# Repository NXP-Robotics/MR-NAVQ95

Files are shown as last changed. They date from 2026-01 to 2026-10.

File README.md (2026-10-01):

# NXP NavQ95 Vehicle Computer

Welcome to the documentation for the NavQ95, a vehicle computer reference design designed around the NXP i.MX95 developed by NXP Mobile Robotics. Please note that this board is currently a Proof of Concept only and is considered not supported by NXP.

The NavQ95 features a single main board with a small form factor and is designed to merge a Vehicle Management Unit and a Vehicle Companion Computer into one unified, heterogeneous MCU/MPU device.

> [!TIP]
> See [MR-NAVQ95/Mr Solutions MR-MR-NAVQ95-RevB description slides (Public).pdf](<https://github.com/NXP-Robotics/MR-NAVQ95/blob/main/Mr Solutions MR-NavQ95-RevB description slides (Public).pdf>) also for a short overview presentation.

MR-NavQ95 Top view     |  MR-NavQ95 Side View
:-------------------------:|:-------------------------:
  |  

# Core Architecture & AI

The heterogeneous vehicle computer is powered by the [NXP i.MX 95](https://www.nxp.com/products/i.MX95) processor and is divided into specific execution domains:
- **Compute**: 6x Arm Cortex-A55 cores dedicated to executing compute-intense functions.
- **Real-Time Control**: 1x Arm Cortex-M7 core to execute real-time control tasks.
- **System Management**: 1x Arm Cortex-M33 core to execute the NXP System Manager.

## AI Capabilities:

- Equipped with an on-chip NXP Neutron NPU.
- High-bandwidth M.2 PCIe interfaces target up to 2 [NXP Kinara Ara240 NPUs](https://www.nxp.com/products/ARA240).
- Supports cloud-based AI via Wifi6 or 5G connectivity

## Software Stack:

The board is designed to run open-source software, leveraging its multi-core architecture:

- Cortex-A55 Cores: Runs the Ubuntu PoC image 24.04 with ROS2 Jazzy.
> [!NOTE]
> This is an open Proof of Concept (POC) design and is not officially supported by NXP.
> The design is enabled with a Vanilla Ubuntu POC layered on top of existing NXP Yocto build.
> This means ROS2 main installs via `apt install ros2`.
>
> The unsupported software repo can be found here: https://github.com/NXP-Robotics/imx-manifest-navq95
- Cortex-M7 Core: Runs either Zephyr / CogniPilot or NuttX / PX4.
- Communication: High-speed inter-core communication is facilitated using shared memory / OpenAMP RpMsg.

### Cortex-M7 realtime software
A range of software platforms can be deployed on the Cortex-M7 core. The following software platforms have been prepared for use with the MR‑NAVQ95:
- Zephyr
  - https://www.zephyrproject.org/
  - https://github.com/CogniPilot/zephyr_boards/
- CogniPilot Cerebri (Zephyr based)
  - https://CogniPilot.org/
- NuttX
  - https://NuttX.apache.org/
  - https://NuttX.apache.org/docs/latest/platforms/arm/imx9/boards/mr-navq95b/index.html
- PX4 Autopilot (NuttX based)
  - https://px4.io/

## Hardware Specifications

### Power and Memory
* **Input Power:** Supports an operating voltage range of 9V to 52V, with a maximum limit of 60V. This easily accommodates 3S to 12S battery configurations, delivering 60W across the 9-20V (3-7S) range, and stepping up to 125W for the 20-52V (8-12S) range.
* **RAM:** Up to 16 GB of LPDDR5 memory.
* **Storage Options:** 64 GB onboard eMMC, an Octal-SPI Flash module, a Micro SD card reader, and PCIe M.2 support for solid-state drives.

### Connectivity
* **Standard Ethernet:** One Gigabit RJ45 port supporting Precision Time Protocol (PTP).
* **Automotive Ethernet:** Both 100BASE-T1 and 1000BASE-T1 ports, also featuring PTP.
> [!TIP]
> 100(0)BASE-T1 is Ethernet over single unshielded twisted pair
* **Wireless Comms:** Powered by the NXP IW612 chip for Wi-Fi, Bluetooth, and Matter support.
* **Cellular Data:** Includes a SIM slot and an M.2 PCIe interface meant for a cellular modem.

### Onboard Mobile Robotics Sensors
* TDK ICM-45686 Inertial Measurement Unit (IMU)
* Bosch BMM350 Magnetometer
* Bosch BMP581 Barometer

### Physical Interfaces
* USB 2.0 and 3.0 ports.
* Two PCIe M.2 slots (Type M and Type B).
* A 10-pin JTAG SWD debugging header.

## Main Board Schematics

The MR-NAVQ95 Main Board serves as the central processing and power distribution hub for the platform. It handles the core i.MX95 compute, wide-input power delivery, and routing to all board-to-board and high-speed interfaces. 

For detailed component layouts, pin configurations, and electrical routing, refer to the core system schematics:
* [NAVQ95-MAIN](Schematic/SPF-97010_A1-MAIN.pdf)

## Expansion Capabilities

Building upon this core Main Board, the system is highly adaptable thanks to support for modular add-on boards:

**XGMII-based Networking expansion boards:** 
* [NAVQ95-T1SW](Schematic/SPF-97011_A1-T1SW.pdf): T1 Switch utilizing the NXP SJA1110 for six 100BASE-T1 connections and 2x 1000BASE-T1.
* [X-MR-NAVQ95E-T1P](Schematic/Prototypes/Schematic-Rev-A/SPF-96098_A-T1PHY.pdf): T1 Single Phy setup using the NXP TJA1103.

**CSI/DSI Vision / Camera expansion board:** 
* [NAVQ95-CAMRP](Schematic/SPF-97012_A1-CAMRP.pdf): A 22-pin Raspberry Pi-style connector expansion board for CSI/DSI interfaces.

**General purpose I/O expansion board:**
* [NAVQ95-IO](Schematic/SPF-97013_A1-IO.pdf): Drone & Rover IO: Uses standard Dronecode connectors for extensive peripheral support:
    * 3x CAN-FD
    * Bosch BMI088 IMU
    * 8x FlexIO/PWM output
    * Dronecode JST-GH 10-pin GPS connector
    * Dronecode JST-GH 6-pin Telemetry connector
    * Dronecode JST-GH 4-pin I2C connector
    * WM8962B Audio codec with:
        * Audio jack
        * 2x PDM Microphones
        * 2x 1W stereo output
    * 2x UART to USB-C for Serial Console

## MR-NAVQ95 hardware connector reference

Each card shows three things per pin: the **function**, the **net name in the schematic** and the
**i.MX95 pad** the signal ends up on. Parts in between, such as transceivers, level shifters and
I/O expanders, are shown too. Pin 1 is the square pad.

## Board overview

<!-- overview:top -->
<picture>
  <source media="(prefers-color-scheme: dark)" srcset="images/overview-top-dark.svg">
  MR-NAVQ95 top view with connector callouts
</picture>
<!-- /overview -->

<!-- overview-list:top -->
Not visible here: [J13 USB1](#main-other-connectors) (bottom view) · [J12 USB2](#main-other-connectors) (bottom view) · [J16 M.2 KEY B](#main-j16-m2-key-b) (bottom and front view) · [J7 DEBUG](#main-j7-debug) (front view) · [J6 MICROSD](#main-other-connectors) (front view) · [J11 RTC_BAT](#main-j11-rtc_bat) (not visible in the photos) · [SW2 BTMODE](#buttons-and-switches) (top side, under the M.2 Key M module)
<!-- /overview-list -->

> [!NOTE]
> The boot-mode switch (SW2) is explained in the
> [imx-manifest-navq95 README](https://github.com/NXP-Robotics/imx-manifest-navq95#power-up-navq95).

Front view. The JST-GH connectors of the IO board are on top. Below them, on the edge of the
main board, are the debug header, the microSD slot, the SIM holder and the M.2 Key B slot:

<!-- overview:side -->
<picture>
  <source media="(prefers-color-scheme: dark)" srcset="images/overview-side-dark.svg">
  MR-NAVQ95 front view: IO board connectors, debug header, microSD and audio jack
</picture>
<!-- /overview -->

Bottom side. In this photo the T1 Ethernet switch board and two camera boards are fitted. The
left camera board is on the CSI_B2B port, the right one on the DSICSI_B2B port; only the
DSICSI_B2B port can also drive an RPi DSI display. PORT1 to PORT10 are the switch ports:

<!-- overview:bottom -->
<picture>
  <source media="(prefers-color-scheme: dark)" srcset="images/overview-bottom-dark.svg">
  MR-NAVQ95 bottom view with connector callouts
</picture>
<!-- /overview -->

<!-- overview-list:bottom -->

<!-- /overview-list -->

## Connector index

<!-- index -->
| Ref | Function | Connector | Details |
|---|---|---|---|
| [Main J1](#main-j1-m2-key-m) M.2 KEY M | M.2 Key M slot, PCIe x1 (NPU or NVMe SSD) | M.2 Socket 3 Key M, 2242 / 2280 standoffs, 3.3 V up to 3.5 A |  |
| [Main J2](#main-j2-console) CONSOLE | UART1 (Linux console) and UART2 (M7 console) header, DS-009 TELEM layout | JST-GH 1x6 (SM06B-GHS-TB) |  |
| [Main J3](#main-other-connectors) B2B | Board-to-board expansion headers | Board-to-board headers | J3/J4 B2B_IO1/IO2 (2x25) for the IO board, J14/J15 B2B_CSI/DSICSI (2x20) for the camera boards, J17 B2B_ETH (2x25) for the T1 boards. Pin lists are on schematic page 25. |
| [Main J5](#main-j5-sim) SIM | SIM card holder for the Key B modem slot | SIM card holder, 6 contacts + card-detect switch, bottom side |  |
| [Main J6](#main-other-connectors) MICROSD | microSD card slot (USDHC2) | microSD push-push, bottom side | USDHC2. The board can boot from it when the boot-mode switch selects SD. |
| [Main J7](#main-j7-debug) DEBUG | SWD / JTAG debug header (Arm Cortex 10-pin) | 2x5 1.27 mm (Samtec SHF-105-01-L-D-RA) |  |
| [Main J8](#main-other-connectors) ENET1 | Gigabit Ethernet with PTP | RJ45 with magnetics (Abracon ARJM11D7) | RTL8211 PHY on i.MX95 ENET1, supports IEEE 1588 PTP. |
| [Main J9](#main-j9-pwr_in) PWR_IN | Power input 9-52 V (3S-12S battery) | Molex Micro-Fit 3.0 2-pin (0430450222) |  |
| [Main J11](#main-j11-rtc_bat) RTC_BAT | RTC backup battery (rechargeable ML2020, RPi 5 compatible) | JST-SH 1.0 mm 2-pin (SM02B-SRSS-TB), top entry |  |
| [Main J12](#main-other-connectors) USB2 | USB 2.0 Type-C host port | USB Type-C receptacle, bottom side | Host port. 5 V VBUS through an NX20P0477 load switch with over-current protection. |
| [Main J13](#main-other-connectors) USB1 | USB 3.0 Type-C, serial download / device port | USB Type-C receptacle, bottom side | Serial-download port of the i.MX95 boot ROM and the port the NavQ95 flasher uses. USB 3.0 and USB 2.0 are both connected. |
| [Main J16](#main-j16-m2-key-b) M.2 KEY B | M.2 Key B slot, PCIe x1 with SIM (cellular modem) | M.2 Socket 2 Key B / B+M, 2242 / 3042 / 3052 standoffs, bottom side, 3.3 V up to 5 A |  |
| [Main J18](#main-other-connectors) ANT0/ANT1 | Wi-Fi 6 / Bluetooth antennas (IW612), ANT0 = J18, ANT1 = J19 | 2x U.FL | ANT0 = J18, ANT1 = J19. IW612 Wi-Fi 6, Bluetooth and 802.15.4. |
| [IO J1](#io-j1-console) CONSOLE | USB-C console: CP2105 bridge, UART1 = Linux, UART2 = M7 | USB Type-C receptacle (USB 2.0 device) |  |
| [IO J2](#io-j2-spkr) SPKR | Stereo speaker output (WM8962B class-D, 2x 1 W) | JST-PH 2.0 mm 1x4 |  |
| [IO J3](#io-j3-can3) CAN3 | CAN FD 3 (TJA1463) | JST-GH 1x4, side entry |  |
| [IO J4](#io-j4-can2) CAN2 | CAN FD 2 (TJA1463) | JST-GH 1x4, side entry |  |
| [IO J5](#io-j5-can1) CAN1 | CAN FD 1 (TJA1463) | JST-GH 1x4, side entry |  |
| [IO J6](#io-j6-telem) TELEM | Telemetry UART7 with flow control | JST-GH 1x6, top entry |  |
| [IO J7](#io-j7-i2c) I2C | I2C6 peripheral connector | JST-GH 1x4, top entry |  |
| [IO J8](#io-j8-gps) GPS | GPS: UART5, I2C6, safety switch, LED, buzzer | JST-GH 1x10, side entry |  |
| [IO J9](#io-j9-pwm) PWM | 8x PWM / timer outputs (TPM3 to TPM6), also usable as FlexIO1 pins | JST-GH 1x10, side entry |  |
| [IO J12](#io-j12-audio) AUDIO | 3.5 mm headset jack, CTIA wiring (WM8962B headphone out + microphone in) | 3.5 mm 4-pole TRRS jack with insertion switch, board underside |  |
| [CAM J3](#cam-j3-csi) CSI | MIPI CSI-2 camera, 4 data lanes, RPi camera compatible | 22-pin 0.5 mm FPC/FFC, contacts away from the PCB |  |
| [CAM J4](#cam-j4-5v) 5V | 5 V header for a display (not fitted) | 1x3 2.54 mm right-angle header, not fitted |  |
| [T1S J2](#t1s-ports-and-headers) DEBUG | Debug header of the SJA1110 (Arm Cortex-M7 inside the switch) | 2x5 1.27 mm | Not the i.MX95 debug port; that is J7 on the main board. |
| [T1S J3](#t1s-ports-and-headers) PORT2 | 1000BASE-T1 port 2 | Single-pair automotive connector | TJA1120 PHY on SJA1110 SGMII port 2. |
| [T1S J4](#t1s-ports-and-headers) PORT1 | 1000BASE-T1 port 1 | Single-pair automotive connector | TJA1120 PHY on SJA1110 SGMII port 1. |
| [T1S J5](#t1s-ports-and-headers) PORT5 | 100BASE-T1 port 5 | 2-pin single-pair connector | SJA1110 internal 100BASE-T1 PHY, switch port 5. |
| [T1S J6](#t1s-ports-and-headers) PORT6 | 100BASE-T1 port 6 | 2-pin single-pair connector | SJA1110 internal 100BASE-T1 PHY, switch port 6. |
| [T1S J7](#t1s-ports-and-headers) PORT7 | 100BASE-T1 port 7 | 2-pin single-pair connector | SJA1110 internal 100BASE-T1 PHY, switch port 7. |
| [T1S J8](#t1s-ports-and-headers) PORT8 | 100BASE-T1 port 8 | 2-pin single-pair connector | SJA1110 internal 100BASE-T1 PHY, switch port 8. |
| [T1S J9](#t1s-ports-and-headers) PORT9 | 100BASE-T1 port 9 | 2-pin single-pair connector | SJA1110 internal 100BASE-T1 PHY, switch port 9. |
| [T1S J10](#t1s-ports-and-headers) PORT10 | 100BASE-T1 port 10 | 2-pin single-pair connector | SJA1110 internal 100BASE-T1 PHY, switch port 10. |
<!-- /index -->

## Main board

<!-- heading:main/J9 -->
### Main J9 PWR_IN
<!-- /heading -->

<!-- pinout:main/J9 -->
<picture>
  <source media="(prefers-color-scheme: dark)" srcset="images/main-J9-dark.svg">
  Main J9 PWR_IN pinout
</picture>

Pin 1 (BATT +) is the lower pin on the board. Input 9 to 52 V, never more than 60 V. The board can draw 60 W between 9 and 20 V, and 125 W between 20 and 52 V. The input voltage is measured on ADC_IN0 (VIN / 64).
<!-- /pinout -->

<!-- heading:main/J2 -->
### Main J2 CONSOLE
<!-- /heading -->

<!-- pinout:main/J2 -->
<picture>
  <source media="(prefers-color-scheme: dark)" srcset="images/main-J2-dark.svg">
  Main J2 CONSOLE pinout
</picture>

Pins 2 to 5 follow the DS-009 TELEM layout for UART1: 2 = TX, 3 = RX, 4 = CTS, 5 = RTS. By default pin 4 carries UART2 RX and pin 5 UART2 TX (the M7 console). The same pads can be muxed to UART1 CTS and RTS instead, which gives UART1 full DS-009 flow control on this header. UART1 TX and UART2 TX are also the boot-mode straps BT_MODE0 and BT_MODE1. The same two UARTs are also on the USB console port J10 of the IO board, see the figure there.

> [!NOTE]
> UART1 TX and UART2 TX are boot straps. Keep them idle while the board resets, or it may boot from the wrong source.
<!-- /pinout -->

<!-- heading:main/J7 -->
### Main J7 DEBUG
<!-- /heading -->

<!-- pinout:main/J7 -->
<picture>
  <source media="(prefers-color-scheme: dark)" srcset="images/main-J7-dark.svg">
  Main J7 DEBUG pinout
</picture>

Standard Arm Cortex 10-pin layout (0.05 inch). Works with J-Link, PyOCD, CMSIS-DAP and similar probes. nRESET goes through a diode to SYS_RST_B, so the probe can only pull it low.

> [!NOTE]
> VTref is 1.8 V. Use a debug probe that supports 1.8 V targets.
<!-- /pinout -->

<!-- heading:main/J1 -->
### Main J1 M.2 KEY M
<!-- /heading -->

<!-- pinout:main/J1 -->
<picture>
  <source media="(prefers-color-scheme: dark)" srcset="images/main-J1-dark.svg">
  Main J1 M.2 KEY M pinout
</picture>

Only the pins below are connected. All other pins of the 75-pin socket are not used: PCIe lanes 1 to 3 (odd pins 5 to 37), SATA, DEVSLP, SUSCLK (pin 68, link resistor not fitted), MFG1/2 and the even pins 6 to 36. The 3.3 V comes through an NX20P5090 load switch that the I/O expander can switch off: 3.5 A continuous, 7 A peaks of 100 µs.

> [!NOTE]
> PCIe x1 only, no SATA. An NVMe SSD or NPU module works; a SATA M.2 drive does not.
<!-- /pinout -->

<!-- heading:main/J16 -->
### Main J16 M.2 KEY B
<!-- /heading -->

<!-- pinout:main/J16 -->
<picture>
  <source media="(prefers-color-scheme: dark)" srcset="images/main-J16-dark.svg">
  Main J16 M.2 KEY B pinout
</picture>

Made for a PCIe cellular modem. The USB 2.0 pins (7, 9) and the USB 3.0 / lane 1 pins (29 to 37) are not connected. SMBus (40, 42, 44), SUSCLK (68) and the Bluetooth coexistence lines COEX1/2 (64, 62, to the IW612) are routed, but their link resistors are not fitted. ANTCTL0 to 3, COEX3, DPR, DEVSLP, GPIO_3/4/8 and MFG1/2 are not connected. The UIM pins go to the SIM holder J5. The 3.3 V comes through an NX20P5090 load switch that the I/O expander can switch off: 5 A continuous, 6 A peaks of 100 µs.

> [!IMPORTANT]
> Buying a 4G or 5G modem? Get one that runs over PCIe. This slot has no USB pins, so a USB modem stays silent. Many modems exist in a USB and a PCIe version with the same name: check the exact SKU or the manual.
<!-- /pinout -->

<!-- heading:main/J5 -->
### Main J5 SIM
<!-- /heading -->

<!-- pinout:main/J5 -->
<picture>
  <source media="(prefers-color-scheme: dark)" srcset="images/main-J5-dark.svg">
  Main J5 SIM pinout
</picture>

Connected directly to the UIM pins of the Key B slot. The modem supplies the SIM voltage on UIM_PWR. The card-detect switch pulls SIM_DETECT low when a card is inserted. All contacts have ESD protection.
<!-- /pinout -->

<!-- heading:main/J11 -->
### Main J11 RTC_BAT
<!-- /heading -->

<!-- pinout:main/J11 -->
<picture>
  <source media="(prefers-color-scheme: dark)" srcset="images/main-J11-dark.svg">
  Main J11 RTC_BAT pinout
</picture>

Keeps the PCF2131 real-time clock running while the board has no power. The battery is charged slowly from the 3.3 V rail. This suits a rechargeable ML2020 cell such as the [RPi RTC Battery](https://www.raspberrypi.com/products/rtc-battery/).

> [!WARNING]
> Use a rechargeable ML2020 cell only. A CR2032 or other non-rechargeable cell must not be fitted: the board tries to charge it.
<!-- /pinout -->

<!-- others:main -->
### Main other connectors

| Ref | Function | Connector | Notes |
|---|---|---|---|
| J13 USB1 | USB 3.0 Type-C, serial download / device port | USB Type-C receptacle, bottom side | Serial-download port of the i.MX95 boot ROM and the port the NavQ95 flasher uses. USB 3.0 and USB 2.0 are both connected. |
| J12 USB2 | USB 2.0 Type-C host port | USB Type-C receptacle, bottom side | Host port. 5 V VBUS through an NX20P0477 load switch with over-current protection. |
| J8 ENET1 | Gigabit Ethernet with PTP | RJ45 with magnetics (Abracon ARJM11D7) | RTL8211 PHY on i.MX95 ENET1, supports IEEE 1588 PTP. |
| J6 MICROSD | microSD card slot (USDHC2) | microSD push-push, bottom side | USDHC2. The board can boot from it when the boot-mode switch selects SD. |
| J18 ANT0/ANT1 | Wi-Fi 6 / Bluetooth antennas (IW612), ANT0 = J18, ANT1 = J19 | 2x U.FL | ANT0 = J18, ANT1 = J19. IW612 Wi-Fi 6, Bluetooth and 802.15.4. |
| J3 B2B | Board-to-board expansion headers | Board-to-board headers | J3/J4 B2B_IO1/IO2 (2x25) for the IO board, J14/J15 B2B_CSI/DSICSI (2x20) for the camera boards, J17 B2B_ETH (2x25) for the T1 boards. Pin lists are on schematic page 25. |
<!-- /others -->

## IO expansion board

<!-- heading:io/J1 -->
### IO J1 CONSOLE
<!-- /heading -->

<!-- notes:io/J1 -->
A Silicon Labs CP2105 gives two serial ports on one USB-C connection. On a Linux host they appear as ttyUSB0 (UART1, Linux console) and ttyUSB1 (UART2, M7 console). RX and TX LEDs for both UARTs sit next to the connector. The same two UARTs also go to the J2 header on the main board, see the figure below.

> [!NOTE]
> Port 1 (ECI) is the Linux console, port 2 (SCI) is the M7 console. Do not let the host drive the TX lines while the board resets.
<!-- /notes -->

<!-- figure:console-shared -->
<picture>
  <source media="(prefers-color-scheme: dark)" srcset="images/figure-console-shared-dark.svg">
  UART1 and UART2 are shared between the J2 header and the CP2105 USB bridge
</picture>
<!-- /figure -->

<!-- heading:io/J6 -->
### IO J6 TELEM
<!-- /heading -->

<!-- pinout:io/J6 -->
<picture>
  <source media="(prefers-color-scheme: dark)" srcset="images/io-J6-dark.svg">
  IO J6 TELEM pinout
</picture>

The 5 V output is filtered (VDD_CON_UART_5V0) and has ESD protection.
<!-- /pinout -->

<!-- heading:io/J8 -->
### IO J8 GPS
<!-- /heading -->

<!-- pinout:io/J8 -->
<picture>
  <source media="(prefers-color-scheme: dark)" srcset="images/io-J8-dark.svg">
  IO J8 GPS pinout
</picture>

Standard DS-009 GPS and compass connector. The safety switch input (ARM_IO) is also wired to the ARM button SW1 on the board, and the LED output drives the LED in the switch. The buzzer pin is switched by an N-FET (AO3400A) driven from TPM6_CH1. A buzzer on the board is connected in parallel. DIP switch S1 sits between TPM6_CH1 and the FET: with S1 OFF both buzzers are disconnected and TPM6_CH1 is free for PWM8 on the PWM header.
<!-- /pinout -->

<!-- heading:io/J7 -->
### IO J7 I2C
<!-- /heading -->

<!-- pinout:io/J7 -->
<picture>
  <source media="(prefers-color-scheme: dark)" srcset="images/io-J7-dark.svg">
  IO J7 I2C pinout
</picture>

Same I2C6 bus as the GPS connector.
<!-- /pinout -->

<!-- heading:io/J9 -->
### IO J9 PWM
<!-- /heading -->

<!-- pinout:io/J9 -->
<picture>
  <source media="(prefers-color-scheme: dark)" srcset="images/io-J9-dark.svg">
  IO J9 PWM pinout
</picture>

Pin 1 (VDD_CON_PWM) is the servo power rail. It is linked to the board 5 V through R60 (0 Ω, not fitted) and measured on ADC_IN6 (VDD_CON_PWM / 8, up to 12 V). The outputs are 3.3 V logic with ESD protection. PWM8 (pin 9) also drives the buzzer. Every output pad can also be muxed to FlexIO1, for example for DShot or other custom timing protocols. Pins 2 and 5 can also be CAN4 or LPUART6 (TX and RX), pins 8 and 9 CAN5 or LPI2C5 (no pull-ups on the board). CAN4 and CAN5 need an external transceiver.

> [!WARNING]
> Do not put more than 5 V on the servo rail (pin 1) while R60 is fitted.

> [!TIP]
> Need all eight PWM outputs? Switch DIP switch S1 (BUZZER) off. It frees PWM8 from the buzzer.
<!-- /pinout -->

<!-- heading:io/J5 -->
### IO J5 CAN1
<!-- /heading -->

<!-- pinout:io/J5 -->
<picture>
  <source media="(prefers-color-scheme: dark)" srcset="images/io-J5-dark.svg">
  IO J5 CAN1 pinout
</picture>

TJA1463 CAN FD transceiver with 5 V supply. The 120 Ω split termination is on the board, so each CAN port is a bus end. CANH and CANL together form the differential bus. TXD and RXD are the logic pins of the transceiver and go to the FlexCAN pads of the i.MX95. The transceiver enable and standby pins are controlled through the PCAL6524 I/O expander.
<!-- /pinout -->

<!-- heading:io/J4 -->
### IO J4 CAN2
<!-- /heading -->

<!-- pinout:io/J4 -->
<picture>
  <source media="(prefers-color-scheme: dark)" srcset="images/io-J4-dark.svg">
  IO J4 CAN2 pinout
</picture>

Same circuit as CAN1, with the 120 Ω termination.
<!-- /pinout -->

<!-- heading:io/J3 -->
### IO J3 CAN3
<!-- /heading -->

<!-- pinout:io/J3 -->
<picture>
  <source media="(prefers-color-scheme: dark)" srcset="images/io-J3-dark.svg">
  IO J3 CAN3 pinout
</picture>

Same circuit as CAN1, with the 120 Ω termination.
<!-- /pinout -->

<!-- heading:io/J12 -->
### IO J12 AUDIO
<!-- /heading -->

<!-- pinout:io/J12 -->
<picture>
  <source media="(prefers-color-scheme: dark)" srcset="images/io-J12-dark.svg">
  IO J12 AUDIO pinout
</picture>

Plug contacts listed from tip to sleeve. The switch in the jack drives HP_JD: high with a plug inserted, low without. The codec uses it to detect the plug. The headphone ground reference is the HP_FB sense line of the codec.

> [!NOTE]
> CTIA wiring only. OMTP headsets (microphone and ground swapped) do not work.
<!-- /pinout -->

<!-- heading:io/J2 -->
### IO J2 SPKR
<!-- /heading -->

<!-- pinout:io/J2 -->
<picture>
  <source media="(prefers-color-scheme: dark)" srcset="images/io-J2-dark.svg">
  IO J2 SPKR pinout
</picture>

Bridge-tied class-D outputs of the WM8962B codec. The 4-pin JST-PH plug of the [Adafruit 1669 Stereo Enclosed Speaker Set](https://www.adafruit.com/product/1669) (2x 3 W, 4 Ω) fits directly. J25 next to it is the headset jack; the board also has two PDM microphones.

> [!CAUTION]
> No GND on this connector. Each speaker goes between its − and + pin. Never connect a speaker pin to ground.
<!-- /pinout -->

<!-- others:io -->

<!-- /others -->

## Buttons and switches

<!-- switches -->
| Ref | Board | Function | Type | Notes |
|---|---|---|---|---|
| SW1 SYS_RST | Main | System reset button (short press: reset) | Tactile switch, right of the ON/OFF button, hidden under the thermal pad in the photo | Resets the whole board. |
| SW2 BTMODE | Main | Boot mode DIP switch | 4-position DIP switch, top side under the M.2 Key M module | See [Power up NavQ95](https://github.com/NXP-Robotics/imx-manifest-navq95#power-up-navq95). |
| SW3 ONOFF | Main | Power button (short press: on, 5 s press: off) | Tactile switch, left of the reset button | Talks to the PMIC ONOFF input. |
| S1 BUZZER | IO | Buzzer enable DIP switch | 1-position DIP switch (CHS-01TA1), next to the ARM button | ON connects TPM6_CH1 to the buzzer FET. OFF disconnects the buzzer and the GPS buzzer pin, so PWM8 on the PWM header is a free channel. |
| SW1 ARM | IO | Arm / safety switch with LED | Tactile switch | Wired in parallel with the safety-switch and LED pins of the GPS connector. |
| S1 SMI | T1S | SMI routing switch | 1-position DIP switch (CHS-01TA1) | Leave as delivered. Only used when the SJA1110 runs without the host. |
| S2 BOOT_OPT | T1S | SJA1110 boot option switch | 2-position DIP switch | Boot option of the SJA1110; see the SJA1110 documentation before changing it. |
<!-- /switches -->

## Camera expansion board

<!-- heading:cam/J3 -->
### CAM J3 CSI
<!-- /heading -->

<!-- pinout:cam/J3 -->
<picture>
  <source media="(prefers-color-scheme: dark)" srcset="images/cam-J3-dark.svg">
  CAM J3 CSI pinout
</picture>

Pin-compatible with the 22-pin RPi camera connector (22-pin 0.5 mm same-side FFC). Two identical camera boards can be fitted. In the bottom view, the left one sits on CSI_B2B and goes to the i.MX95 MIPI_CSI1 port; the right one sits on DSICSI_B2B and goes to the second port, which is shared between DSI and CSI. The camera I2C is the i.MX95 I3C2 bus, shifted from 1.8 V to 3.3 V by a PCA9306. The two GPIO pins come from the I/O expander on the main board; the exact expander pins and the pad names of the second port were not traced. Whether a camera module works depends on the software image, not on the connector. J4 next to it is a 3-pin 5 V header for a display, not fitted.

> [!TIP]
> RPi camera modules fit directly with a standard 22-pin FFC. For an RPi DSI display use the camera board on the DSICSI_B2B port; the CSI_B2B port cannot drive a display.
<!-- /pinout -->

<!-- heading:cam/J4 -->
### CAM J4 5V
<!-- /heading -->

<!-- pinout:cam/J4 -->
<picture>
  <source media="(prefers-color-scheme: dark)" srcset="images/cam-J4-dark.svg">
  CAM J4 5V pinout
</picture>

Filtered 5 V from the system rail with ESD protection, meant for a DSI display on the DSICSI_B2B camera board. The silkscreen marks pin 1 as 5V.
<!-- /pinout -->

## T1 Ethernet switch board

The MR-NAVQ95E-T1S board is an NXP SJA1110 automotive Ethernet switch. It is connected to the
main board through B2B_ETH on SGMII port 4 of the switch (the host port). Ports 1 and 2 are
1000BASE-T1 through two TJA1120 PHYs on SGMII ports 1 and 2. Ports 5 to 10 are 100BASE-T1 on
the switch's own PHYs. SGMII port 3 is not used. The port numbers on the bottom view are the
switch port numbers, which also match the silkscreen.

<!-- others:t1s -->
### T1S ports and headers

| Ref | Function | Connector | Notes |
|---|---|---|---|
| J4 PORT1 | 1000BASE-T1 port 1 | Single-pair automotive connector | TJA1120 PHY on SJA1110 SGMII port 1. |
| J3 PORT2 | 1000BASE-T1 port 2 | Single-pair automotive connector | TJA1120 PHY on SJA1110 SGMII port 2. |
| J5 PORT5 | 100BASE-T1 port 5 | 2-pin single-pair connector | SJA1110 internal 100BASE-T1 PHY, switch port 5. |
| J6 PORT6 | 100BASE-T1 port 6 | 2-pin single-pair connector | SJA1110 internal 100BASE-T1 PHY, switch port 6. |
| J7 PORT7 | 100BASE-T1 port 7 | 2-pin single-pair connector | SJA1110 internal 100BASE-T1 PHY, switch port 7. |
| J8 PORT8 | 100BASE-T1 port 8 | 2-pin single-pair connector | SJA1110 internal 100BASE-T1 PHY, switch port 8. |
| J9 PORT9 | 100BASE-T1 port 9 | 2-pin single-pair connector | SJA1110 internal 100BASE-T1 PHY, switch port 9. |
| J10 PORT10 | 100BASE-T1 port 10 | 2-pin single-pair connector | SJA1110 internal 100BASE-T1 PHY, switch port 10. |
| J2 DEBUG | Debug header of the SJA1110 (Arm Cortex-M7 inside the switch) | 2x5 1.27 mm | Not the i.MX95 debug port; that is J7 on the main board. |
<!-- /others -->

## Notes

- The connectors marked DS-009 on their card (TELEM, GPS, I2C, CAN and the J2 console header)
  follow the Dronecode
  [DS-009 connector standard](https://github.com/pixhawk/Pixhawk-Standards/blob/master/DS-009%20Pixhawk%20Connector%20Standard.pdf),
  so standard cables fit. The other JST-GH connectors, such as the PWM header, have their own pin order.
- Input 9 to 52 V (never more than 60 V), 3S to 12S batteries. 60 W between 9 and 20 V, 125 W between 20 and 52 V.
- The 5 V pin of every JST-GH connector is a filtered, ESD-protected output of the 5 V system rail
  (`VDD_CON_*_5V0` nets).
- The servo rail of the PWM connector (`VDD_CON_PWM`) is separated from the 5 V rail by R60, a
  0 Ω link that is not fitted. This allows an external servo supply. The rail is measured on ADC_IN6
  and must stay below 12 V.
- VIN, 5 V and 3.3 V are measured on ADC_IN0, ADC_IN1 and ADC_IN2.

> [!WARNING]
> Never feed power into a 5 V pin of a JST-GH connector. They are outputs. Power the board through J9 PWR_IN only.

## Downloads

This reference as an [A4 PDF](MR-NAVQ95-hardware-reference.pdf), and all cards on one
double-sided A4 landscape sheet: [cheat sheet PDF](MR-NAVQ95-cheatsheet.pdf).

Note: NXP and the NXP logo are registered trademarks of NXP B.V.

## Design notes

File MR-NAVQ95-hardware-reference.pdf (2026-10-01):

Connectors and pinouts of the NXP MR-NAVQ95 vehicle computer (main board) and its expansion boards. All data comes from the

public schematics in the MR-NAVQ95 repository, (https://github.com/NXP-Robotics/MR-NAVQ95) production revision A1: main board, (https://github.com/NXP-Robotics/MR-NAVQ95/blob/main/Schematic/SPF-97010_A1-MAIN.pdf) IO board, (https://github.com/NXP-Robotics/MR-NAVQ95/blob/main/Schematic/SPF-97013_A1-IO.pdf) camera board (https://github.com/NXP-Robotics/MR-NAVQ95/blob/main/Schematic/SPF-97012_A1-CAMRP.pdf) and T1 switch board. (https://github.com/NXP-Robotics/MR-NAVQ95/blob/main/Schematic/SPF-97011_A1-T1SW.pdf)

### Note

The boot-mode switch (SW2) is explained in the imx-manifest-navq95 README. (https://github.com/NXP-Robotics/imx-manifest-navq95#power-up-navq95)

Each card shows three things per pin: the function, the net name in the schematic and the i.MX95 pad the signal ends up on. Parts

in between, such as transceivers, level shifters and I/O expanders, are shown too. Pin 1 is the square pad.

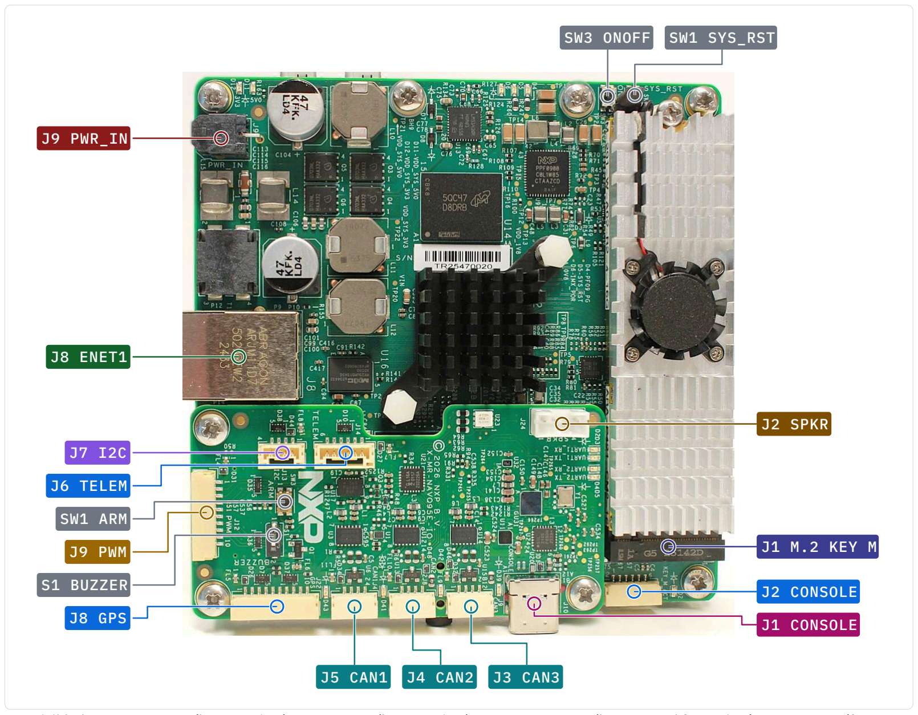
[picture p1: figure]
J9 PWR_IN; J8 ENET1; J6 TELEM; SW1 ARM; J9 PWM; S1 BUZZER; J8 GPS; J2 SPKR; J1 M.2 KEY M; J2 CONSOLE; J1 CONSOLE; SW3 ONOFF SW1 SYS_RST; J5 CAN1 J4 CAN2 J3 CAN3

Not visible here: J13 USB1 (bottom view) · J12 USB2 (bottom view) · J16 M.2 KEY B (bottom and front view) · J7 DEBUG (front

view) · J6 MICROSD (front view) · J11 RTC_BAT (not visible in the photos) · SW2 BTMODE (top side, under the M.2 Key M module)

Front view. The JST-GH connectors of the IO board are on top. Below them, on the edge of the main board, are the debug header, the

microSD slot, the SIM holder and the M.2 Key B slot:

# MR-NAVQ95 hardware reference

# Board overview

## J9 PWR_IN

## J8 ENET1

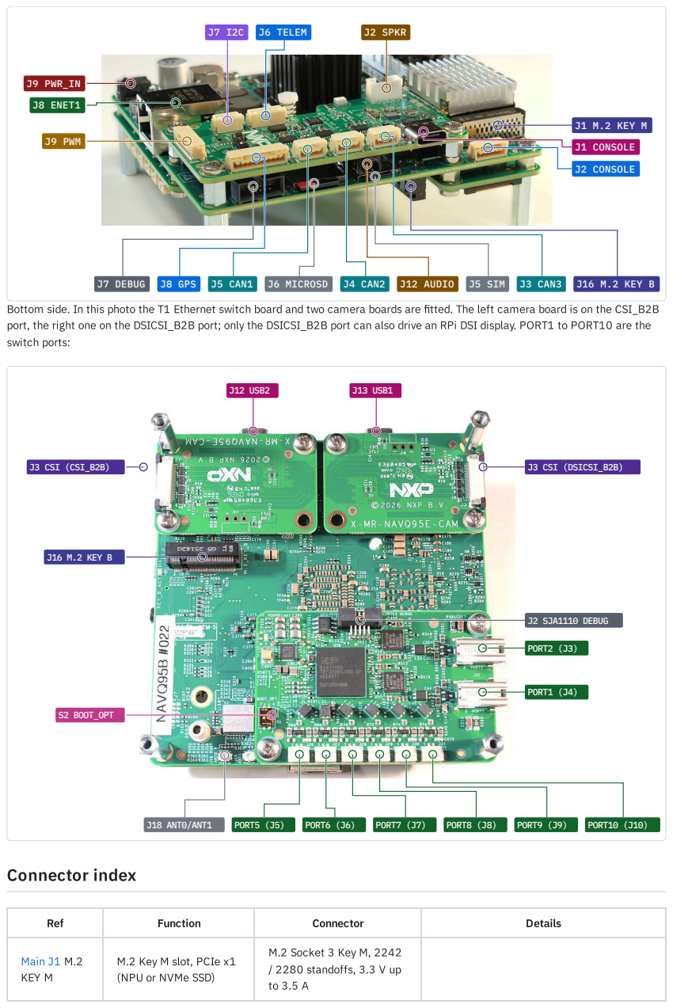
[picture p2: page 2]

Bottom side. In this photo the T1 Ethernet switch board and two camera boards are fitted. The left camera board is on the CSI_B2B
port, the right one on the DSICSI_B2B port; only the DSICSI_B2B port can also drive an RPi DSI display. PORT1 to PORT10 are the

Ref | Function | Connector | Details

Main J1 M.2 KEY M | M.2 Key M slot, PCIe x1 (NPU or NVMe SSD) | M.2 Socket 3 Key M, 2242 / 2280 standoffs, 3.3 V up to 3.5 A

Ref | Function | Connector | Details
Main J2 CONSOLE | UART1 (Linux console) and UART2 (M7 console) header, DS-009 TELEM layout | JST-GH 1x6 (SM06B-GHS-TB)
Main J3 B2B | Board-to-board expansion headers | Board-to-board headers | J3/J4 B2B_IO1/IO2 (2x25) for the IO board, J14/J15 B2B_CSI/DSICSI (2x20) for the camera boards, J17 B2B_ETH (2x25) for the T1 boards. Pin lists are on schematic page 25.
Main J5 SIM | SIM card holder for the Key B modem slot | SIM card holder, 6 contacts + card-detect switch, bottom side
Main J6 MICROSD | microSD card slot (USDHC2) | microSD push-push, bottom side | USDHC2. The board can boot from it when the boot-mode switch selects SD.
Main J7 DEBUG | SWD / JTAG debug header (Arm Cortex 10-pin) | 2x5 1.27 mm (Samtec SHF-105-01-L-D-RA)
Main J8 ENET1 | Gigabit Ethernet with PTP | RJ45 with magnetics (Abracon ARJM11D7) | RTL8211 PHY on i.MX95 ENET1, supports IEEE 1588 PTP.
Main J9 PWR_IN | Power input 9-52 V (3S-12S battery) | Molex Micro-Fit 3.0 2-pin (0430450222)
Main J11 RTC_BAT | RTC backup battery (rechargeable ML2020, RPi 5 compatible) | JST-SH 1.0 mm 2-pin (SM02B-SRSS-TB), top entry
Main J12 USB2 | USB 2.0 Type-C host port | USB Type-C receptacle, bottom side | Host port. 5 V VBUS through an NX20P0477 load switch with over-current protection.
Main J13 USB1 | USB 3.0 Type-C, serial download / device port | USB Type-C receptacle, bottom side | Serial-download port of the i.MX95 boot ROM and the port the NavQ95 flasher uses. USB 3.0 and USB 2.0 are both connected.
Main J16 M.2 KEY B | M.2 Key B slot, PCIe x1 with SIM (cellular modem) | M.2 Socket 2 Key B / B+M, 2242 / 3042 / 3052 standoffs, bottom side, 3.3 V up to 5 A
Main J18 ANT0/ANT1 | Wi-Fi 6 / Bluetooth antennas (IW612), ANT0 = J18, ANT1 = J19 | 2x U.FL | ANT0 = J18, ANT1 = J19. IW612 Wi-Fi 6, Bluetooth and 802.15.4.
IO J1 CONSOLE | USB-C console: CP2105 bridge, UART1 = Linux, UART2 = M7 | USB Type-C receptacle (USB 2.0 device)
IO J2 SPKR | Stereo speaker output (WM8962B class-D, 2x 1 W) | JST-PH 2.0 mm 1x4
IO J3 CAN3 | CAN FD 3 (TJA1463) | JST-GH 1x4, side entry
IO J4 CAN2 | CAN FD 2 (TJA1463) | JST-GH 1x4, side entry

Ref | Function | Connector | Details
IO J5 CAN1 | CAN FD 1 (TJA1463) | JST-GH 1x4, side entry
IO J6 TELEM | Telemetry UART7 with flow control | JST-GH 1x6, top entry
IO J7 I2C | I2C6 peripheral connector | JST-GH 1x4, top entry
IO J8 GPS | GPS: UART5, I2C6, safety switch, LED, buzzer | JST-GH 1x10, side entry
IO J9 PWM | 8x PWM / timer outputs (TPM3 to TPM6), also usable as FlexIO1 pins | JST-GH 1x10, side entry
IO J12 AUDIO | 3.5 mm headset jack, CTIA wiring (WM8962B headphone out + microphone in) | 3.5 mm 4-pole TRRS jack with insertion switch, board underside
CAM J3 CSI | MIPI CSI-2 camera, 4 data lanes, RPi camera compatible | 22-pin 0.5 mm FPC/FFC, contacts away from the PCB
CAM J4 5V | 5 V header for a display (not fitted) | 1x3 2.54 mm right-angle header, not fitted
T1S J2 DEBUG | Debug header of the SJA1110 (Arm Cortex-M7 inside the switch) | 2x5 1.27 mm | Not the i.MX95 debug port; that is J7 on the main board.
T1S J3 PORT2 | 1000BASE-T1 port 2 | Single-pair automotive connector | TJA1120 PHY on SJA1110 SGMII port 2.
T1S J4 PORT1 | 1000BASE-T1 port 1 | Single-pair automotive connector | TJA1120 PHY on SJA1110 SGMII port 1.
T1S J5 PORT5 | 100BASE-T1 port 5 | 2-pin single-pair connector | SJA1110 internal 100BASE-T1 PHY, switch port 5.
T1S J6 PORT6 | 100BASE-T1 port 6 | 2-pin single-pair connector | SJA1110 internal 100BASE-T1 PHY, switch port 6.
T1S J7 PORT7 | 100BASE-T1 port 7 | 2-pin single-pair connector | SJA1110 internal 100BASE-T1 PHY, switch port 7.
T1S J8 PORT8 | 100BASE-T1 port 8 | 2-pin single-pair connector | SJA1110 internal 100BASE-T1 PHY, switch port 8.
T1S J9 PORT9 | 100BASE-T1 port 9 | 2-pin single-pair connector | SJA1110 internal 100BASE-T1 PHY, switch port 9.
T1S J10 PORT10 | 100BASE-T1 port 10 | 2-pin single-pair connector | SJA1110 internal 100BASE-T1 PHY, switch port 10.

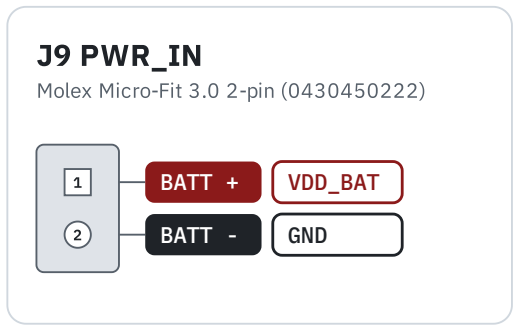
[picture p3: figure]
J9 PWR_IN; Molex Micro-Fit 3.0 2-pin (0430450222); BATT +; VDD_BAT; BATT -; GND

Pin 1 (BATT +) is the lower pin on the board. Input 9 to 52 V, never more than 60 V. The board can draw 60 W between 9 and 20 V,

and 125 W between 20 and 52 V. The input voltage is measured on ADC_IN0 (VIN / 64).

# J2 CONSOLE

JST-GH 1x6 (SM06B-GHS-TB) · DS-009 TELEM · 3.3 V logic

1 | 5V out | VDD_SYS_5V0
2 | UART1 TX | UART1_TXD/BT_MODE0 | | UART1_TXD
3 | UART1 RX | UART1_RXD | | UART1_RXD
4 | UART2 RX | UART2_RXD | LPUART1_CTS_B | UART2_RXD
5 | UART2 TX | UART2_TXD/BT_MODE1 | LPUART1_RTS_B | UART2_TXD
6 | GND

Pin 2: Linux console; boot strap BT_MODE0

Pin 4: M7 console by default; the pad can be muxed to UART1 CTS

Pin 5: M7 console by default; the pad can be muxed to UART1 RTS; boot strap BT_MODE1

Pins 2 to 5 follow the DS-009 TELEM layout for UART1: 2 = TX, 3 = RX, 4 = CTS, 5 = RTS. By default pin 4 carries UART2 RX and pin

5 UART2 TX (the M7 console). The same pads can be muxed to UART1 CTS and RTS instead, which gives UART1 full DS-009 flow

control on this header. UART1 TX and UART2 TX are also the boot-mode straps BT_MODE0 and BT_MODE1. The same two UARTs are

also on the USB console port J10 of the IO board, see the figure there.

### Note

UART1 TX and UART2 TX are boot straps. Keep them idle while the board resets, or it may boot from the wrong source.

# Main board

## Main J9 PWR_IN

## Main J2 CONSOLE

VDD_1V8 | VTref 1.8V | 1
| GND | 3

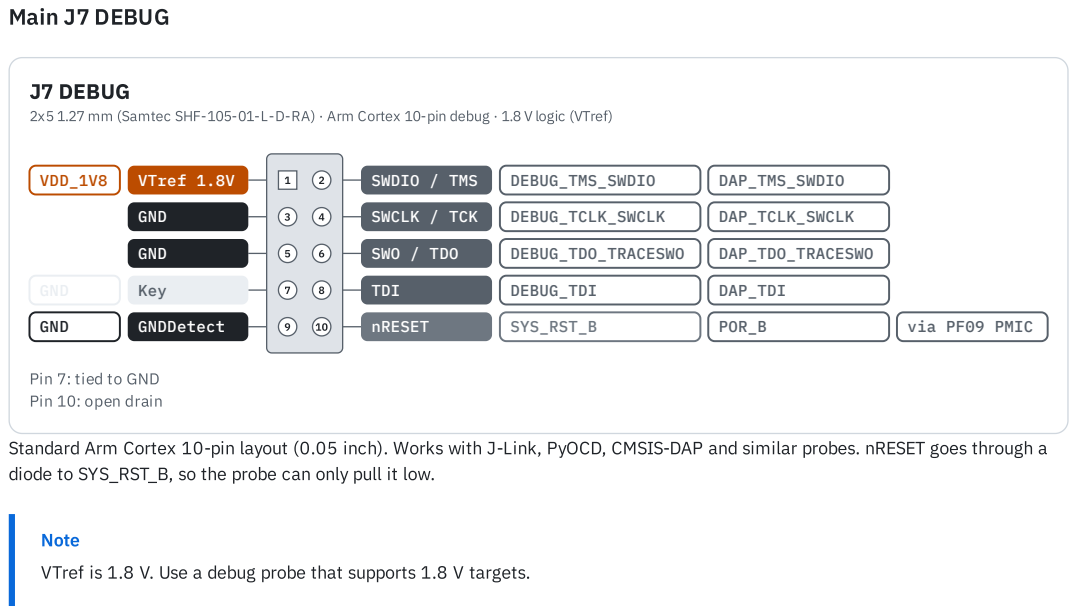
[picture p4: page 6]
J7 DEBUG; GND; Key; GNDDetect; SWDIO / TMS; DEBUG_TMS_SWDIO; DAP_TMS_SWDIO; SWCLK / TCK; DEBUG_TCLK_SWCLK; DAP_TCLK_SWCLK; SWO / TDO; DEBUG_TDO_TRACESWO; DAP_TDO_TRACESWO; TDI; DEBUG_TDI; DAP_TDI; nRESET; SYS_RST_B; POR_B; via PF09 PMIC; Note; Main J7 DEBUG

2x5 1.27 mm (Samtec SHF-105-01-L-D-RA) · Arm Cortex 10-pin debug · 1.8 V logic (VTref)

Pin 7: tied to GND
Pin 10: open drain

Standard Arm Cortex 10-pin layout (0.05 inch). Works with J-Link, PyOCD, CMSIS-DAP and similar probes. nRESET goes through a
diode to SYS_RST_B, so the probe can only pull it low.

VTref is 1.8 V. Use a debug probe that supports 1.8 V targets.

## J1 M.2 KEY M

M.2 Socket 3 Key M, 2242 / 2280 standoffs, 3.3 V up to 3.5 A· SMBus 1.8 V logic

J1

Main board

## PI6C clock buffer

100 MHz REFCLK

## PCAL6524

I/O expander (control pins)

## P3H2840 I3C hub

all marked pins

## i.MX95

SoC

PCIe x1: lane 0 only | No SATA
3V3 | 3.3 V ×9 | VDD_3V3_M2_KEYM
GND | GND ×11 | GND
10 | Activity LED | LED_GRN | drives the KEY_M_ACT LED
40 | SMBus CLK | M2_SMBUS_CLK
41 | PCIe RX0 − | PCIE1_RX0_N | PCIE1_RX0_N
42 | SMBus DATA | M2_SMBUS_DATA
43 | PCIe RX0 + | PCIE1_RX0_P | PCIE1_RX0_P
44 | SMBus ALERT# | M2_SMBUS_ALERT_B
47 | PCIe TX0 − | PCIE1_TX0_N | PCIE1_TX0_N
49 | PCIe TX0 + | PCIE1_TX0_P | PCIE1_TX0_P
50 | PERST# | M2_KEYM_PERST_B
52 | CLKREQ# | M2_KEYM_CLKREQ_B
53 | REFCLK − | M2_KEYM_REFCLK_N | 100 MHz
54 | PEWAKE# | M2_KEYM_PEWAKE_B
55 | REFCLK + | M2_KEYM_REFCLK_P | 100 MHz
69 | PEDET (card detect) | M2_KEYM_PEDET

3V3: pins 2, 4, 12, 14, 16, 18, 70, 72, 74

GND: pins 3, 9, 15, 27, 33, 39, 45, 51, 57, 71, 73

Only the pins below are connected. All other pins of the 75-pin socket are not used: PCIe lanes 1 to 3 (odd pins 5 to 37), SATA,

DEVSLP, SUSCLK (pin 68, link resistor not fitted), MFG1/2 and the even pins 6 to 36. The 3.3 V comes through an NX20P5090 load

switch that the I/O expander can switch off: 3.5 A continuous, 7 A peaks of 100 µs.

### Note

PCIe x1 only, no SATA. An NVMe SSD or NPU module works; a SATA M.2 drive does not.

## Main J1 M.2 KEY M

### J16 M.2 KEY B

M.2 Socket 2 KeyB / B+M, 2242 / 3042 / 3052 standoffs, bottom side, 3.3 V up to 5 A · GPIO, RESET# and SMBus 1.8 V logic

J16

Main board

## PI6C clock buffer

100 MHz REFCLK

## PCAL6524

I/O expander (control pins)

## SIM holder J5

all marked pins

## i.MX95

SoC

PCIe x1: lane 0 only | No USB: modem must be a PCIe model
3V3 | 3.3 V ×5 | VDD_3V3_M2_KEYB
GND | GND ×11 | GND
1 | CONFIG_3 | M2_KEYB_CONFIG3
6 | FCPO# | M2_KEYB_FCPO_B | full card power off
8 | W_DISABLE1# | M2_KEYB_WDISABLE1_B
10 | Activity LED | LED_GRN | drives the KEY_B_ACT LED
20 | GPIO_5 | M2_KEYB_GPIO5
21 | CONFIG_0 | M2_KEYB_CONFIG0
22 | GPIO_6 | M2_KEYB_GPIO6
23 | WAKE# | M2_KEYB_WOWWAN_B | wake on WWAN
24 | GPIO_7 | M2_KEYB_GPIO7
26 | W_DISABLE2# | M2_KEYB_WDISABLE2_B
30 | SIM RST | UIM_RESET
32 | SIM CLK | UIM_CLK
34 | SIM I/O | UIM_DATA
36 | SIM VCC | UIM_PWR | supplied by the module
41 | PCIe RX0 − | PCIE2_RX0_N | PCIE2_RX0_N
43 | PCIe RX0 + | PCIE2_RX0_P | PCIE2_RX0_P
47 | PCIe TX0 − | PCIE2_TX0_N | PCIE2_TX0_N
49 | PCIe TX0 + | PCIE2_TX0_P | PCIE2_TX0_P
50 | PERST# | M2_KEYB_PERST_B
52 | CLKREQ# | M2_KEYB_CLKREQ_B
53 | REFCLK − | M2_KEYB_REFCLK_N | 100 MHz
54 | PEWAKE# | M2_KEYB_PEWAKE_B
55 | REFCLK + | M2_KEYB_REFCLK_P | 100 MHz
66 | SIM_DETECT
67 | RESET# | M2_KEYB_RESET_B
69 | CONFIG_1 | M2_KEYB_CONFIG1
75 | CONFIG_2 | M2_KEYB_CONFIG2

3V3: pins 2, 4, 70, 72, 74

GND: pins 3, 5, 11, 27, 33, 39, 45, 51, 57, 71, 73

Made for a PCIe cellular modem. The USB 2.0 pins (7, 9) and the USB 3.0 / lane 1 pins (29 to 37) are not connected. SMBus (40,

42, 44), SUSCLK (68) and the Bluetooth coexistence lines COEX1/2 (64, 62, to the IW612) are routed, but their link resistors are

not fitted. ANTCTL0 to 3, COEX3, DPR, DEVSLP, GPIO_3/4/8 and MFG1/2 are not connected. The UIM pins go to the SIM holder J5.

The 3.3 V comes through an NX20P5090 load switch that the I/O expander can switch off: 5 A continuous, 6 A peaks of 100 µs.

### Important

## Main J16 M.2 KEY B

Buying a 4G or 5G modem? Get one that runs over PCIe. This slot has no USB pins, so a USB modem stays silent. Many

modems exist in a USB and a PCIe version with the same name: check the exact SKU or the manual.

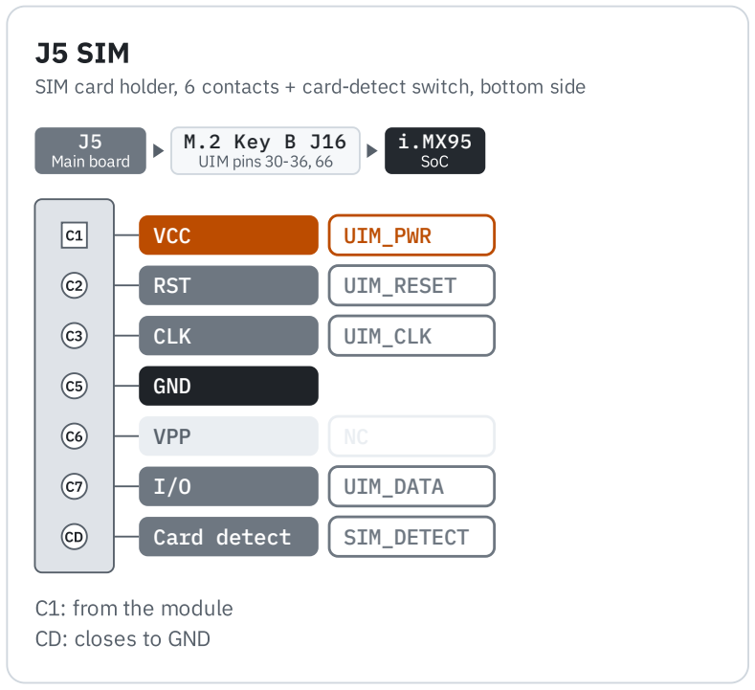
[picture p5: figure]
J5 SIM; Main board; M.2 Key B J16; UIM pins 30-36, 66; SoC; VCC; UIM_PWR; RST; UIM_RESET; CLK; UIM_CLK; GND; VPP; UIM_DATA; Card detect; SIM_DETECT; C1: from the module; CD: closes to GND

SIM card holder, 6 contacts + card-detect switch, bottom side

Connected directly to the UIM pins of the Key B slot. The modem supplies the SIM voltage on UIM_PWR. The card-detect switch

pulls SIM_DETECT low when a card is inserted. All contacts have ESD protection.

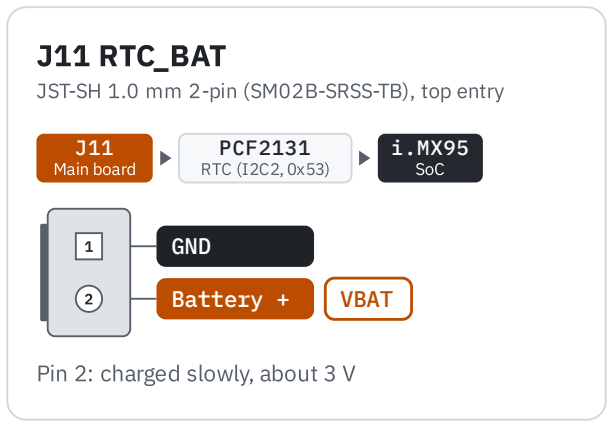
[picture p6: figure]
J11 RTC_BAT; Main board; PCF2131; RTC (I2C2, 0x53); SoC; GND; Battery +; VBAT; Pin 2: charged slowly, about 3 V

JST-SH 1.0 mm 2-pin (SM02B-SRSS-TB), top entry

Keeps the PCF2131 real-time clock running while the board has no power. The battery is charged slowly from the 3.3 V rail. This

suits a rechargeable ML2020 cell such as the RPi RTC Battery. (https://www.raspberrypi.com/products/rtc-battery/)

### Warning

Use a rechargeable ML2020 cell only. A CR2032 or other non-rechargeable cell must not be fitted: the board tries to charge

it.

## Main J5 SIM

## Main J11 RTC_BAT

Ref | Function | Connector | Notes
J13 USB1 | USB 3.0 Type-C, serial download / device port | USB Type-C receptacle, bottom side | Serial-download port of the i.MX95 boot ROM and the port the NavQ95 flasher uses. USB 3.0 and USB 2.0 are both connected.
J12 USB2 | USB 2.0 Type-C host port | USB Type-C receptacle, bottom side | Host port. 5 V VBUS through an NX20P0477 load switch with over-current protection.
J8 ENET1 | Gigabit Ethernet with PTP | RJ45 with magnetics (Abracon ARJM11D7) | RTL8211 PHY on i.MX95 ENET1, supports IEEE 1588 PTP.
J6 MICROSD | microSD card slot (USDHC2) | microSD push-push, bottom side | USDHC2. The board can boot from it when the boot-mode switch selects SD.
J18 ANT0/ANT1 | Wi-Fi 6 / Bluetooth antennas (IW612), ANT0 = J18, ANT1 = J19 | 2x U.FL | ANT0 = J18, ANT1 = J19. IW612 Wi-Fi 6, Bluetooth and 802.15.4.
J3 B2B | Board-to-board expansion headers | Board-to-board headers | J3/J4 B2B_IO1/IO2 (2x25) for the IO board, J14/J15 B2B_CSI/DSICSI (2x20) for the camera boards, J17 B2B_ETH (2x25) for the T1 boards. Pin lists are on schematic page 25.

A Silicon Labs CP2105 gives two serial ports on one USB-C connection. On a Linux host they appear as ttyUSB0 (UART1, Linux

console) and ttyUSB1 (UART2, M7 console). RX and TX LEDs for both UARTs sit next to the connector. The same two UARTs also go

to the J2 header on the main board, see the figure below.

### Note

Port 1 (ECI) is the Linux console, port 2 (SCI) is the M7 console. Do not let the host drive the TX lines while the board resets.

## Main other connectors

# IO expansion board

## IO J1 CONSOLE

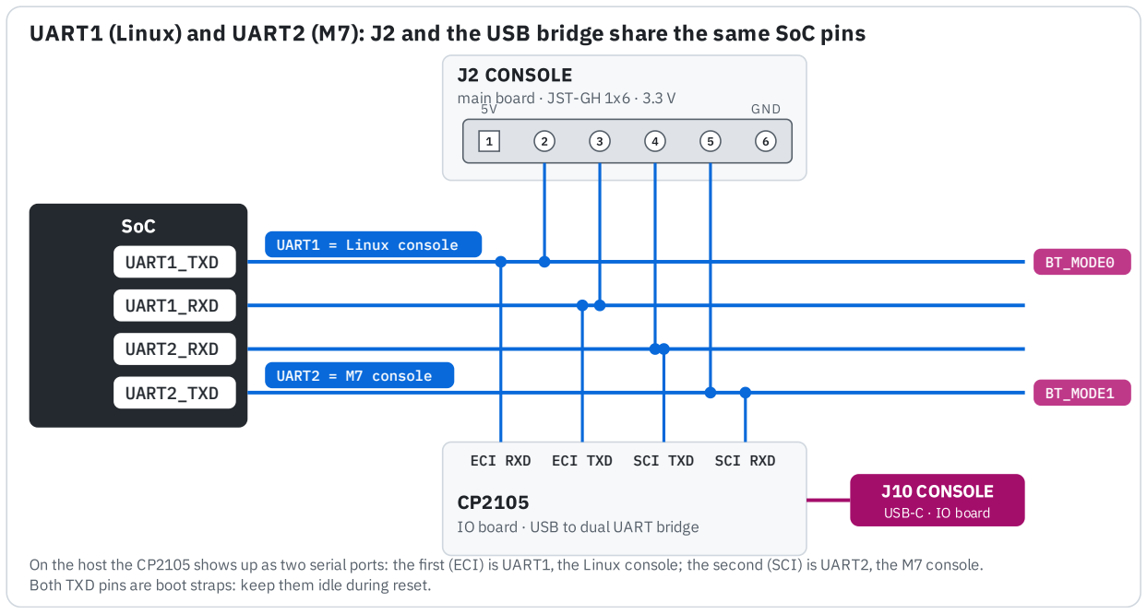
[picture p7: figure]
SoC UART1_TXD; UART1 = Linux console; BT_MODE0; UART1_RXD; UART2_RXD; UART2_TXD; UART2 = M7 console; BT_MODE1; J2 CONSOLE; main board · JST-GH 1x6 · 3.3 V; GND; IO board · USB to dual UART bridge; ECI RXD ECI TXD SCI TXD SCI RXD; J10 CONSOLE; USB-C · IO board

## UART1 (Linux) and UART2 (M7): J2 and the USB bridge share the same SoC pins

On the host the CP2105 shows up as two serial ports: the first (ECI) is UART1, the Linux console; the second (SCI) is UART2, the M7 console.

Both TXD pins are boot straps: keep them idle during reset.

# J6 TELEM

JST-GH 1x6, top entry · DS-009 TELEM · 3.3 V logic

1 | 5V out | VDD_CON_UART_5V0
2 | UART7 TX | UART7_TX | GPIO_IO08
3 | UART7 RX | UART7_RX | GPIO_IO09
4 | UART7 CTS | UART7_CTS_B | GPIO_IO10
5 | UART7 RTS | UART7_RTS_B | GPIO_IO11
6 | GND

The 5 V output is filtered (VDD_CON_UART_5V0) and has ESD protection.

## IO J6 TELEM

## J8 GPS

JST-GH 1x10, sideentry ·DS-009GPS · 3.3 V logic

1 | 5V out | VDD_CON_GPS_5V0
2 | UART5 TX | UART5_TX | GPIO_IO00
3 | UART5 RX | UART5_RX | GPIO_IO01
4 | I2C6 SCL | I2C6_SCL | GPIO_IO03
5 | I2C6 SDA | I2C6_SDA | GPIO_IO02
6 | Safety switch | ARM_IO | GPIO_IO07
7 | Safety LED | SW_LED_OUT | I2C4 (GPIO_IO30/31) | via PCAL6416 expander
8 | 3.3V out | VDD_CON_GPS_3V3
9 | Buzzer | BUZZER | GPIO_IO23 | via FET Q2
10 | GND

Pin 9: enabled by DIP switch S1

Standard DS-009 GPS and compass connector. The safety switch input (ARM_IO) is also wired to the ARM button SW1 on the board,

and the LED output drives the LED in the switch. The buzzer pin is switched by an N-FET (AO3400A) driven from TPM6_CH1. A

buzzer on the board is connected in parallel. DIP switch S1 sits between TPM6_CH1 and the FET: with S1 OFF both buzzers are

disconnected and TPM6_CH1 is free for PWM8 on the PWM header.

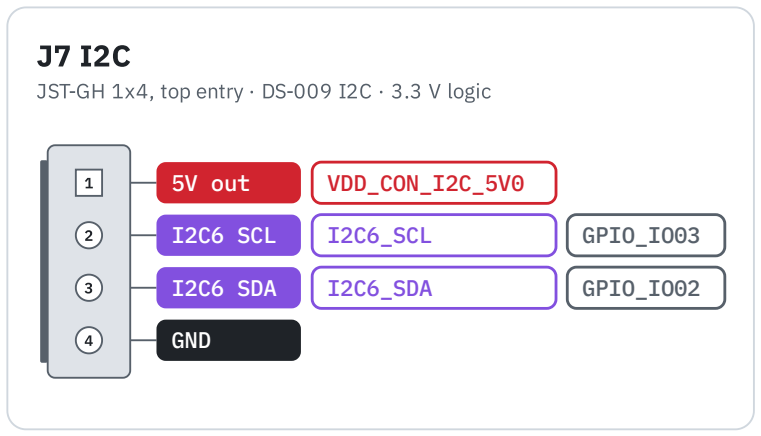
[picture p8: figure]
5V out; VDD_CON_I2C_5V0; I2C6 SCL; I2C6_SCL; GPIO_IO03; I2C6 SDA; I2C6_SDA; GPIO_IO02; GND

JST-GH 1x4, top entry · DS-009 I2C · 3.3 V logic

Same I2C6 bus as the GPS connector.

## IO J8 GPS

## IO J7 I2C

## J9 PWM

JST-GH 1x10, sideentry · 3.3 V logic outputs

1 | Servo rail | VDD_CON_PWM | | | | ADC_IN6
2 | PWM1 | TPM3_CH0 | FLEXIO1_FLEXIO4 | CAN4_TX | LPUART6_TX | GPIO_IO04
3 | PWM2 | TPM3_CH1 | FLEXIO1_FLEXIO20 | | | GPIO_IO20
4 | PWM3 | TPM3_CH3 | FLEXIO1_FLEXIO24 | | | GPIO_IO24
5 | PWM4 | TPM4_CH0 | FLEXIO1_FLEXIO5 | CAN4_RX | LPUART6_RX | GPIO_IO05
6 | PWM5 | TPM4_CH1 | FLEXIO1_FLEXIO21 | | | GPIO_IO21
7 | PWM6 | TPM5_CH0 | FLEXIO1_FLEXIO6 | | | GPIO_IO06
8 | PWM7 | TPM5_CH1 | FLEXIO1_FLEXIO22 | CAN5_TX | LPI2C5_SDA | GPIO_IO22
9 | PWM8 | TPM6_CH1 | FLEXIO1_FLEXIO23 | CAN5_RX | LPI2C5_SCL | GPIO_IO23
10 | GND

Pin 1: measured on ADC_IN6

Pin 9: shared with the buzzer while S1 is ON

Pin 1 (VDD_CON_PWM) is the servo power rail. It is linked to the board 5 V through R60 (0 Ω, not fitted) and measured on ADC_IN6

(VDD_CON_PWM / 8, up to 12 V). The outputs are 3.3 V logic with ESD protection. PWM8 (pin 9) also drives the buzzer. Every output

pad can also be muxed to FlexIO1, for example for DShot or other custom timing protocols. Pins 2 and 5 can also be CAN4 or

LPUART6 (TX and RX), pins 8 and 9 CAN5 or LPI2C5 (no pull-ups on the board). CAN4 and CAN5 need an external transceiver.

### Warning

Do not put more than 5 V on the servo rail (pin 1) while R60 is fitted.

### Tip

Need all eight PWM outputs? Switch DIP switch S1 (BUZZER) off. It frees PWM8 from the buzzer.

## J5 CAN1

JST-GH 1x4, sideentry ·DS-009 CAN

120 Ωtermination: fitted

TJA1463

CAN FDtransceiver

CANH | TXD | CAN1 TX | PDM_CLK
CANL | RXD | CAN1 RX | PDM_BIT_STREAM0
1 | 5V out | CON_CAN1_5V0
2 | CAN1 H | CAN1_H
3 | CAN1 L | CAN1_L
4 | GND

TJA1463 CAN FD transceiver with 5 V supply. The 120 Ω split termination is on the board, so each CAN port is a bus end. CANH and

CANL together form the differential bus. TXD and RXD are the logic pins of the transceiver and go to the FlexCAN pads of the

i.MX95. The transceiver enable and standby pins are controlled through the PCAL6524 I/O expander.

## IO J9 PWM

## IO J5 CAN1

# J4 CAN2

JST-GH 1x4, side entry · DS-009 CAN

120 Ω termination: fitted

TJA1463
CAN FD transceiver
CANH | TXD | CAN2 TX | GPIO_IO25
CANL | RXD | CAN2 RX | GPIO_IO27
1 | 5V out | CON_CAN2_5V0
2 | CAN2 H | CAN2_H
3 | CAN2 L | CAN2_L
4 | GND

Same circuit as CAN1, with the 120 Ω termination.

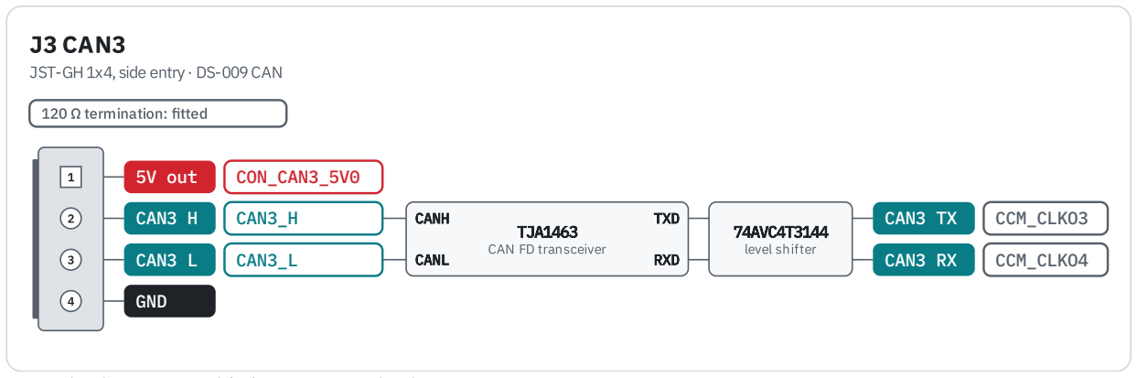
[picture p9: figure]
J3 CAN3; JST-GH1x4, side entry · DS-009CAN; 120 Ω termination: fitted; TJA1463; CAN FD transceiver; 74AVC4T3144; level shifter; CANH; TXD; CAN3 TX; CCM_CLKO3; CANL; RXD; CAN3 RX; CCM_CLKO4; 5V out; CON_CAN3_5V0; CAN3 H; CAN3_H; CAN3 L; CAN3_L; GND

Same circuit as CAN1, with the 120 Ω termination.

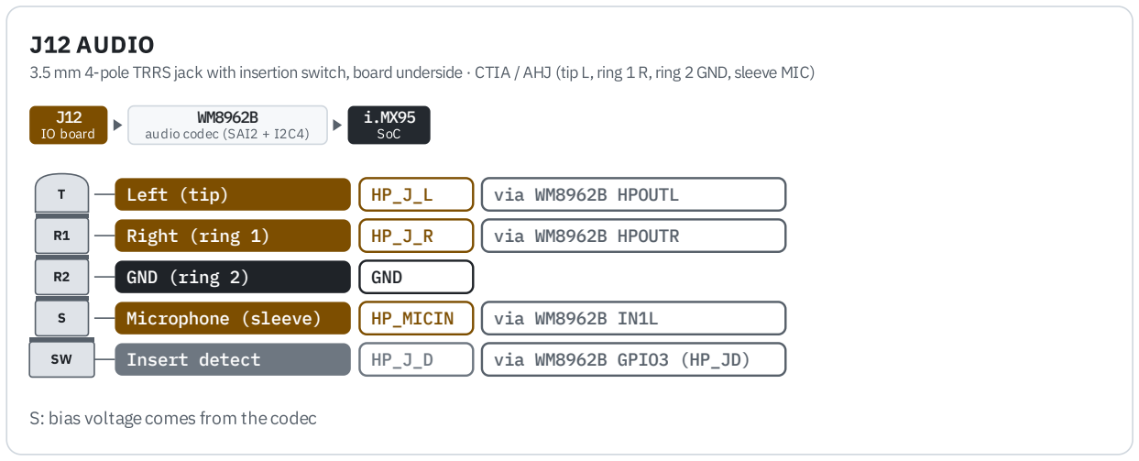
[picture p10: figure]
J12 AUDIO; IO board; audio codec (SAI2 + I2C4); SoC; Left (tip); via WM8962B HPOUTL; GND (ring 2); GND; S: bias voltagecomes from thecodec

3.5mm 4-pole TRRS jack with insertion switch, board underside · CTIA /AHJ (tip L,ring 1R,ring 2GND, sleeve MIC)

R1 | Right (ring 1) | HP_J_R | via WM8962B HPOUTR
S | Microphone (sleeve) | HP_MICIN | via WM8962B IN1L
SW | Insert detect | HP_J_D | via WM8962B GPIO3 (HP_JD)

Plug contacts listed from tip to sleeve. The switch in the jack drives HP_JD: high with a plug inserted, low without. The codec uses it

to detect the plug. The headphone ground reference is the HP_FB sense line of the codec.

### Note

CTIA wiring only. OMTP headsets (microphone and ground swapped) do not work.

## IO J4 CAN2

## IO J3 CAN3

## IO J12 AUDIO

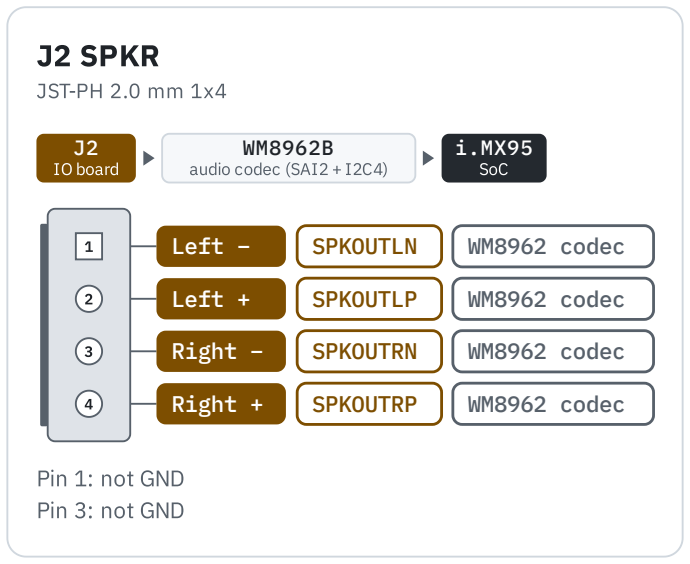
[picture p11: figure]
J2 SPKR; JST-PH 2.0 mm 1x4; IO board; audio codec (SAI2 + I2C4); SoC; Left −; SPKOUTLN; WM8962 codec; Left +; SPKOUTLP; Right −; SPKOUTRN; Right +; SPKOUTRP; Pin 1: not GND; Pin 3: not GND

Bridge-tied class-D outputs of the WM8962B codec. The 4-pin JST-PH plug of the Adafruit 1669 Stereo Enclosed Speaker Set (https://www.adafruit.com/product/1669) (2x 3

W, 4 Ω) fits directly. J25 next to it is the headset jack; the board also has two PDM microphones.

### Caution

No GND on this connector. Each speaker goes between its − and + pin. Never connect a speaker pin to ground.

Ref | Board | Function | Type | Notes
SW1 SYS_RST | Main | System reset button (short press: reset) | Tactile switch, right of the ON/OFF button, hidden under the thermal pad in the photo | Resets the whole board.
SW2 BTMODE | Main | Boot mode DIP switch | 4-position DIP switch, top side under the M.2 Key M module | See Power up NavQ95. (https://github.com/NXP-Robotics/imx-manifest-navq95#power-up-navq95)
SW3 ONOFF | Main | Power button (short press: on, 5 s press: off) | Tactile switch, left of the reset button | Talks to the PMIC ONOFF input.
S1 BUZZER | IO | Buzzer enable DIP switch | 1-position DIP switch (CHS-01TA1), next to the ARM button | ON connects TPM6_CH1 to the buzzer FET. OFF disconnects the buzzer and the GPS buzzer pin, so PWM8 on the PWM header is a free channel.
SW1 ARM | IO | Arm / safety switch with LED | Tactile switch | Wired in parallel with the safety-switch and LED pins of the GPS connector.
S1 SMI | T1S | SMI routing switch | 1-position DIP switch (CHS-01TA1) | Leave as delivered. Only used when the SJA1110 runs without the host.
S2 BOOT_OPT | T1S | SJA1110 boot option switch | 2-position DIP switch | Boot option of the SJA1110; see the SJA1110 documentation before changing it.

## IO J2 SPKR

# Buttons and switches

## J3 CSI

22-pin 0.5 mm FPC/FFC, contacts away from thePCB ·RPi 22-pin CSI layout · 1.2 V MIPI, 3.3 V I2Cand GPIO

J3

CAM board

IP4292

MIPI ESDarrays

## PCA9306

I2C level shifter

## i.MX95

SoC

RPi camera modulesfit(22-pin FFC) | RPiDSI displays: DSICSI_B2B port only
1 | GND
2 | CSI D0 − | MIPI_CSI_D0_N | MIPI_CSI1_D0_N
3 | CSI D0 + | MIPI_CSI_D0_P | MIPI_CSI1_D0_P
4 | GND
5 | CSI D1 − | MIPI_CSI_D1_N | MIPI_CSI1_D1_N
6 | CSI D1 + | MIPI_CSI_D1_P | MIPI_CSI1_D1_P
7 | GND
8 | CSI CLK − | MIPI_CSI_CLK_N | MIPI_CSI1_CLK_N
9 | CSI CLK + | MIPI_CSI_CLK_P | MIPI_CSI1_CLK_P
10 | GND
11 | CSI D2 − | MIPI_CSI_D2_N | MIPI_CSI1_D2_N
12 | CSI D2 + | MIPI_CSI_D2_P | MIPI_CSI1_D2_P
13 | GND
14 | CSI D3 − | MIPI_CSI_D3_N | MIPI_CSI1_D3_N
15 | CSI D3 + | MIPI_CSI_D3_P | MIPI_CSI1_D3_P
16 | GND
17 | Camera GPIO 1 | CAM1_IO1_CON | | via I/O expander
18 | Camera GPIO 2 | CAM1_IO2_CON | | via I/O expander
19 | GND
20 | I2C SCL | SCL_3V3_CON | I3C2_SCL | via PCA9306
21 | I2C SDA | SDA_3V3_CON | I3C2_SDA | via PCA9306
22 | 3.3V out | VDD_CON_3V3

Pin-compatible with the 22-pin RPi camera connector (22-pin 0.5 mm same-side FFC). Two identical camera boards can be fitted.

In the bottom view, the left one sits on CSI_B2B and goes to the i.MX95 MIPI_CSI1 port; the right one sits on DSICSI_B2B and goes

to the second port, which is shared between DSI and CSI. The camera I2C is the i.MX95 I3C2 bus, shifted from 1.8 V to 3.3 V by a

PCA9306. The two GPIO pins come from the I/O expander on the main board; the exact expander pins and the pad names of the

second port were not traced. Whether a camera module works depends on the software image, not on the connector. J4 next to it is

a 3-pin 5 V header for a display, not fitted.

### Tip

RPi camera modules fit directly with a standard 22-pin FFC. For an RPi DSI display use the camera board on the DSICSI_B2B

port; the CSI_B2B port cannot drive a display.

# Camera expansion board

## CAM J3 CSI

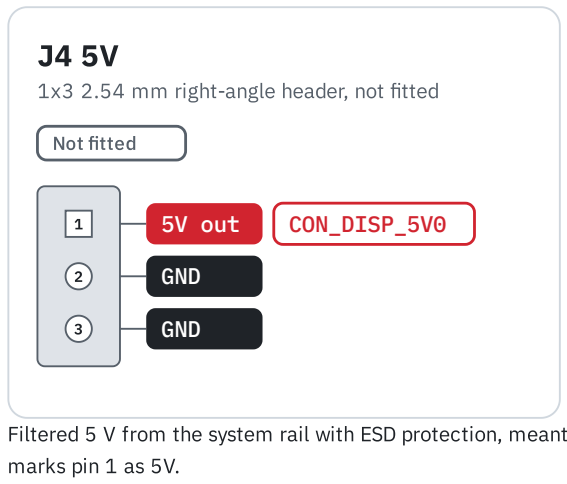
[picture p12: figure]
Not fitted; 5V out; CON_DISP_5V0; GND; marks pin 1 as 5V.

1x3 2.54 mm right-angle header, not fitted

Filtered 5 V from the system rail with ESD protection, meant for a DSI display on the DSICSI_B2B camera board. The silkscreen

The MR-NAVQ95E-T1S board is an NXP SJA1110 automotive Ethernet switch. It is connected to the main board through B2B_ETH

on SGMII port 4 of the switch (the host port). Ports 1 and 2 are 1000BASE-T1 through two TJA1120 PHYs on SGMII ports 1 and 2.

Ports 5 to 10 are 100BASE-T1 on the switch's own PHYs. SGMII port 3 is not used. The port numbers on the bottom view are the

switch port numbers, which also match the silkscreen.

Ref | Function | Connector | Notes
J4 PORT1 | 1000BASE-T1 port 1 | Single-pair automotive connector | TJA1120 PHY on SJA1110 SGMII port 1.
J3 PORT2 | 1000BASE-T1 port 2 | Single-pair automotive connector | TJA1120 PHY on SJA1110 SGMII port 2.
J5 PORT5 | 100BASE-T1 port 5 | 2-pin single-pair connector | SJA1110 internal 100BASE-T1 PHY, switch port 5.
J6 PORT6 | 100BASE-T1 port 6 | 2-pin single-pair connector | SJA1110 internal 100BASE-T1 PHY, switch port 6.
J7 PORT7 | 100BASE-T1 port 7 | 2-pin single-pair connector | SJA1110 internal 100BASE-T1 PHY, switch port 7.
J8 PORT8 | 100BASE-T1 port 8 | 2-pin single-pair connector | SJA1110 internal 100BASE-T1 PHY, switch port 8.
J9 PORT9 | 100BASE-T1 port 9 | 2-pin single-pair connector | SJA1110 internal 100BASE-T1 PHY, switch port 9.
J10 PORT10 | 100BASE-T1 port 10 | 2-pin single-pair connector | SJA1110 internal 100BASE-T1 PHY, switch port 10.
J2 DEBUG | Debug header of the SJA1110 (Arm Cortex-M7 inside the switch) | 2x5 1.27 mm | Not the i.MX95 debug port; that is J7 on the main board.

The connectors marked DS-009 on their card (TELEM, GPS, I2C, CAN and the J2 console header) follow the Dronecode DS-009

connector standard, (https://github.com/pixhawk/Pixhawk-Standards/blob/master/DS-009%20Pixhawk%20Connector%20Standard.pdf) so standard cables fit. The other JST-GH connectors, such as the PWM header, have their own pin order.

## CAM J4 5V

# T1 Ethernet switch board

## T1S ports and headers

# Notes

Input 9 to 52 V (never more than 60 V), 3S to 12S batteries. 60 W between 9 and 20 V, 125 W between 20 and 52 V.

The 5 V pin of every JST-GH connector is a filtered, ESD-protected output of the 5 V system rail ( VDD_CON_*_5V0 nets).

The servo rail of the PWM connector ( VDD_CON_PWM ) is separated from the 5 V rail by R60, a 0 Ω link that is not fitted. This

allows an external servo supply. The rail is measured on ADC_IN6 and must stay below 12 V.

VIN, 5 V and 3.3 V are measured on ADC_IN0, ADC_IN1 and ADC_IN2.

### Warning

Never feed power into a 5 V pin of a JST-GH connector. They are outputs. Power the board through J9 PWR_IN only.

This reference as an A4 PDF, (http://127.0.0.1:45079/MR-NAVQ95-hardware-reference.pdf) and all cards on one double-sided A4 landscape sheet: cheat sheet PDF. (http://127.0.0.1:45079/MR-NAVQ95-cheatsheet.pdf)

NXP and the NXP logo are registered trademarks of NXP B.V. This document is maintained by the community and is not an official

NXP publication.

# Downloads

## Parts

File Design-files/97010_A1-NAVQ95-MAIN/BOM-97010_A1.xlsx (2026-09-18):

NAVQ95-MAIN Revised: Wednesday, September 16, 2026
SCH-97010 / PDF: SPF-97010 Revision: A1
NXP Semiconductors
High Tech Campus 60
5656AG Eindhoven, Netherlands
Bill Of Materials September 17,2026 16:26:47 | Page1
Item | Quantity | AgilePN | ASSY_OPT | FIND# | PRE_APN | Reference | MFG_NAME01 | MFG_PN01 | Description | Value | PCB Footprint
1 | 14 | 280-10222 |  |  |  | BH1,BH2,BH3,BH4,BH5,BH6,BH7,BH8,BH9,BH10,BH11,BH12,BH13,BH14 |  |  | MOUNTING HOLE DRILL 3.7MM PAD 6MM PLATED TH NO PART TO ORDER | MH3.7_6 | mh236-146p
2 | 85 | 150-79461 |  |  |  | C1,C2,C3,C6,C7,C12,C13,C14,C15,C16,C21,C22,C27,C32,C33,C40,C41,C42,C45,C52,C53,C54,C55,C56,C59,C79,C80,C85,C87,C89,C91,C94,C96,C118,C119,C120,C121,C125,C127,C128,C129,C132,C133,C138,C143,C144,C145,C146,C149,C151,C156,C157,C161,C165,C167,C169,C170,C174,C210,C222,C236,C237,C240,C261,C268,C286,C295,C312,C317,C363,C381,C386,C391,C392,C393,C401,C402,C409,C410,C415,C416,C417,C418,C431,C432 | MURATA | GCM155R71H104KE02D | CAP CER 0.1uF 50V 10% X7R AEC-Q200 0402 | 0.1uF | CC0402_25
3 | 28 | 150-79207 |  |  |  | C4,C5,C66,C67,C176,C177,C213,C230,C231,C233,C234,C235,C238,C248,C250,C251,C253,C254,C255,C291,C293,C349,C353,C361,C364,C366,C368,C377 | MURATA | GCM155R71C224KE02 | CAP CER 0.22uF 16V 10% X7R AEC-Q200 0402 | 0.22uF | CC0402_25
4 | 2 | 150-79021 |  |  |  | C8,C9 | MURATA | GCM1555C1H101JA16D | CAP CER 100pF 50V 5% C0G AEC-Q200 0402 | 100pF | CC0402_25
5 | 49 | 150-10058 |  |  |  | C10,C11,C34,C35,C36,C37,C46,C47,C51,C83,C86,C102,C105,C112,C122,C130,C131,C135,C139,C141,C162,C163,C168,C199,C204,C224,C225,C227,C243,C246,C264,C283,C285,C310,C318,C325,C328,C346,C356,C357,C362,C365,C369,C370,C371,C372,C373,C421,C429 | MURATA | GRM21BZ71E106KE15L | CAP CER 10uF 25V 10% X7R 0805 | 10uF | CC0805_OV
6 | 13 | 150-30186 |  |  |  | C17,C74,C136,C360,C376,C378,C379,C385,C396,C397,C398,C399,C403 | MURATA | GRM32ER71A476KE15L | CAP CER 47UF 10V 10% X7R 1210 | 47uF | CC1210
7 | 128 | 150-81359 |  |  |  | C18,C19,C24,C25,C62,C71,C123,C124,C142,C147,C154,C164,C166,C171,C173,C187,C188,C189,C192,C193,C194,C195,C196,C197,C198,C200,C201,C202,C203,C205,C207,C208,C209,C211,C212,C214,C215,C216,C217,C218,C219,C220,C221,C223,C226,C228,C229,C232,C239,C241,C242,C244,C245,C249,C252,C256,C257,C259,C262,C263,C265,C266,C267,C269,C271,C272,C273,C274,C275,C276,C277,C278,C281,C282,C284,C287,C288,C289,C290,C292,C294,C296,C297,C298,C299,C300,C301,C302,C303,C304,C306,C307,C308,C309,C311,C313,C314,C315,C316,C319,C320,C321,C323,C324,C326,C327,C330,C331,C332,C333,C334,C335,C336,C337,C338,C339,C340,C342,C343,C344,C345,C347,C348,C352,C354,C355,C358,C359 | MURATA | GRM155Z71A105KE01J | CAP CER 1uF 10V 10% X7R 0402 | 1uF | CC0402_25
8 | 11 | 150-79771 |  |  |  | C20,C26,C38,C39,C58,C61,C172,C179,C182,C185,C258 | MURATA | GCM31CR71A226KE02 | CAP CER 22uF 10V 10% X7R AEC-Q200 1206 | 22uF | 1206_CC
9 | 1 | 150-79461 | DNP |  |  | C23 | MURATA | GCM155R71H104KE02D | CAP CER 0.1uF 50V 10% X7R AEC-Q200 0402 | 0.1uF | CC0402_25
10 | 7 | 150-79033 |  |  |  | C28,C206,C305,C322,C329,C350,C351 | MURATA | GCM188R70J225KE22D | CAP CER 2.2uF 6.3V 10% X7R AEC-Q200 0603 | 2.2uF | CC0603_OV
11 | 2 | 150-79375 | DNP |  |  | C29,C92 | MURATA | GCM155R71H221KA37 | CAP CER 220pF 50V 10% X7R AEC-Q200 0402 | 220 pF | CC0402_25
12 | 19 | 150-81482 |  |  |  | C30,C31,C48,C82,C93,C98,C175,C178,C180,C183,C184,C186,C367,C374,C375,C384,C387,C388,C404 | MURATA | GRT188C71C475KE13 | CAP CER 4.7uF 16V 10% X7S AEC-Q200 0603 | 4.7uF | CC0603_OV
13 | 3 | 150-79023 |  |  |  | C43,C44,C430 | MURATA | GCM1555C1H100JA16 | CAP CER 10pF 50V 5% C0G AEC-Q200 0402 | 10pF | CC0402_25
14 | 9 | 150-81389 |  |  |  | C49,C50,C84,C88,C90,C190,C191,C390,C400 | MURATA | GCM31CD70G476ME02L | CAP CER 47uF 4V 20% X7T AEC-Q200 1206 | 47uF | 1206_CC
15 | 2 | 150-80457 |  |  |  | C57,C60 | MURATA | GCM1555C1H120JA16D | CAP CER 12pF 50V 5% C0G AEC-Q200 0402 | 12pF | CC0402_25
16 | 5 | 150-79051 |  |  |  | C63,C380,C382,C422,C424 | MURATA | GCM155R71H103KA55D | CAP CER 0.01uF 50V 10% X7R AEC-Q200 0402 | 0.01uF | CC0402_25
17 | 1 | 150-79938 |  |  |  | C64 | MURATA | GRT155R71A474KE01 | CAP CER 0.47uF 10V 10% X7R AEC-Q200 0402 | 0.47uF | CC0402_25
18 | 1 | 150-10448 |  |  |  | C65 | YAGEO AMERICA | CC0603KRX7R7BB824 | CAP CER 0.82uF 16V 10% X7R 0603 | 0.82uF | CC0603_OV
19 | 1 | 150-10279 |  |  |  | C68 | MURATA | GRM1555C1H2R7BA01D | CAP CER 2.7pF 50V 4% C0G 0402 | 2.7pF | CC0402_25
20 | 1 | 150-10449 |  |  |  | C69 | Murata Electronics | GRM1555C1H6R8BA01D | CAP CER 6.8pF 50V 1.47% C0G 0402 | 6.8pF | CC0402_25
21 | 1 | 150-79032 |  |  |  | C70 | MURATA | GCM1555C1H471JA16D | CAP CER 470pF 50V 5% C0G AEC-Q200 0402 | 470pF | CC0402_25
22 | 1 | 150-10444 |  |  |  | C72 | MURATA | GCM1555C1H681JA16D | CAP CER 680pF 50V 5% C0G AEC-Q200 0402 | 680pF | CC0402_25
23 | 10 | 150-10445 |  |  |  | C73,C77,C78,C117,C150,C152,C153,C158,C159,C160 | MURATA | GRM155Z71A225KE44D | CAP CER 2.2UF 10V 10% X7R 0402 | 2.2uF | cc0402_tol0p2_ov
24 | 6 | 150-79200 |  |  |  | C75,C76,C97,C99,C111,C116 | KEMET | C0603C104K1RACTU | CAP CER 0.1uF 100V X7R 10% 0603 | 0.1uF | CC0603_OV
25 | 1 | 150-30186 | DNP |  |  | C81 | MURATA | GRM32ER71A476KE15L | CAP CER 47UF 10V 10% X7R 1210 | 47uF | CC1210
26 | 6 | 150-80524 |  |  |  | C95,C100,C103,C109,C110,C115 | TDK | CGA3EAC0G2A103J080AC | CAP CER 0.01uF 100V 5% C0G AEC-Q200 0603 | 0.01uF | CC0603_OV
27 | 4 | 150-81365 |  |  |  | C101,C107,C108,C114 | KEMET | C0402C102K1GECAUTO | CAP CER 1000pF 100V 10% C0G AEC-Q200 0402 | 1000pF | CC0402_25
28 | 2 | 150-79351 |  |  |  | C104,C106 | PANASONIC | EEEFK1K470P | CAP ALEL 47uF 80V 20% --- AEC-Q200 SMT | 47uF | cce10_3x10_3_413h
29 | 1 | 150-81600 |  |  |  | C113 | TDK | YFF31AH2A105MT0Y0N | CAP FILTER EMI 1.0uF 100V 6A 20% AEC-Q200 1206 | 1uF | fltr4_1206_sm
30 | 6 | 150-81592 |  |  |  | C126,C134,C137,C140,C148,C155 | MURATA | GCM188R71E105KA64J | CAP CER 1uF 25V 10% X7R AEC-Q200 0603 | 1uF | CC0603_OV
31 | 1 | 150-81410 | DNP |  |  | C181 | TDK | CGA2B2X7R1H102K050BA | CAP CER 1000pF 50V 10% X7R AEC-Q200 0402 | 1000pF | CC0402_25
32 | 1 | 150-79033 |  |  |  | C247 | MURATA | GCM188R70J225KE22D | CAP CER 2.2uF 6.3V 10% X7R AEC-Q200 0603 | 2.2uF | 0603_CC
33 | 2 | 150-10058 |  |  |  | C260,C270 | MURATA | GRM21BZ71E106KE15L | CAP CER 10uF 25V 10% X7R 0805 | 10uF | 0805_CC
34 | 2 | 150-10443 |  |  |  | C279,C280 | YAGEO | CC0402JRNPO7BN330 | CAP CER 33pF 16V 5% C0G 0402 | 33pF | CC0402_25
35 | 1 | 150-79926 |  |  |  | C341 | KEMET | C0402C470F3GAC | CAP CER 47pF 25V 1% C0G 0402 | 47pF | CC0402_25
36 | 15 | 150-10446 |  |  |  | C383,C389,C394,C395,C406,C407,C408,C411,C412,C413,C419,C420,C423,C425,C426 | TDK | CGA6P1X7R1N106M250AC | CAP CER 10uF 75V 20% X7R AEC-Q200 1210 | 10uF | CC1210
37 | 2 | 150-81323 |  |  |  | C405,C414 | Murata Electronics | GCQ1555C1H270JB01D | CAP CER 27pF 50V 5% C0G AEC-Q200 0402 | 27pF | cc0402_25
38 | 1 | 150-79023 | DNP |  |  | C427 | MURATA | GCM1555C1H100JA16 | CAP CER 10pF 50V 5% C0G AEC-Q200 0402 | 10pF | CC0402_25
39 | 1 | 150-81792 |  |  |  | C428 | MURATA | GCM31C5C3A102JX03 | CAP CER 1000pF 1000V 5% C0G AEC-Q200 1206 | 1000pF | CC1206_OV
40 | 2 | 480-30039 |  |  |  | D1,D3 | ON SEMICONDUCTOR | BAT54HT1G | DIODE SCH 30V 200MA -- SOD323 | BAT54HT1 | SOD323
41 | 3 | 370-76670 |  |  |  | D2,D12,D15 | WURTH ELEKTRONIK EISOS GMBH & CO. KG (ELECTRONIC & ELECTROMEHANICAL COMP) | 150060VS75000 | LED BRIGHT GRN SGL 30mA 0603 | LED_GRN | LED_0603
42 | 1 | 370-76774 |  |  |  | D4 | WURTH ELEKTRONIK EISOS GMBH & CO. KG (ELECTRONIC & ELECTROMEHANICAL COMP) | 150060YS75000 | LED YELLOW CLEAR 20mA 2V 0603 SMT | LED_YEL | LED_0603
43 | 1 | 370-76671 |  |  |  | D5 | WURTH ELEKTRONIK EISOS GMBH & CO. KG (ELECTRONIC & ELECTROMEHANICAL COMP) | 150060SS75000 | LED ULTRA BRIGHT RED SGL 30mA 5V 0603 | LED_SUPER_RED | LED_0603
44 | 1 | 370-76859 |  |  |  | D6 | WURTH ELEKTRONIK EISOS GMBH & CO. KG (ELECTRONIC & ELECTROMEHANICAL COMP) | 150060AS75000 | LED AMB SGL 2V 20mA 0603 | LED_AMB | LED_0603
45 | 4 | 480-10551 |  |  |  | D7,D8,D16,D17 | PANJIT SEMICONDUCTOR | SS10100FL_R1_00001 | DIODE SCH RECT 100V 1A SOD123FL | SS10100FL_R1_00001 | sod123fl
46 | 13 | 480-10550 |  |  |  | D9,D18,D19,D20,D21,D22,D23,D24,D25,D26,D27,D28,D29 | DIODES INC | DESD5V0X1BCSF-7 | DIODE TVS BIDIR 4A 5V 24W DFN0603-2L | DESD5V0X1BCSF | x2-dfn0603-2
47 | 2 | 480-77923 |  |  |  | D10,D13 | ON SEMICONDUCTOR | NSR0320MW2T1G | DIODE SCH PWR RECT LOW VF 1A 20V SOD323 | NSR0320 | SOD323
48 | 1 | 370-76775 |  |  |  | D11 | WURTH ELEKTRONIK EISOS GMBH & CO. KG (ELECTRONIC & ELECTROMEHANICAL COMP) | 150060BS75000 | LED BLUE CLEAR SGL 20MA 3.2V 0603 SMT | BLUE LED | LED_0603
49 | 1 | 480-77923 | DNP |  |  | D14 | ON SEMICONDUCTOR | NSR0320MW2T1G | DIODE SCH PWR RECT LOW VF 1A 20V SOD323 | NSR0320 | SOD323
50 | 2 | 480-78961 |  |  |  | D30,D31 | NEXPERIA | PUSB3FR4Z | DIODE ARRAY ESD 3.3V 5A DFN2510A-10 | PUSB3FR4 | xson10_0p5_1p1x2p6mm
51 | 1 | 211-10525 |  |  |  | J1 | ATTEND TECHNOLOGY INC | 123A-85M02 | CON 67 M.2 KEY M GEN5 RA SMT 0.5MM SP 343H AU | M.2 SLOT (KEY - M) | con67_0p5_type_m_22p1x6p05_ra
52 | 1 | 211-80223 |  |  |  | J2 | JST MFG. CO | SM06B-GHS-TB(LF)(SN) | CON 1X6 CRIMP RA SMT 1.25MM SP 173H SN | CON_1X6 | con1x6_1p25_10p75x4p05_sm_ra
53 | 3 | 211-10507 |  |  |  | J3,J4,J17 | HIROSE | DF40TC(4.0)-50DS-0.4V(51) | CON 2X25 SKT SHRD SMT 0.4MM SP 159H AU | CON 2X25 | con_2x25_0p4_12p6x2p94_smt
54 | 1 | 211-10515 |  |  |  | J5 | GLOBAL CONNECTOR TECHNOLOGY INC | SIM8066-6-1-14-01-A | CON 7 NANO SIM CARD PUSH-PUSH RA SMT 50MIL SP 65H AU | CON 6+1 SIM CARD | con_nanosim_7f_1p27_sm_ra
55 | 1 | 211-10681 |  |  |  | J6 | Same Sky | MSD-1-A | CON 9 MICROSD CARD PUSH SMT 1.1MM SP 79H AU | CONN_SD_CARD 9 | con9_sdcard_msd-1-a
56 | 1 | 210-80888 |  |  |  | J7 | SAMTEC | SHF-105-01-L-D-RA | CON 2X5 TH SHRD PLUG RA 50MIL CTR 225H AU 75L | SHF-105-01-L-D-RA | con2x5_50_th_ra
57 | 1 | 210-10512 |  |  |  | J8 | ABRACON | ARJM11D7-502-AB-EW2 | CON RJ45 JACK 1X1 SHLD RA TH 1.27MM SP 553H AU 126L | CON_RJ45 | con_rj45_14f_50_th_ra_a
58 | 1 | 210-10755 |  |  |  | J9 | Molex | 430450222 | CON 1X2 PLUG SHRD TH 3MM SP 356H AU 125L | CON 1X2 PLUG | hdr_1x2_3mm_ra_th
59 | 1 | 211-80595 |  |  |  | J10 | JST MFG. CO | SM02B-GHS-TB(LF)(SN) | CON 1X2 CRIMP RA 1.25MM SP 173H SN SMT | SM02B-GHS-TB(LF)(SN) | con_1x2_1p25_5p8x4p1_sm_ra
60 | 1 | 211-80218 |  |  |  | J11 | JST MFG. CO | SM02B-SRSS-TB(LF)(SN) | CON 1X2 RA SHRD SKT SMT 1MM SP 118H SN | 1X2 | con2_1mm_sm_ra_4p25x4
61 | 1 | 211-10495 |  |  |  | J12 | Same Sky | UJ20-C-H-G-SMT-1-P16-TR | CON 2X8 USB2.0_TYPE_C RCPT SMT RA 0.5MM 131H AU | USB_TYPE_C | con16f_usb_type-c_ra_sm
62 | 1 | 211-10680 |  |  |  | J13 | Same Sky | UJ32-C-H-G-SMT-1-P24-TR | CON 24 USB 3.2 TYPE C SKT SHLD RA SMT 0.5MM SP 136H AU | USB_TYPE_C | con24_usb_type-c_0p5_sm_ra_ldi
63 | 2 | 211-10506 |  |  |  | J14,J15 | Hirose Electric Co Ltd | DF40TC(4.0)-40DS-0.4V(58) | CON 2X20 SKT SHRD SMT 0.4MM SP 159H AU | CON 2X20 | con_2x20_0p4_10p6x2p94_smt
64 | 1 | 211-10527 |  |  |  | J16 | ATTEND TECHNOLOGY INC | 123A-85B02 | CON 67 PCIE M.2 KEY-B GEN5 SKT RA SMT 0.5MM SP 341H AU | M.2 SKT KEY-B | con75_pcie_key_b_0p5_22x6_ra
65 | 2 | 211-81332 |  |  |  | J18,J19 | HIROSE | U.FL-R-SMT-1(10) | CON 1 COAX SKT SMT 49H AU | U.FL | CON_3_UFL_R_SMT
66 | 1 | 180-81280 |  |  |  | L1 | MURATA | BLM18SP601SZ1D | IND FER BEAD 600 OHM@100MHz 1.5A 25% AEC-Q200 0603 | 600 OHM@100MHz | ind_0603
67 | 4 | 180-78924 |  |  |  | L2,L3,L4,L5 | TDK | TFM252012ALMAR47MTAA | IND PWR 0.47uH@1MHz 5.8A 20% AEC-Q200 SMT | 0.47 uH | ind2520
68 | 1 | 180-81455 |  |  |  | L6 | TDK | BCL3520FT-R47M-D | IND PWR 0.47uH@1MHZ 10A 20% AEC-Q200 SMT | 0.47uH | ind_3p2x3p5mm_sm
69 | 2 | 180-81055 |  |  |  | L7,L13 | TDK | HPL505028FR10MRD3P | IND PWR 0.1uH@100kHz 27.5A 20% AEC-Q200 SMD | 100nH | ind3_2p5_sq5p2mm
70 | 2 | 180-81279 |  |  |  | L8,L9 | MURATA | BLM18PG121SZ1 | IND FER BEAD 120OHM@100MHZ 2A 25% AEC-Q200 0603 | 120OHM@100MHZ | IND_0603
71 | 3 | 180-10306 |  |  |  | L10,L11,L12 | TDK | SPM10065VC-1R0M-D | IND PWR 1.0uH@100KHz 36A 15% 2.3mOHM AEC-Q200 SMT | 1.0uH | ind2_10p9x10p4
72 | 2 | 180-10305 |  |  |  | L14,L15 | LAIRD TECHNOLOGIES | HR2220V801R-10 | IND FER BEAD 800 OHM@100MHz 8A 2220 | 800Ohms@100MHz | ind2220_152h
73 | 1 | 180-77770 |  |  |  | L16 | MURATA | BLM15PD121SN1D | IND FER BEAD 120 OHM@100MHZ 1.3A 25% 0402 | 120 Ohm | IND_0402
74 | 1 | 180-77603 |  |  |  | L17 | MURATA | LQM2MPN2R2NG0L | IND FER PWR 2.2UH@1MHZ 1.2A 30% 0806 | 2.2UH | ind_0806_sm
75 | 3 | 480-10103 |  |  |  | Q1,Q2,Q7 | Nexperia | NX3020NAKW,115 | TRAN NMOS SW 30V 180mA SC-70 | NX3020NAKW,115 | sc70_3
76 | 4 | 480-10027 |  |  |  | Q3,Q4,Q5,Q6 | Infineon Technologies | ISC0703NLSATMA1 | TRAN NMOS PWR 13A/57A 60V 0.0069 OHM TDSON-8 | ISC0703NLSATMA1 | tdson_1p27_5p35x6p1
77 | 2 | 480-79692 |  |  |  | Q8,Q9 | NEXPERIA | NX3020NAKS,115 | TRAN NMOS SW DUAL 180MA 30V 4.5 OHM SOT363 | NX3020NAKS | sot-363_0p65_smt
78 | 1 | 470-82352 |  |  |  | R1 | VISHAY INTERTECHNOLOGY | RCS040275R0FKED | RES MF 75.0 OHM 1/5W 1% AEC-Q200 0402 | 75 | RC0402_25
79 | 68 | 470-81195 |  |  |  | R2,R4,R6,R7,R10,R11,R13,R15,R17,R18,R21,R25,R29,R35,R40,R45,R50,R53,R66,R79,R87,R90,R100,R107,R108,R116,R117,R118,R120,R140,R142,R153,R167,R168,R170,R171,R173,R174,R175,R198,R200,R201,R204,R206,R214,R215,R219,R237,R238,R239,R241,R242,R243,R244,R253,R255,R256,R258,R259,R264,R277,R286,R293,R300,R340,R342,R357,R371 | PANASONIC | ERJ-2GEJ103X | RES MF 10K OHM 5% 1/10W AEC-Q200 0402 | 10K | RC0402_25
80 | 132 | 470-10144 |  |  |  | R3,R16,R19,R20,R22,R23,R26,R27,R28,R30,R31,R32,R33,R34,R36,R37,R38,R39,R41,R42,R43,R44,R46,R47,R48,R49,R51,R54,R55,R57,R62,R63,R69,R70,R76,R77,R80,R81,R82,R83,R95,R96,R98,R99,R101,R102,R104,R109,R110,R119,R129,R130,R131,R132,R143,R144,R148,R149,R160,R161,R188,R189,R190,R191,R192,R194,R195,R196,R197,R202,R205,R207,R208,R211,R216,R227,R228,R240,R245,R248,R270,R271,R272,R273,R279,R283,R284,R299,R302,R303,R304,R306,R307,R309,R310,R311,R321,R324,R325,R326,R327,R328,R329,R332,R333,R334,R335,R338,R339,R341,R343,R345,R346,R351,R352,R353,R354,R355,R356,R358,R360,R363,R366,R368,R369,R370,R372,R373,R374,R375,R376,R377 | YAGEO AMERICA | AC0402JR-070RL | RES MF ZERO OHM JUMPER 1/16W 5% AEC-Q200 0402 | 0 OHM | rc0402_25
81 | 1 | 470-76465 |  |  |  | R5 | KOA SPEER | RK73H1ETTP3300F | RES MF 330 OHM 1/16W 1% AEC-Q200 0402 | 330 | RC0402_25
82 | 2 | 470-31107 |  |  |  | R8,R12 | KOA SPEER | RK73H1ETTP2703F | RES MF 270K 1/10W 1% AEC-Q200 0402 | 270K | RC0402_25
83 | 4 | 470-82202 |  |  |  | R9,R14,R236,R278 | PANASONIC | ERJ-2RKF1004X | RES TF 1.0M 1/10W 1% AEC-Q200 0402 | 1M | RC0402_25
84 | 2 | 470-81535 |  |  |  | R24,R287 | KOA SPEER | RK73H1ETTP2400F | RES MF 240 OHM 1/10W 1% AEC-Q200 0402 | 240 | RC0402_25
85 | 2 | 470-30777 | DNP |  |  | R52,R78 | KOA SPEER | RK73H1ETTP2430F | RES MF 243 OHM 1/10W 1% AEC-Q200 0402 | 243 | RC0402_25
86 | 2 | 470-30721 | DNP |  |  | R56,R75 | KOA SPEER | RK73H1ETTP63R4F | RES MF 63.4 OHM 1/10W 1% AEC-Q200 0402 | 63.4 | RC0402_25
87 | 4 | 470-81628 |  |  |  | R58,R67,R146,R154 | KOA SPEER | RK73H1ETTP5101F | RES MF 5.1K 1/10W 1% AEC-Q200 0402 | 5.1K | RC0402_25
88 | 8 | 470-80531 |  |  |  | R59,R61,R147,R150,R210,R213,R217,R222 | KOA SPEER | RK73H1ETTP1001F | RES MF 1.0K 1/10W 1% AEC-Q200 0402 | 1.0K | RC0402_25
89 | 1 | 470-83520 | DNP |  |  | R60 | YAGEO | AC0402JR-07100RL | RES MF 100 OHM 1/16W 5% AEC-Q200 0402 | 100 | rc0402_25
90 | 21 | 470-83517 |  |  |  | R64,R71,R72,R84,R92,R93,R151,R223,R224,R225,R226,R246,R249,R251,R261,R274,R275,R301,R305,R330,R331 | YAGEO AMERICA | AC0402FR-13100KL | RES MF 100K 1% 1/16W AEC-Q200 0402 | 100k | RC0402_25
91 | 11 | 470-81195 | DNP |  |  | R65,R152,R229,R254,R257,R288,R290,R292,R295,R296,R297 | PANASONIC | ERJ-2GEJ103X | RES MF 10K OHM 5% 1/10W AEC-Q200 0402 | 10K | RC0402_25
92 | 29 | 470-10144 | DNP |  |  | R68,R73,R103,R113,R114,R115,R124,R126,R141,R145,R156,R158,R159,R162,R164,R165,R166,R169,R212,R230,R266,R267,R268,R269,R298,R361,R362,R364,R365 | YAGEO AMERICA | AC0402JR-070RL | RES MF ZERO OHM JUMPER 1/16W 5% AEC-Q200 0402 | 0 OHM | rc0402_25
93 | 1 | 470-10478 | DNP |  |  | R74 | STACKPOLE ELECTRONICS | RNCF0402BTE1K00 | RES MF 1K 1/10W 0.1% AEC-Q200 0402 | 1K | RC0402_25
94 | 1 | 470-10597 |  |  |  | R85 | PANASONIC | ERA-2AEB302X | RES MF 3K 1/16W 0.1% AEC-Q200 0402 | 3K | RC0402_25
95 | 1 | 470-10596 |  |  |  | R86 | PANASONIC | ERA-2AEB6342X | RES MF 63.4K 1/16W 0.1% AEC-Q200 0402 | 63.4K | RC0402_25
96 | 4 | 470-10478 |  |  |  | R88,R89,R91,R94 | STACKPOLE ELECTRONICS | RNCF0402BTE1K00 | RES MF 1K 1/10W 0.1% AEC-Q200 0402 | 1K | RC0402_25
97 | 5 | 470-80516 |  |  |  | R97,R252,R262,R263,R291 | KOA SPEER | RK73H1ETTP2000F | RES MF 200 Ohm 1/16W 1% AEC-Q200 0402 | 200 | RC0402_25
98 | 10 | 470-82544 |  |  |  | R105,R111,R121,R122,R133,R135,R182,R183,R220,R221 | YAGEO AMERICA | AC0402FR-072K2L | RES MF 2.2K 1/16W 1% AEC-Q200 0402 | 2.2K | RC0402_25
99 | 3 | 470-80064 |  |  |  | R106,R184,R350 | KOA SPEER | RK73B1JTTD391J | RES MF 390 OHM 1/8W 5% AEC-Q200 0603 | 390 | RC0603_OV
100 | 12 | 470-82544 | DNP |  |  | R112,R123,R137,R139,R176,R177,R178,R179,R180,R181,R378,R379 | YAGEO AMERICA | AC0402FR-072K2L | RES MF 2.2K 1/16W 1% AEC-Q200 0402 | 2.2K | RC0402_25
101 | 1 | 470-10519 |  |  |  | R125 | YAGEO AMERICA | RT0402BRD0714K7L | RES MF 14.7K 1/16W 0.1% 0402 | 14.7K | RC0402_25
102 | 1 | 470-10517 |  |  |  | R127 | YAGEO AMERICA | AC0402FR-0723K7L | RES MF 23.7K 1/16W 1% AEC-Q200 0402 | 23.7K | rc0402_25
103 | 1 | 470-30966 |  |  |  | R128 | YAGEO AMERICA | RC0402FR-0715K4L | RES MF 15.4K 1/16W 1% 0402 | 15.4K | RC0402_25
104 | 3 | 470-10354 |  |  |  | R134,R155,R163 | KOA Speer | SG73P1EWTTP1R0J | RES MF 1.0 OHM 1/4W 5% AEC-Q200 0402 | 1 | RC0402_25
105 | 1 | 470-81990 |  |  |  | R136 | KOA SPEER | RK73H1ETTP1501F | RES MF 1.50K 1/10W 1% AEC-Q200 0402 | 1.5K | RC0402_25
106 | 1 | 470-81990 | DNP |  |  | R138 | KOA SPEER | RK73H1ETTP1501F | RES MF 1.50K 1/10W 1% AEC-Q200 0402 | 1.5K | RC0402_25
107 | 6 | 470-83520 |  |  |  | R157,R199,R203,R209,R218,R282 | YAGEO | AC0402JR-07100RL | RES MF 100 OHM 1/16W 5% AEC-Q200 0402 | 100 | rc0402_25
108 | 4 | 470-80973 |  |  |  | R172,R186,R187,R193 | KOA SPEER | RK73B1ETTP332J | RES MF 3.3K 1/16W 5% AEC-Q200 0402 | 3.3K | RC0402_25
109 | 1 | 470-80973 | DNP |  |  | R185 | KOA SPEER | RK73B1ETTP332J | RES MF 3.3K 1/16W 5% AEC-Q200 0402 | 3.3K | RC0402_25
110 | 2 | 470-81909 |  |  |  | R231,R276 | KOA SPEER | RK73H1ETTP4703F | RES MF 470K 1/10W 1% AEC-Q200 0402 | 470K | RC0402_25
111 | 15 | 470-82064 |  |  |  | R232,R233,R234,R235,R312,R313,R314,R316,R318,R319,R322,R323,R336,R348,R367 | KOA SPEER | RK73B1ETTP472J | RES MF 4.7K 1/10W 5% AEC-Q200 0402 | 4.7K | RC0402_25
112 | 3 | 470-83458 |  |  |  | R247,R260,R265 | KOA SPEER | RK73B1JTTD681J | RES MF 680 OHM 1/10W 5% AEC-Q200 0603 | 680 | RC0603_OV
113 | 1 | 470-83517 | DNP |  |  | R250 | YAGEO AMERICA | AC0402FR-13100KL | RES MF 100K 1% 1/16W AEC-Q200 0402 | 100k | RC0402_25
114 | 2 | 470-80522 |  |  |  | R280,R281 | KOA SPEER | RK73H1ETTP49R9F | RES MF 49.9 Ohm 1/16W 1% AEC-Q200 0402 | 49.9 | RC0402_25
115 | 1 | 470-82646 |  |  |  | R285 | Panasonic | ERJ-2RKF1200X | RES MF 120 OHM 1/10W 1% AEC-Q200 0402 | 120 | RC0402_25
116 | 1 | 470-80913 | DNP |  |  | R289 | KOA SPEER | RK73H1ETTP1502F | RES MF 15K 1/10W 1% AEC-Q200 0402 | 15K | RC0402_25
117 | 1 | 470-82836 |  |  |  | R294 | YAGEO AMERICA | RC0402FR-0751RL | RES MF 51 OHM 1/16W 1% 0402 | 51Ohms | RC0402_25
118 | 2 | 470-10518 |  |  |  | R308,R320 | SUSUMU CO. LTD. | KRL6432E-M-R003-F-T1 | RES MF 0.003 OHM 3W 1% AEC-Q200 2512 WIDE | 0.003 | rc6432
119 | 2 | 470-82064 | DNP |  |  | R315,R317 | KOA SPEER | RK73B1ETTP472J | RES MF 4.7K 1/10W 5% AEC-Q200 0402 | 4.7K | RC0402_25
120 | 1 | 470-30877 |  |  |  | R337 | KOA SPEER | RK73H1ETTP2491F | RES MF 2.49K 1/10W 1% AEC-Q200 0402 | 2.49K | RC0402_25
121 | 1 | 470-82112 |  |  |  | R344 | KOA SPEER | RK73B2BTTD105J | RES MF 1.0M 1/4W 5% AEC-Q200 1206 | 1.0M | RC1206_OV
122 | 1 | 470-82096 |  |  |  | R347 | KOA SPEER | RK73B1JTTD272J | RES MF 2.7K 1/10W 5% AEC-Q200 0603 | 2.7K | RC0603_OV
123 | 2 | 470-80897 |  |  |  | R349,R359 | KOA SPEER | RK73H1JTTD5100F | RES MF 510 OHM 1/10W 1% AEC-Q200 0603 | 510 | RC0603_OV
124 | 2 | 510-78339 |  |  |  | SW1,SW3 | E SWITCH | TL6330AF200Q | SW SPST NO TACTILE 50mA 12V SMT | TL6330AF200Q | sw4_spst_4p6x2p8_sm
125 | 1 | 510-77691 |  |  |  | SW2 | NIDEC COPAL ELECTRONICS CORP | CHS-04TA | SW SPST SLD WSH 25MA 24V DIP-4 SMT | CHS-04TA | sw_chs_04_a
126 | 44 | 510-75618 |  |  |  | TP1,TP2,TP3,TP4,TP5,TP6,TP7,TP8,TP9,TP10,TP11,TP12,TP13,TP14,TP15,TP16,TP17,TP18,TP19,TP20,TP21,TP22,TP23,TP24,TP25,TP26,TP27,TP28,TP29,TP30,TP31,TP32,TP33,TP34,TP35,TP36,TP37,TP38,TP39,TP40,TP41,TP42,TP43,TP44 |  |  | TEST POINT PAD .035 SMT, no part to order | TP_35MIL | testpoint_35mil
127 | 1 | 180-75635 |  |  |  | T1 | TDK | ACM12V-701-2PL-TL00 | IND CHK 700 OHM @ 100MHZ 8A -- 12V | ACM12V-701-2PL-TL00 | ind_acm12v
128 | 1 | 312-82330 |  |  |  | U1 | NXP SEMICONDUCTORS | PCF2131TFY | IC RTC CALENDAR W/XTAL TCXO 3.3V AEC-Q100 HLSON16 | PCF2131TFY | so16_0p5_3p5x4p5_mm
129 | 2 | 315-84061 |  |  |  | U2,U23 | NEXPERIA | PCMF1USB3SZ | IC EMI FILTER ESD PROTECTION 15kV/LINE WLCSP5 | PCMF1USB3S | wlcsp5_0p4_0p82x1p22
130 | 2 | 315-83650 |  |  |  | U3,U37 | Nexperia | 74AVC4T3144GU12-QX | IC BUF DUAL 4BIT TRI-STATE 0.8-3.6V AEC-Q100 XQFN12 | 74AVC4T3144GU12-QX | xqfn12_0p4_1p8x2p1
131 | 1 | 312-81433 |  |  |  | U4 | NXP SEMICONDUCTORS | PCAL6416AHF,128 | IC 16-BIT I2C-BUS I/O EXPANDER 1.65V-5.5V HWQFN24 | PCAL6416AHF | qfn24_4x4_ep2p1mm
132 | 1 | 312-82397 |  |  |  | U5 | NXP SEMICONDUCTORS | PCAL6408AHK | IC I/O EXPANDER I2C 8-BIT 1.65-5.5V XQFN16 | PCAL6408AHK | pqfn16_0p4_2p65x1p85
133 | 4 | 315-81116 |  |  |  | U6,U11,U27,U28 | NXP SEMICONDUCTOR | NX20P5090UKAZ | IC USB PWR SW 5A 2.5-20V WLCSP15 | NX20P5090UK | wlcsp15_0p5_1p57x2p59
134 | 1 | 312-10028 |  |  |  | U7 | Renesas Electronics Corporation | 9DBL0455NLGI8 | IC BUF PCIe GEN 1-5 CLK FANOUT 4-OUTPUT 3.3V VFQFPN20 | 9DBL0455NLGI8 | vfqfpn20p_0p5_sq4p1
135 | 1 | TMP-CIP-23515 |  |  | 315-11003 | U8 | NXP SEMICONDUCTOR | PPF5301BMMABES | IC PMIC BUCK 0.5-1.2V 8A 5V AEC-Q100 HWQFN24 | PPF5301BMMABES | hfcpqfn24_0p5_3p5x4p5
136 | 1 | 315-84157 |  |  |  | U9 | NXP SEMICONDUCTOR | MPF0900AMBA1ES | IC POWER MANAGEMENT 9CH -0.3-6V AEC-Q100 QFN56 | MPF0900AMBA1ES | PQFN56_0P5_8X8MM
137 | 1 | 315-81642 |  |  |  | U10 | NXP SEMICONDUCTOR | PCAL6524HEAZ | IC I/O EXPANDER 24-BIT I2C 0.8-3.6V/1.65-5.5V UQFN32 | PCAL6524HEAZ | uqfn32_0p5_5x5_ep3x3
138 | 1 | 330-10048 |  |  |  | U12 | NXP SEMICONDUCTOR | MIMX9596XVZXNAC | IC MPU 6x A-Cores 1.8GHz PBGA716 | MIMX9596XVZXNAC | pbga716_0p7_19x19mm_sot2202-1
139 | 1 | 312-10404 |  |  |  | U13 | Texas Instruments | LM5143QRHARQ1 | IC SYNC BUCK CTLR 3.5-65V AEC-Q100 VFQFN40 | LM5143QRHARQ1 | vqfn40p_0p5_sq6p1_ep3p3
140 | 1 | 334-10110 |  |  |  | U14 | MICRON | MT62F4G32D8DV-020FAAT:D | IC MEM LPDDR5 SDRAM 16GB 4GX32 208pS 1.8V/1.05V/0.9V/0.5V AEC-Q100 LFBGA315 | MT62F4G32D8DV-020FAAT:D | bga315_0p7_12p5x15p1mm
141 | 1 | 342-00952 |  |  |  | U15 | MICRON | MTFC64GBCAQTC-AAT | IC MEM EMMC NAND FLASH 64GB 1.8,3.3V/3.3V FBGA153 | MTFC64GBCAQTC-AAT | fbga153_0p5_11p5x13_c012
142 | 1 | 342-00785 |  |  |  | U16 | MACRONIX INTERNATIONAL CO., LTD | MX25UM51345GXDI00 | IC MEM FLASH 512 Mbit (64 Mbyte) Octal SPI 1.8V 200MHz DTR BGA24 | MX25UM51345GXDI00 | pbga24_1_6x8mm
143 | 1 | TMP-CIP-23516 |  |  | 312-10616 | U17 | NXP SEMICONDUCTOR | PPF5302BMMAAES | IC PMIC BUCK 0.5-1.2V 15A 5V AEC-Q100 HWQFN24 | PPF5302BMMAAES | hfcpqfn24_0p5_3p5x4p5
144 | 1 | 312-10101 |  |  |  | U18 | Bosch Sensortec GmbH | BMM350 | IC GEOMAGNETIC SENSOR 3-AXIS I2C/I3C 1.72-1.98/1.72-3.6V WLCSP9 | BMM350 | wlcsp9_0p4_1p28sq
145 | 1 | 315-10191 |  |  |  | U19 | Texas Instruments | LP5907SNX-1.8/NOPB | IC VREG LDO 1.8V 250mA 2.2V-5.5V X2SON4 | LP5907SNX-1.8/NOPB | xson4_0p65_sq1p05mm_a
146 | 1 | 312-10157 |  |  |  | U20 | Bosch Sensortec GmbH | BMP581 | IC PRESSURE SENSOR 300-1100hPA I2C SPI 1.71-3.6V LGA10 | BMP581 | lga10_0p5_2x2
147 | 2 | 315-83385 |  |  |  | U21,U26 | NXP SEMICONDUCTOR | NX20P0477UKZ | IC USB TYPE C PROTECTION 6KV/8KV 2.5-5.5V WLCSP9 | NX20P0477 | wlcsp9_0p5_1p49x1p49mm
148 | 2 | 315-82529 |  |  |  | U22,U24 | NEXPERIA | PCMF2USB3BA/C | IC EMI FILTER FOR DIFF CH W/BI-DIR ESD PROTECTION 4V WLCSP10 | PCMF2USB3BA/C | wlcsp10_0p4_1p2x1p6mm_smdp
149 | 1 | 312-82774 |  |  |  | U25 | NXP SEMICONDUCTORS | SE051C2HQ1/Z01XD | IC PLUG AND TRUST SECURE ELEMENT 1.62-3.6V HX2QFN20 | SE051C2HQ1/Z01XD | qfn20_0p4_3x3_tab_1p9
150 | 2 | 315-81118 |  |  |  | U29,U32 | NXP SEMICONDUCTOR | PTN5110NHQZ | IC USB PD PHY 1PORT 2.7-5.5V HX2QFN16 | PTN5110 | hx2qfn16_0p4_2p7x2p7
151 | 1 | 315-10403 |  |  |  | U30 | TDK | ICM-45686 | IC MEMS 6-AXIS MOTION SENSOR 1.71-3.6V LGA14 | ICM-45686 | lga14_0p5_3x2p5
152 | 1 | TMP-CIP-13687 |  |  | 312-83839 | U31 | NXP SEMICONDUCTOR | P3H2840HN | IC I3C HUB 2 CTLER 8PORT 1.0/1.2/1.8V HVQFN28 | P3H2840HN | qfn28_0p4_4x4_ep2p6
153 | 1 | 312-83520 |  |  |  | U33 | NEXPERIA | 74AUP1G08GW-Q100 | IC GATE AND 2 INPUT 0.8-3.6V AEC-Q100 TSSOP5 | 74AUP1G08GW-Q100 | sc70-5
154 | 1 | 312-10081 |  |  |  | U34 | NXP SEMICONDUCTOR | P3A1604UKAZ | IC XCVR 4BIT DUAL SUPPLY 0.72V-1.98V/1.62V-3.63V WLCSP12 | P3A1604UKAZ | wlcsp12_0p35_1p05x1p40
155 | 1 | 315-10156 |  |  |  | U35 | REALTEK SEMICONDUCTOR | RTL8211FSI-VS-CG | IC XCVR ETH 10/100/1000MBPS RGMII 3.3/2.5/1.8/1.5V QFN48 | RTL8211FS(I)(-VS)-CG | qfn_48_0p4_6x6mm
156 | 1 | 312-10094 |  |  |  | U36 | MURATA | LBES5PL2EL-923 | IC WIFI/BT MODULE 802.11A/B/G/N/AC/AX SISO 2.4GHz-5GHz SMT | LBES5PL2EL-923 | module107_9p0x7p9mm
157 | 1 | 230-78587 |  |  |  | Y1 | NDK | NX3215SA-32.768kHz-EXS00A-MU01567 | XTAL 32.768kHZ 7pF 20ppm -- SMT | 32.768kHz | xtl2_3p2x1p5
158 | 1 | 230-78532 |  |  |  | Y2 | MURATA | XRCGB24M000F3A13R0 | XTAL 24MHz -- 30PPM 8pF SMT | 24 MHz | xtl4_2p1x1p7mm_sm
159 | 1 | 230-78498 |  |  |  | Y3 | Silicon Labs | 511DBA156M250BAG | OSC 156.25MHZ HCSL 25PPM 3.3V 5X3.2MM SMT | 156.25MHz | osc6_1p27_5p2x3p4
160 | 1 | 230-10039 |  |  |  | Y4 | ECS INC. INTERNATIONAL | ECS-250-18-37B2-CWN-TR | XTAL 25MHZ -- 18pF 10ppm SMT | 25 MHz | xtal4_2p1x1p7mm_sm

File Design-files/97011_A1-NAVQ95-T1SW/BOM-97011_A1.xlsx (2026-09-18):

NAVQ95-T1SW Revised: Monday, September 14, 2026
SCH-97011 / PDF: SPF-97011 Revision: A1
NXP Semiconductors
High Tech Campus 60
5656AG Eindhoven, Netherlands
Bill Of Materials September 18,2026 10:24:44 | Page1
Item | Quantity | AgilePN | ASSY_OPT | FIND# | PRE_APN | Reference | MFG_NAME01 | MFG_PN01 | Description | Value | PCB Footprint
1 | 3 | 280-10222 |  |  |  | BH1,BH2,BH3 |  |  | MOUNTING HOLE DRILL 3.7MM PAD 6MM PLATED TH NO PART TO ORDER | MH3.7_6 | mh236-146p
2 | 66 | 150-79461 |  |  |  | C1,C3,C4,C6,C7,C8,C10,C13,C14,C16,C17,C29,C30,C31,C39,C45,C50,C53,C61,C67,C84,C85,C87,C88,C89,C93,C94,C96,C102,C103,C109,C110,C112,C113,C115,C116,C117,C118,C125,C126,C127,C129,C134,C139,C142,C145,C147,C149,C150,C151,C152,C154,C155,C156,C159,C160,C161,C162,C163,C164,C165,C166,C167,C168,C169,C170 | MURATA | GCM155R71H104KE02D | CAP CER 0.1uF 50V 10% X7R AEC-Q200 0402 | 0.1uF | CC0402_25
3 | 4 | 150-81482 |  |  |  | C2,C106,C108,C122 | MURATA | GRT188C71C475KE13 | CAP CER 4.7uF 16V 10% X7S AEC-Q200 0603 | 4.7uF | CC0603_OV
4 | 24 | 150-81359 |  |  |  | C5,C9,C11,C12,C15,C28,C32,C46,C54,C82,C83,C90,C95,C97,C101,C104,C119,C121,C128,C132,C140,C143,C148,C153 | MURATA | GRM155Z71A105KE01J | CAP CER 1uF 10V 10% X7R 0402 | 1uF | CC0402_25
5 | 2 | 150-79051 | DNP |  |  | C18,C80 | MURATA | GCM155R71H103KA55D | CAP CER 0.01uF 50V 10% X7R AEC-Q200 0402 | 0.01uF | CC0402_25
6 | 59 | 150-80124 |  |  |  | C19,C20,C21,C22,C23,C24,C25,C26,C27,C33,C34,C35,C36,C37,C38,C40,C41,C42,C43,C44,C47,C48,C49,C51,C52,C55,C56,C57,C58,C59,C60,C62,C63,C64,C65,C66,C68,C69,C70,C71,C72,C73,C74,C75,C76,C77,C78,C79,C81,C105,C107,C133,C135,C136,C137,C138,C141,C144,C146 | MURATA | GRM033Z71C104KE14 | CAP CER 0.1uF 16V 10% X7R 0201 | 0.1uF | CC0201
7 | 3 | 150-81133 |  |  |  | C86,C120,C157 | MURATA | GRM188Z71A106KA73D | CAP CER 10uF 10V 10% X7R 0603 | 10uF | CC0603_OV
8 | 7 | 150-81481 |  |  |  | C91,C92,C99,C100,C114,C130,C131 | MURATA | GRT21BD71A226ME13 | CAP CER 22uF 10V 20% X7T AEC-Q200 0805 | 22uF | CC0805_OV
9 | 2 | 150-81792 |  |  |  | C98,C171 | MURATA | GCM31C5C3A102JX03 | CAP CER 1000pF 1000V 5% C0G AEC-Q200 1206 | 1000pF | CC1206_OV
10 | 2 | 150-76336 |  |  |  | C111,C124 | MURATA | GJM1555C1H8R0CB01D | CAP CER 8.0pF 50V 3.12% C0G 0402 | 8.0pF | CC0402_25
11 | 8 | 150-80055 |  |  |  | C123,C158,C172,C173,C174,C175,C176,C177 | YAGEO AMERICA | AC0603KRX7R0BB472 | CAP CER 4700pF 100V 10% X7R AEC-Q200 0603 | 4700pf | CC0603_OV
12 | 9 | 370-76670 |  |  |  | D1,D3,D5,D6,D7,D8,D9,D10,D11 | WURTH ELEKTRONIK EISOS GMBH & CO. KG (ELECTRONIC & ELECTROMEHANICAL COMP) | 150060VS75000 | LED BRIGHT GRN SGL 30mA 0603 | LED_GRN | LED_0603
13 | 2 | 370-76859 |  |  |  | D2,D4 | WURTH ELEKTRONIK EISOS GMBH & CO. KG (ELECTRONIC & ELECTROMEHANICAL COMP) | 150060AS75000 | LED AMB SGL 2V 20mA 0603 | LED_AMB | LED_0603
14 | 8 | 480-80185 |  |  |  | D12,D13,D14,D15,D16,D17,D18,D19 | NEXPERIA | PESD2ETH1G-T | DIODE 2 CH ESD PROTECTOR 30KV 24V AEC-Q101 SOT23 | PESD2ETH1G-T | sot23_a
15 | 1 | 210-80888 |  |  |  | J2 | SAMTEC | SHF-105-01-L-D-RA | CON 2X5 TH SHRD PLUG RA 50MIL CTR 225H AU 75L | SHF-105-01-L-D-RA | con2x5_50_th_ra
16 | 2 | 210-83192 |  |  |  | J3,J4 | HARTING | 9452812800 | CON 1X2 JACK 1 PORT TH 2.8MM SP 244H -- 91L | CON JACK | con2_2p8_jack_th
17 | 6 | 211-80595 |  |  |  | J5,J6,J7,J8,J9,J10 | JST MFG. CO | SM02B-GHS-TB(LF)(SN) | CON 1X2 CRIMP RA 1.25MM SP 173H SN SMT | SM02B-GHS-TB(LF)(SN) | con_1x2_1p25_5p8x4p1_sm_ra
18 | 3 | 180-78924 |  |  |  | LBK1,LBK2,LBK3 | TDK | TFM252012ALMAR47MTAA | IND PWR 0.47uH@1MHz 5.8A 20% AEC-Q200 SMT | 0.47 uH | ind2520
19 | 11 | 180-78156 |  |  |  | L1,L2,L3,L4,L6,L7,L8,L9,L20,L21,L22 | TDK | MPZ1608S331A | IND FER BEAD 330OHM@100MHZ 1.7A 0603 | 330 OHM | ind_1608
20 | 10 | 180-81335 |  |  |  | L5,L10,L11,L12,L13,L14,L15,L16,L18,L19 | Murata Electronics | BLM15AG121SH1D | IND FER BEAD 120 OHM@100MHZ 0.5A 0.25 OHM 25% AEC-Q200 0402 | 120 OHM@100MHZ | IND_0402
21 | 2 | 180-81135 |  |  |  | L17,L23 | MURATA | DLW32MH101XT2 | IND CHK COMMON MODE 100uH@100KHz 100mA 2.6 OHM -25-50% AEC-Q200 SMT | DLW32MH101XT2 | ind_3p4x2p7_smt
22 | 6 | 180-78762 |  |  |  | L24,L25,L26,L27,L28,L29 | TDK | ACT1210L-201-2P-TL00 | FILTER COMMON MODE 200uH@100KHZ 70mA +30/-10% AEC-Q200 SMT | 200uH @ 100KHz | ind_act1210_sm
23 | 1 | 211-10510 |  |  |  | P17 | HIROSE | DF40TC-50DP-0.4V(51) | CON 2X25 PLUG SHRD SMT 0.4MM SP 51H AU | CON PLUG 2X25 | con50_0p4_11p72x2p05_sm_a
24 | 1 | 480-10103 |  |  |  | Q1 | Nexperia | NX3020NAKW,115 | TRAN NMOS SW 30V 180mA SC-70 | NX3020NAKW,115 | sc70_3
25 | 35 | 470-81195 |  |  |  | R1,R3,R8,R11,R16,R20,R33,R36,R37,R40,R43,R45,R47,R50,R55,R56,R57,R58,R59,R60,R61,R62,R63,R64,R71,R75,R76,R79,R80,R83,R89,R90,R94,R98,R100 | PANASONIC | ERJ-2GEJ103X | RES MF 10K OHM 5% 1/10W AEC-Q200 0402 | 10K | RC0402_25
26 | 19 | 470-10144 |  |  |  | R2,R5,R6,R9,R14,R15,R18,R31,R32,R38,R39,R42,R44,R48,R51,R52,R91,R92,R99 | YAGEO AMERICA | AC0402JR-070RL | RES MF ZERO OHM JUMPER 1/16W 5% AEC-Q200 0402 | 0 OHM | rc0402_25
27 | 7 | 470-80064 |  |  |  | R4,R102,R103,R104,R105,R106,R107 | KOA SPEER | RK73B1JTTD391J | RES MF 390 OHM 1/8W 5% AEC-Q200 0603 | 390 | RC0603_OV
28 | 2 | 470-82544 |  |  |  | R7,R12 | YAGEO AMERICA | AC0402FR-072K2L | RES MF 2.2K 1/16W 1% AEC-Q200 0402 | 2.2K | RC0402_25
29 | 6 | 470-83517 |  |  |  | R10,R17,R19,R26,R27,R41 | YAGEO AMERICA | AC0402FR-13100KL | RES MF 100K 1% 1/16W AEC-Q200 0402 | 100k | RC0402_25
30 | 6 | 470-81195 | DNP |  |  | R13,R29,R34,R46,R54,R72 | PANASONIC | ERJ-2GEJ103X | RES MF 10K OHM 5% 1/10W AEC-Q200 0402 | 10K | RC0402_25
31 | 10 | 470-10144 | DNP |  |  | R21,R22,R23,R24,R25,R28,R35,R49,R85,R86 | YAGEO AMERICA | AC0402JR-070RL | RES MF ZERO OHM JUMPER 1/16W 5% AEC-Q200 0402 | 0 OHM | rc0402_25
32 | 1 | 470-81665 |  |  |  | R30 | KOA SPEER | RK73H1ETTP6491F | RES MF 6.49K 1/10W 1% AEC-Q200 0402 | 6.49K | RC0402_25
33 | 1 | 470-83517 | DNP |  |  | R53 | YAGEO AMERICA | AC0402FR-13100KL | RES MF 100K 1% 1/16W AEC-Q200 0402 | 100k | RC0402_25
34 | 5 | 470-81990 |  |  |  | R65,R68,R69,R84,R88 | KOA SPEER | RK73H1ETTP1501F | RES MF 1.50K 1/10W 1% AEC-Q200 0402 | 1.5K | RC0402_25
35 | 1 | 470-81990 | DNP |  |  | R66 | KOA SPEER | RK73H1ETTP1501F | RES MF 1.50K 1/10W 1% AEC-Q200 0402 | 1.5K | RC0402_25
36 | 2 | 470-30326 |  |  |  | R67,R70 | YAGEO AMERICA | RC0402JR-07200KL | RES MF 200K 1/16W 5% 0402 | 200K | RC0402_25
37 | 2 | 470-82112 |  |  |  | R73,R108 | KOA SPEER | RK73B2BTTD105J | RES MF 1.0M 1/4W 5% AEC-Q200 1206 | 1.0M | RC1206_OV
38 | 4 | 470-77301 |  |  |  | R74,R77,R93,R95 | PANASONIC | ERJ-2GEJ681X | RES MF 680 OHM 1/16W 5% 0402 | 680 | RC0402_25
39 | 8 | 470-81181 |  |  |  | R78,R96,R121,R122,R123,R124,R125,R126 | VISHAY INTERTECHNOLOGY | CRCW0603100KFKEAHP | RES MF 100K 1/4W 1% AEC-Q200 0603 | 100K | RC0603_OV
40 | 1 | 470-83520 |  |  |  | R81 | YAGEO | AC0402JR-07100RL | RES MF 100 OHM 1/16W 5% AEC-Q200 0402 | 100 | rc0402_25
41 | 16 | 470-81930 |  |  |  | R82,R87,R97,R101,R109,R110,R111,R112,R113,R114,R115,R116,R117,R118,R119,R120 | ROHM | ESR10EZPF1001 | RES MF 1.0K 0.4W 1% AEC-Q200 0805 | 1.0K | RC0805_OV
42 | 1 | 510-78408 |  |  |  | S1 | NIDEC COPAL ELECTRONICS CORP | CHS-01TA1 | SW DIP 1 POS 0.025A@24VDC SMT | CHS-01TA1 | sw_2p8x5p7_sm
43 | 1 | 510-78644 |  |  |  | S2 | NIDEC COPAL ELECTRONICS CORP | CHS-02TA | SW SPST SLD WSH 25MA 24V DIP-2 SMT | CHS-02TA | sw4_dip_1p27_4p4x5p7
44 | 8 | 510-75618 |  |  |  | TP1,TP2,TP3,TP4,TP5,TP6,TP7,TP8 |  |  | TEST POINT PAD .035 SMT, no part to order | TP_35MIL | testpoint_35mil
45 | 2 | 315-84354 |  |  |  | U1,U2 | NXP SEMICONDUCTOR | PCA9306JKZ | IC DUAL BI I2C BUS SMBUS VOLTAGE TRANSLATOR 1-3.6V/1.8-5.5V X2SON8 | PCA9306JK | x2son8_0p35_1x1p35mm
46 | 1 | 312-82081 |  |  |  | U3 | ISSI | IS25LP080D-JNLE-TR | IC SERIAL FLASH MEMORY SPI 128BIT 2.30V 3.60V SOIC8 DATE CODE MUST BE 1925 OR HIGHER | IS25LP080D-JNLE | so8_1p27_4x5
47 | 2 | 312-83772 |  |  |  | U4,U7 | NXP SEMICONDUCTORS | TJA1120BHN | IC ETH PHY 3.3V AEC-Q100 HVQFN36 | TJA1120BHN | qfn36_0p5_6x6_sot1092-2
48 | 1 | 315-10678 |  |  |  | U5 | NXP SEMICONDUCTOR | PPF5103AMMAFES | IC POWER MANAGEMENT 5.5V AEC-Q100 QFN28 | PPF5103AMMAFES | sot2089-1_fcqfn28_0p5_4p5sq
49 | 1 | 330-77155 |  |  |  | U6 | NXP SEMICONDUCTOR | SJA1110AEL | IC ETHERNET SW WITH EMBEDDED PHYS AND CPU 3.3V AUTO BGA256A | SJA1110AEL | bga256_0p8_14x14mm_059h
50 | 1 | 230-78230 |  |  |  | X1 | MURATA | XRCGB25M000F3A00R0 | XTAL 25.000MHZ 30PPM 6PF AEC-Q200 SMT | 25MHz | xtl4_2p1x1p7mm_sm

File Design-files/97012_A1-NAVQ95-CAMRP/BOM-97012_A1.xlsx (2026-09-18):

NAVQ95-CAMRP Revised: Monday, September 14, 2026
SCH-97012 / PDF: SPF-97012 Revision: A1
NXP Semiconductors
High Tech Campus 60
5656AG Eindhoven, Netherlands
Bill Of Materials September 18,2026 10:44:08 | Page1
Item | Quantity | AgilePN | ASSY_OPT | FIND# | PRE_APN | Reference | MFG_NAME01 | MFG_PN01 | Description | Value | PCB Footprint
1 | 4 | 280-10222 |  |  |  | BH1,BH2,BH3,BH4 |  |  | MOUNTING HOLE DRILL 3.7MM PAD 6MM PLATED TH NO PART TO ORDER | MH3.7_6 | mh236-146p
2 | 6 | 150-79461 |  |  |  | C6,C10,C11,C12,C13,C14 | MURATA | GCM155R71H104KE02D | CAP CER 0.1uF 50V 10% X7R AEC-Q200 0402 | 0.1uF | CC0402_25
3 | 3 | 150-81359 |  |  |  | C7,C8,C9 | MURATA | GRM155Z71A105KE01J | CAP CER 1uF 10V 10% X7R 0402 | 1uF | CC0402_25
4 | 4 | 480-79837 |  |  |  | D1,D2,D3,D4 | NEXPERIA | IP4292CZ10-TBR,115 | DIODE ESD TVS ARRAY USB2 USB3 5.5V 4A DFN2510A-10 | IP4292CZ10-TBR | xson10_0p5_1p1x2p6mm
5 | 1 | 480-78222 |  |  |  | D5 | TYCO ELECTRONICS | PESD0402-140 | DIODE BIDIR ESD PROT 14V 0402 | PESD0402 | 0402_mlp
6 | 2 | 150-81001 |  |  |  | FL1,FL2 | MURATA | NFM15PC104R1A3D | CAP FILTER EMI 0.1uF 10V 20% -- 0402 | 0.1uF | cc_fil_0402
7 | 1 | 211-10530 |  |  |  | J3 | AMPHENOL | F32Q-1A7H1-11022 | CON 1X22 FPC/FFC RA SMT UPPER CONTACT 0.5MM SP 87H AU | CONN FPC/FFC 22 | con_ffc_22_0p5_sm_ra_87h
8 | 1 | 210-80138 | DNP |  |  | J4 | SAMTEC | TSW-103-08-F-S-RA | HDR 1X3 RA TH 100MIL SP 124H AU 90L | HDR 1X3 RA | hdr1x3m_100_th_ra
9 | 1 | 211-10508 |  |  |  | P14 | HIROSE | DF40TC-40DP-0.4V(51) | CON 2X20 PLUG SHRD SMT 0.4MM SP 51H AU | CON PLUG 2X20 | con_2x20_0p4_9p52x1p85_sm
10 | 1 | 470-30326 |  |  |  | R5 | YAGEO AMERICA | RC0402JR-07200KL | RES MF 200K 1/16W 5% 0402 | 200K | RC0402_25
11 | 5 | 470-10144 |  |  |  | R8,R9,R10,R42,R43 | YAGEO AMERICA | AC0402JR-070RL | RES MF ZERO OHM JUMPER 1/16W 5% AEC-Q200 0402 | 0 OHM | rc0402_25
12 | 4 | 470-82544 |  |  |  | R38,R39,R40,R41 | YAGEO AMERICA | AC0402FR-072K2L | RES MF 2.2K 1/16W 1% AEC-Q200 0402 | 2.2K | RC0402_25
13 | 1 | 510-75618 |  |  |  | TP1 |  |  | TEST POINT PAD .035 SMT, no part to order | TP_35MIL | testpoint_35mil
14 | 1 | 315-84354 |  |  |  | U1 | NXP SEMICONDUCTOR | PCA9306JKZ | IC DUAL BI I2C BUS SMBUS VOLTAGE TRANSLATOR 1-3.6V/1.8-5.5V X2SON8 | PCA9306JK | x2son8_0p35_1x1p35mm

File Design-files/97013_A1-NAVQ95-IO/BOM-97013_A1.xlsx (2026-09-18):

NAVQ95-IO Revised: Wednesday, September 16, 2026
SCH-97013 / PDF: SPF-97013 Revision: A1
NXP Semiconductors
High Tech Campus 60
5656AG Eindhoven, Netherlands
Bill Of Materials September 18,2026 10:55:57 | Page1
Item | Quantity | AgilePN | ASSY_OPT | FIND# | PRE_APN | Reference
1 | 3 | 280-10222 |  |  |  | BH1,BH2,BH3 |  |  | MOUNTING HOLE DRILL 3.7MM PAD 6MM PLATED TH NO PART TO ORDER | MH3.7_6 | mh236-146p
2 | 25 | 150-79461 |  |  |  | C1,C2,C3,C4,C8,C17,C23,C24,C29,C35,C36,C37,C41,C42,C44,C45,C53,C55,C58,C63,C66,C73,C74,C75,C76 | MURATA | GCM155R71H104KE02D | CAP CER 0.1uF 50V 10% X7R AEC-Q200 0402 | 0.1uF | CC0402_25
3 | 12 | 150-81359 |  |  |  | C5,C6,C7,C10,C16,C20,C28,C33,C40,C47,C49,C52 | MURATA | GRM155Z71A105KE01J | CAP CER 1uF 10V 10% X7R 0402 | 1uF | CC0402_25
4 | 2 | 150-79023 | DNP |  |  | C9,C11 | MURATA | GCM1555C1H100JA16 | CAP CER 10pF 50V 5% C0G AEC-Q200 0402 | 10pF | CC0402_25
5 | 3 | 150-10445 |  |  |  | C12,C13,C14 | MURATA | GRM155Z71A225KE44D | CAP CER 2.2UF 10V 10% X7R 0402 | 2.2uF | cc0402_tol0p2_ov
6 | 10 | 150-81482 |  |  |  | C15,C19,C21,C22,C50,C56,C61,C65,C68,C69 | MURATA | GRT188C71C475KE13 | CAP CER 4.7uF 16V 10% X7S AEC-Q200 0603 | 4.7uF | CC0603_OV
7 | 2 | 150-81133 |  |  |  | C18,C25 | MURATA | GRM188Z71A106KA73D | CAP CER 10uF 10V 10% X7R 0603 | 10uF | CC0603_OV
8 | 3 | 150-79034 |  |  |  | C26,C31,C38 | MURATA | GCM155R71H472KA37D | CAP CER 4700pF 50V 10% X7R AEC-Q200 0402 | 4700pF | CC0402_25
9 | 6 | 150-79727 |  |  |  | C27,C30,C32,C34,C39,C43 | MURATA | GCM155R71C473KA37D | CAP CER 0.047uF 16V 10% X7R AEC-Q200 0402 | 0.047uF | CC0402_25
10 | 9 | 150-81211 |  |  |  | C46,C51,C54,C57,C60,C62,C67,C70,C71 | Yageo | CC0402JRNPO9BN150 | CAP CER 15PF 50V 5% C0G 0402 | 15pF | CC0402_25
11 | 1 | 150-81481 | DNP |  |  | C48 | MURATA | GRT21BD71A226ME13 | CAP CER 22uF 10V 20% X7T AEC-Q200 0805 | 22uF | CC0805_OV
12 | 2 | 150-79047 |  |  |  | C59,C64 | MURATA | GCM1555C1H221JA16D | CAP CER 220pF 50V 5% C0G AEC-Q200 0402 | 220pF | CC0402_25
13 | 1 | 150-79040 |  |  |  | C72 | MURATA | GCM155R71H102KA37D | CAP CER 1000pF 50V 10% X7R AEC-Q200 0402 | 1000pF | CC0402_25
14 | 2 | 370-76859 |  |  |  | D1,D3 | WURTH ELEKTRONIK EISOS GMBH & CO. KG (ELECTRONIC & ELECTROMEHANICAL COMP) | 150060AS75000 | LED AMB SGL 2V 20mA 0603 | LED_AMB | LED_0603
15 | 5 | 370-76670 |  |  |  | D2,D4,D10,D13,D17 | WURTH ELEKTRONIK EISOS GMBH & CO. KG (ELECTRONIC & ELECTROMEHANICAL COMP) | 150060VS75000 | LED BRIGHT GRN SGL 30mA 0603 | LED_GRN | LED_0603
16 | 12 | 480-78222 |  |  |  | D5,D8,D9,D11,D12,D14,D16,D18,D24,D25,D26,D27 | TYCO ELECTRONICS | PESD0402-140 | DIODE BIDIR ESD PROT 14V 0402 | PESD0402 | 0402_mlp
17 | 1 | 370-76671 |  |  |  | D6 | WURTH ELEKTRONIK EISOS GMBH & CO. KG (ELECTRONIC & ELECTROMEHANICAL COMP) | 150060SS75000 | LED ULTRA BRIGHT RED SGL 30mA 5V 0603 | LED_SUPER_RED | LED_0603
18 | 1 | 370-76822 |  |  |  | D7 | WURTH ELEKTRONIK EISOS GMBH & CO. KG (ELECTRONIC & ELECTROMEHANICAL COMP) | 150352M173300 | LED RGB SGL 30mA 2/3.2/3.2V SMT | 150352M173300 | led6_0p85_3p25x2p85_sm
19 | 6 | 480-10614 |  |  |  | D15,D19,D20,D21,D22,D23 | ON SEMICONDUCTOR | SZESD7104MUTAG | DIODE TVS 4LINE ESD PROTECT AEC-Q101 UDFN10 | SZESD7104MUTAG | udfn10_2p5x1
20 | 8 | 150-81001 |  |  |  | FL1,FL2,FL3,FL4,FL5,FL6,FL7,FL8 | MURATA | NFM15PC104R1A3D | CAP FILTER EMI 0.1uF 10V 20% -- 0402 | 0.1uF | cc_fil_0402
21 | 1 | 211-10495 |  |  |  | J1 | Same Sky | UJ20-C-H-G-SMT-1-P16-TR | CON 2X8 USB2.0_TYPE_C RCPT SMT RA 0.5MM 131H AU | USB_TYPE_C | con16f_usb_type-c_ra_sm
22 | 1 | 210-10637 |  |  |  | J2 | JST MFG. CO | B4B-PH-K-S | CON 1X4 PLUG SHRD TH 2MM SP 236H SN 133L | CON 1X4 PLUG | con_ph_4m_2mm_th
23 | 3 | 211-80226 |  |  |  | J3,J4,J5 | JST MFG. CO | SM04B-GHS-TB(LF)(SN) | CON 1X4 CRIMP SMT RA 1.25MM SP 173H SN | CON_1X4 | con_1x4_1p25_8p25x4p25_sm_ra
24 | 1 | 211-80220 |  |  |  | J6 | JST MFG. CO | BM06B-GHS-TBT(LF)(SN)(N) | CON 1X6 CRIMP SMT 1.25MM SP 159H SN | CON_1X6 | con_1x6_1p25_10p75x4p25_sm
25 | 1 | 211-80221 |  |  |  | J7 | JST MFG. CO | BM04B-GHS-TBT(LF)(SN)(N) | CON 1X4 CRIMP SMT 1.25MM SP 159H SN | CON_1X4 | con_1x4_1p25_8p25x4p25_sm
26 | 2 | 211-81987 |  |  |  | J8,J9 | JST Sales America Inc. | SM10B-GHS-TB(LF)(SN) | CON 1X10 PLUG SMT RA 1.25MM SP 173H SN | CON 1X10 SM | con10_1p25_15p75x4p05_sm
27 | 1 | 211-83379 |  |  |  | J12 | Tensility International Corp | 54-00177 | CON 6 AUD JACK FEMALE 3.5MM RA SMD 185H AU | CONN AUDIO 6 | con6p_jack_smt
28 | 7 | 180-81279 |  |  |  | L1,L2,L9,L10,L11,L12,L13 | MURATA | BLM18PG121SZ1 | IND FER BEAD 120OHM@100MHZ 2A 25% AEC-Q200 0603 | 120OHM@100MHZ | IND_0603
29 | 6 | 180-78352 |  |  |  | L3,L4,L5,L6,L7,L8 | MURATA | BLM18KG121TZ1 | IND FER BEAD 120OHM@100MHZ 3A 25% AEC-Q200 0603 | BLM18KG121TZ1 | IND_0603
30 | 2 | 211-10558 |  |  |  | P3,P4 | HIROSE | DF40TC(3.0)-50DP-0.4V(51) | CON 2X25 PLUG SHRD SMT 0.4MM SP 170H AU | CON 2X25 | con_rcpt_2x25_0p4mm_sm
31 | 1 | 480-79692 |  |  |  | Q1 | NEXPERIA | NX3020NAKS,115 | TRAN NMOS SW DUAL 180MA 30V 4.5 OHM SOT363 | NX3020NAKS | sot-363_0p65_smt
32 | 1 | 480-78353 |  |  |  | Q2 | ALPHA AND OMEGA SEMICONDUCTOR | AO3400A | TRAN NMOS SW 5.7A 30V SOT23 | AO3400A | sot-23w
33 | 43 | 470-10144 |  |  |  | R1,R3,R4,R7,R14,R20,R28,R31,R36,R41,R43,R44,R45,R49,R51,R52,R59,R61,R70,R73,R75,R76,R78,R79,R80,R83,R84,R88,R89,R90,R91,R92,R94,R95,R97,R100,R103,R105,R106,R107,R108,R109,R110 | YAGEO AMERICA | AC0402JR-070RL | RES MF ZERO OHM JUMPER 1/16W 5% AEC-Q200 0402 | 0 OHM | rc0402_25
34 | 2 | 470-83517 | DNP |  |  | R2,R77 | YAGEO AMERICA | AC0402FR-13100KL | RES MF 100K 1% 1/16W AEC-Q200 0402 | 100k | RC0402_25
35 | 1 | 470-81704 |  |  |  | R5 | KOA SPEER | RK73H1ETTP2402F | RES MF 24K 1/10W 1% AEC-Q200 0402 | 24K | RC0402_25
36 | 1 | 470-81731 | DNP |  |  | R6 | KOA SPEER | RK73H1ETTP4702F | RES MF 47K 1/10W 1% AEC-Q200 0402 | 47K | RC0402_25
37 | 2 | 470-81628 |  |  |  | R8,R9 | KOA SPEER | RK73H1ETTP5101F | RES MF 5.1K 1/10W 1% AEC-Q200 0402 | 5.1K | RC0402_25
38 | 4 | 470-80064 |  |  |  | R10,R25,R101,R104 | KOA SPEER | RK73B1JTTD391J | RES MF 390 OHM 1/8W 5% AEC-Q200 0603 | 390 | RC0603_OV
39 | 21 | 470-81195 |  |  |  | R11,R12,R23,R24,R30,R32,R33,R34,R35,R37,R42,R50,R53,R54,R68,R71,R82,R85,R87,R98,R102 | PANASONIC | ERJ-2GEJ103X | RES MF 10K OHM 5% 1/10W AEC-Q200 0402 | 10K | RC0402_25
40 | 6 | 470-82899 |  |  |  | R13,R15,R26,R27,R46,R47 | VISHAY INTERTECHNOLOGY | CRCW060360R4FKEAHP | RES MF 60.4 OHM 1/3W 1% PULSE PROOF AEC-Q200 0603 | 60.4 | RC0603_OV
41 | 3 | 470-81990 |  |  |  | R16,R17,R18 | KOA SPEER | RK73H1ETTP1501F | RES MF 1.50K 1/10W 1% AEC-Q200 0402 | 1.5K | RC0402_25
42 | 3 | 470-10478 |  |  |  | R19,R22,R57 | STACKPOLE ELECTRONICS | RNCF0402BTE1K00 | RES MF 1K 1/10W 0.1% AEC-Q200 0402 | 1K | RC0402_25
43 | 8 | 470-10144 | DNP |  |  | R21,R29,R48,R60,R69,R74,R93,R96 | YAGEO AMERICA | AC0402JR-070RL | RES MF ZERO OHM JUMPER 1/16W 5% AEC-Q200 0402 | 0 OHM | rc0402_25
44 | 4 | 470-82544 |  |  |  | R38,R39,R55,R56 | YAGEO AMERICA | AC0402FR-072K2L | RES MF 2.2K 1/16W 1% AEC-Q200 0402 | 2.2K | RC0402_25
45 | 1 | 470-30326 |  |  |  | R40 | YAGEO AMERICA | RC0402JR-07200KL | RES MF 200K 1/16W 5% 0402 | 200K | RC0402_25
46 | 1 | 470-82878 |  |  |  | R58 | YAGEO AMERICA | RT0402BRE076K98L | RES MF 6.98K 1/16W 0.1% 0402 | 6.98K | RC0402_25
47 | 4 | 470-77301 |  |  |  | R62,R63,R64,R65 | PANASONIC | ERJ-2GEJ681X | RES MF 680 OHM 1/16W 5% 0402 | 680 | RC0402_25
48 | 2 | 470-80531 |  |  |  | R66,R67 | KOA SPEER | RK73H1ETTP1001F | RES MF 1.0K 1/10W 1% AEC-Q200 0402 | 1.0K | RC0402_25
49 | 2 | 470-82061 |  |  |  | R72,R81 | KOA SPEER | RK73B1ETTP200J | RES MF 20 OHM 1/10W 5% AEC-Q200 0402 | 20 | RC0402_25
50 | 1 | 470-31027 |  |  |  | R86 | YAGEO AMERICA | RC0402FR-0751KL | RES MF 51K 1/16W 1% 0402 | 51K | RC0402_25
51 | 1 | 470-83517 |  |  |  | R99 | YAGEO AMERICA | AC0402FR-13100KL | RES MF 100K 1% 1/16W AEC-Q200 0402 | 100k | RC0402_25
52 | 1 | 510-78339 |  |  |  | SW1 | E SWITCH | TL6330AF200Q | SW SPST NO TACTILE 50mA 12V SMT | TL6330AF200Q | sw4_spst_4p6x2p8_sm
53 | 1 | 510-78408 |  |  |  | S1 | NIDEC COPAL ELECTRONICS CORP | CHS-01TA1 | SW DIP 1 POS 0.025A@24VDC SMT | CHS-01TA1 | sw_2p8x5p7_sm
54 | 12 | 510-75618 |  |  |  | TP1,TP2,TP3,TP4,TP5,TP6,TP7,TP8,TP9,TP10,TP11,TP12 |  |  | TEST POINT PAD .035 SMT, no part to order | TP_35MIL | testpoint_35mil
55 | 1 | 312-81361 |  |  |  | U1 | SILICON LABORATORIES | CP2105-F01-GM | IC XCVR USB TO DUAL-UART 3.0-3.6V QFN24 | CP2105 | QFN24_0P5_4X4_EP
56 | 1 | 315-84061 |  |  |  | U2 | NEXPERIA | PCMF1USB3SZ | IC EMI FILTER ESD PROTECTION 15kV/LINE WLCSP5 | PCMF1USB3S | wlcsp5_0p4_0p82x1p22
57 | 1 | 315-80353 |  |  |  | U3 | CIRRUS LOGIC | WM8962BECSN/R | IC AUDIO CODEC 24BIT DAC 2 CH ADC 1.8V BGA49 | WM8962BECSN/R | BGA49_0P5_3P62X4
58 | 1 | 315-83992 |  |  |  | U4 | NXP SEMICONDUCTOR | NX5P2924DUK | IC PWR SW LOGIC CONTROLED 0.8-5.5V 2.5A WLCSP6 | NX5P2924DUK | wlcsp6_0p5_0p89x1p39
59 | 1 | 315-82308 |  |  |  | U5 | NXP SEMICONDUCTOR | NX5P3363UKZ | IC SW PWR CURRENT LIMITER ADJ 0.4-3.3A 4-5.5V WLCSP16 | NX5P3363UKZ | bga16_0p5_2p23x2p23
60 | 3 | 480-80426 |  |  |  | U6,U9,U12 | Nexperia | PESD2CANFD24L-TR | DIODE 2CH ESD PROTECTOR 24V AEC-Q101 SOT23 | PESD2CANFD24L-TR | SOT23_A
61 | 3 | 312-82303 |  |  |  | U7,U10,U14 | NXP SEMICONDUCTOR | TJA1463ATK/0Z | IC XCVR HIGH SPEED CAN 4.5-5.5V AEC-Q100 HVSON14 | TJA1463ATK | hvson14_0p65_4p6x3p1_ep
62 | 1 | 312-81433 |  |  |  | U8 | NXP SEMICONDUCTORS | PCAL6416AHF,128 | IC 16-BIT I2C-BUS I/O EXPANDER 1.65V-5.5V HWQFN24 | PCAL6416AHF | qfn24_4x4_ep2p1mm
63 | 1 | 315-84354 |  |  |  | U11 | NXP SEMICONDUCTOR | PCA9306JKZ | IC DUAL BI I2C BUS SMBUS VOLTAGE TRANSLATOR 1-3.6V/1.8-5.5V X2SON8 | PCA9306JK | x2son8_0p35_1x1p35mm
64 | 1 | 312-82852 |  |  |  | U13 | Bosch Sensortec | BMI088 | IC ACCELERATION SENSOR 6-AXIS 2/4/8/16G 2.4-3.6V LGA16 | BMI088 | lga16_0p5_3x4p5mm
65 | 1 | 315-83650 |  |  |  | U15 | Nexperia | 74AVC4T3144GU12-QX | IC BUF DUAL 4BIT TRI-STATE 0.8-3.6V AEC-Q100 XQFN12 | 74AVC4T3144GU12-QX | xqfn12_0p4_1p8x2p1
66 | 2 | 510-10150 |  |  |  | U16,U17 | TDK | MMICT5837-00-012 | MICROPHONE DIGITAL MEMS 37dB 27Hz-20kHz 1.65-1.98V LGA7 | MMICT5837-00-012 | lga7_0p82_3p65x2p8
67 | 1 | 230-10159 |  |  |  | Y1 | EPSON | TSX-3225 24.0000MF15X-AC0 | XTAL 24MHz 9pF +/-10PPM -- SMT | 24MHz | xtlosc4_3p2x2p5mm_sm

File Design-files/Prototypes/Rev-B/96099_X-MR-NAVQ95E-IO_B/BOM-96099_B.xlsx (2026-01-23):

X-MR-NAVQ95E-IO Revised: Monday, January 19, 2026
SCH-96099 PDF: SPF-96099 Revision: B
NXP Semiconductors
Bill Of Materials January 19,2026 18:56:22 | Page1
Item | Quantity | AgilePN | ASSY_OPT | FIND# | PRE_APN | Reference | MFG_NAME01 | MFG_PN01 | Description
______________________________________________
1 | 3 | 280-10222 |  |  |  | BH1,BH2,BH3 |  |  | MOUNTING HOLE DRILL 3.7MM PAD 6MM PLATED TH NO PART TO ORDER
2 | 6 | 150-79727 |  |  |  | C1,C2,C6,C7,C11,C12 | MURATA | GCM155R71C473KA37D | CAP CER 0.047uF 16V 10% X7R AEC-Q200 0402
3 | 12 | 150-81359 |  |  |  | C4,C9,C14,C144,C145,C150, | MURATA | GRM155Z71A105KE01J | CAP CER 1uF 10V 10% X7R 0402
 |  |  |  |  |  | C152,C531,C532,C547,C591,
 |  |  |  |  |  | C599
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

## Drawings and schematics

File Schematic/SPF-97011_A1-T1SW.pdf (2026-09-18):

5

4

3

2

1

D | D
C | C
B | B
A | A
X-NAVQ95-T1SW | X1 | 2026-05-29 | JvE (CTO SI) | Initial schematic development
X-NAVQ95-T1SW | A | 2026-06-17 | JvE (CTO SI) | Schematic is released
NAVQ95-T1SW | | 2026-09-09 | | Schematic is released to productionJvE (CTO SI)A1

# NAVQ95-T1SW

By | DescriptionRev. | Date

# Revision History

2. Device type number is for reference only. The number varies with the manufacturer.

# 5. Interpret diagram in accordance with American National Standards Institute specifications, current

revision, with the exception of logic block symbology.

# NOTES:

# 4. Special signal usage:

# 3. Greyed out components indicate

Do Not Populate (DNP) during assembly.

_P and _N denote a differential signal.

# 6. All SILK display properties will be in this color

_B denotes an active-low signal.

# 1. Interrupted lines coded with the same letter or

letter combinations are electrically connected.

# 7. All schematic annotations will be in this color

# Table of Contents

# 01 Cover 02 Tables 03 PF5103 PMIC 04 SJA1110 Power 05 SJA1110 I/O 06 SJA1110 100BASE-T1 PHYs 07 TJA1120 #1 08 TJA1120 #2 09 B2B Interface

# Part of MR-NAVQ95-KIT (97275 rev. A)

# Marketing PN

Drawing Title:

Size | Document Number | Rev
Date: | Sheet | of

Page Title:

Designer:

Drawn by:

Approved:

## System Innovation

High Tech Campus 60
5656 AG Eindhoven, The Netherlands This document contains information proprietary to NXP and shall not be used for engineering design, procurement or manufacture in whole or in part without the express written permission of NXP Semiconductors.
© | Classification:NXP SEMICONDUCTORS
SCH-97011 / PDF: SPF-97011 | A1

# NAVQ95-T1SW

C

Wednesday, September 09, 2026

## Cover

Jari van Ewijk

Costin Onofrei

Jari van Ewijk

1 | 9

Public
Drawing Title:
Size | Document Number | Rev
Date: | Sheet | of

Page Title:

Designer:

Drawn by:

Approved:

## System Innovation

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

# NAVQ95-T1SW

C

Wednesday, September 09, 2026

## Cover

Jari van Ewijk

Costin Onofrei

Jari van Ewijk

1 | 9

Public
Drawing Title:
Size | Document Number | Rev
Date: | Sheet | of

Page Title:

Designer:

Drawn by:

Approved:

## System Innovation

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

# NAVQ95-T1SW

C

Wednesday, September 09, 2026

## Cover

Jari van Ewijk

Costin Onofrei

Jari van Ewijk

1 | 9

Public

# DNP Components

# Switch Default Positions

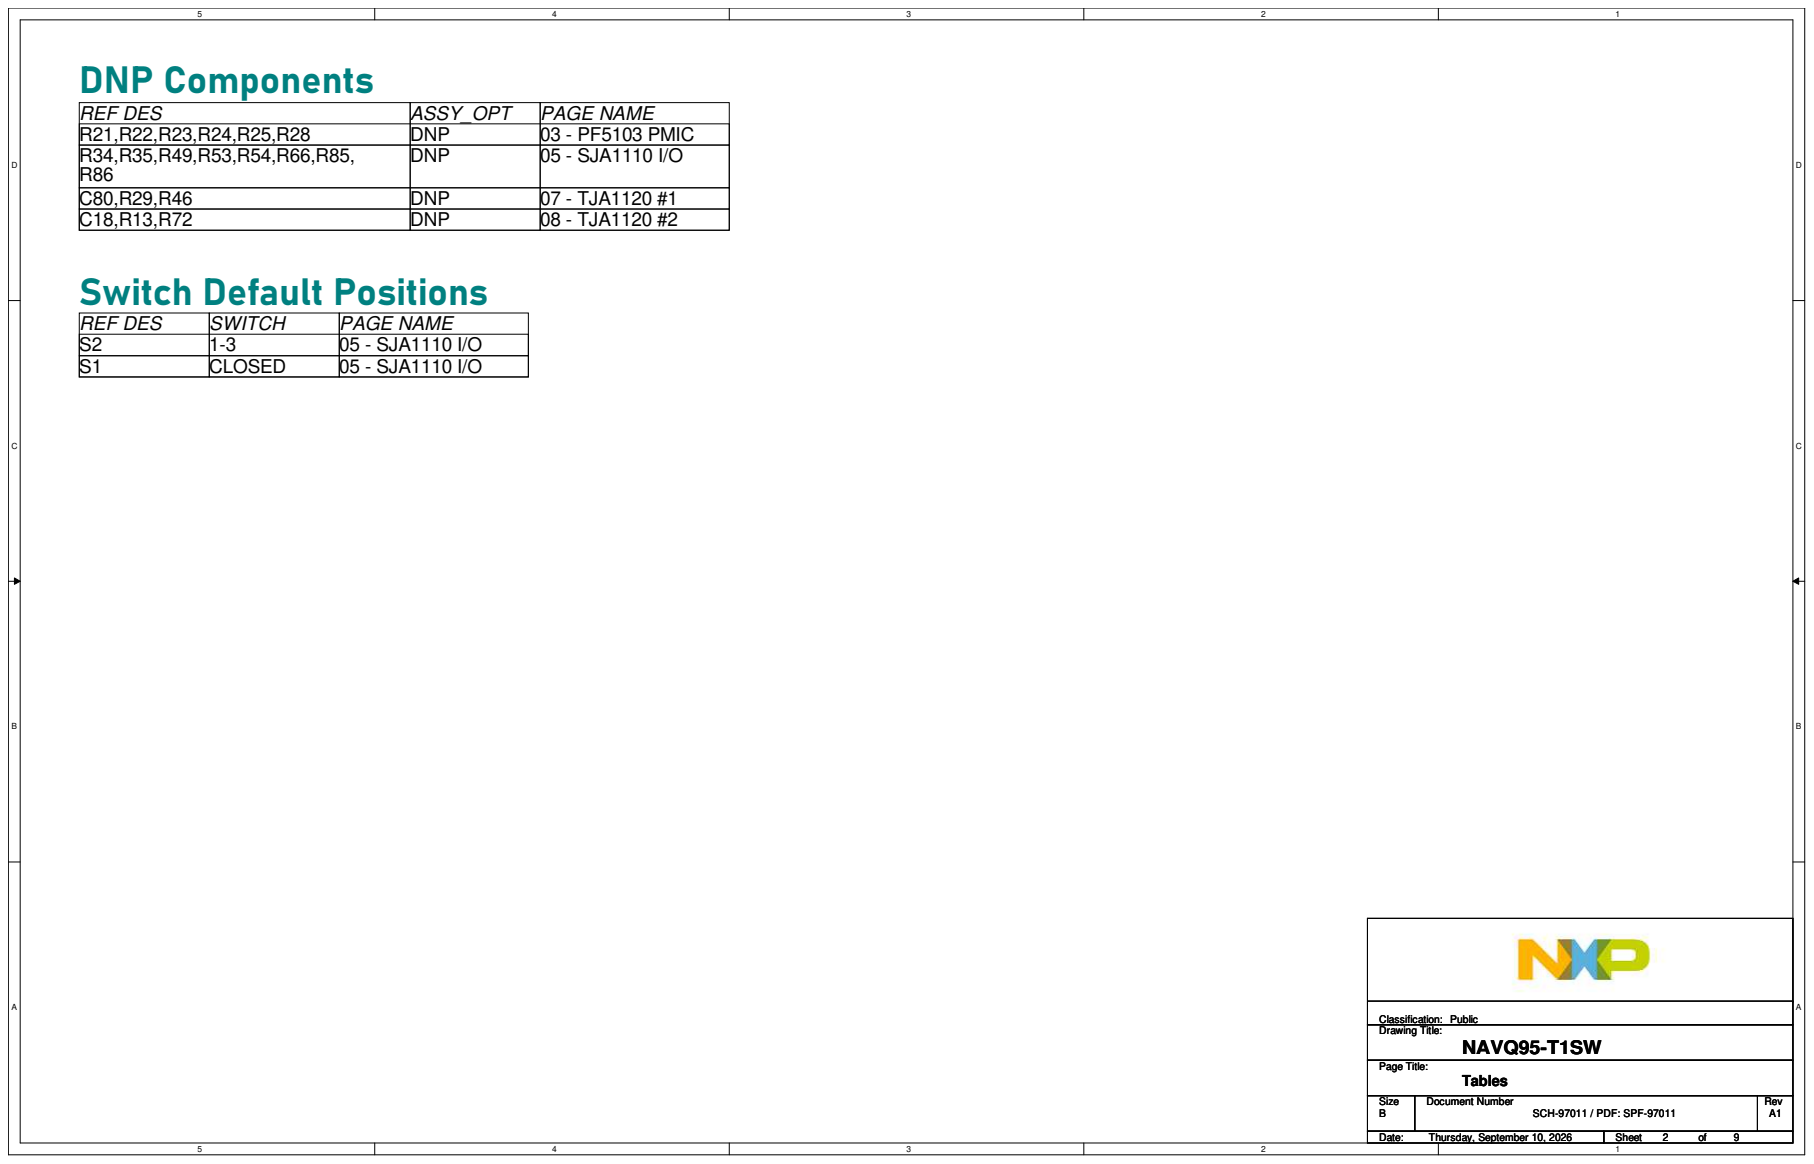
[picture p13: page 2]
REF DES; ASSY_OPT; PAGE NAME; DNP; 03 - PF5103 PMIC; 05 - SJA1110 I/O; 07 - TJA1120 #1; 08 - TJA1120 #2; SWITCH; CLOSED; Drawing Title:; Size; Document Number; Rev; Date:; Sheet; Page Title:; Classification:; SCH-97011 / PDF: SPF-97011; NAVQ95-T1SW; Thursday, September 10, 2026; Tables; Public

# PF5103 PMIC

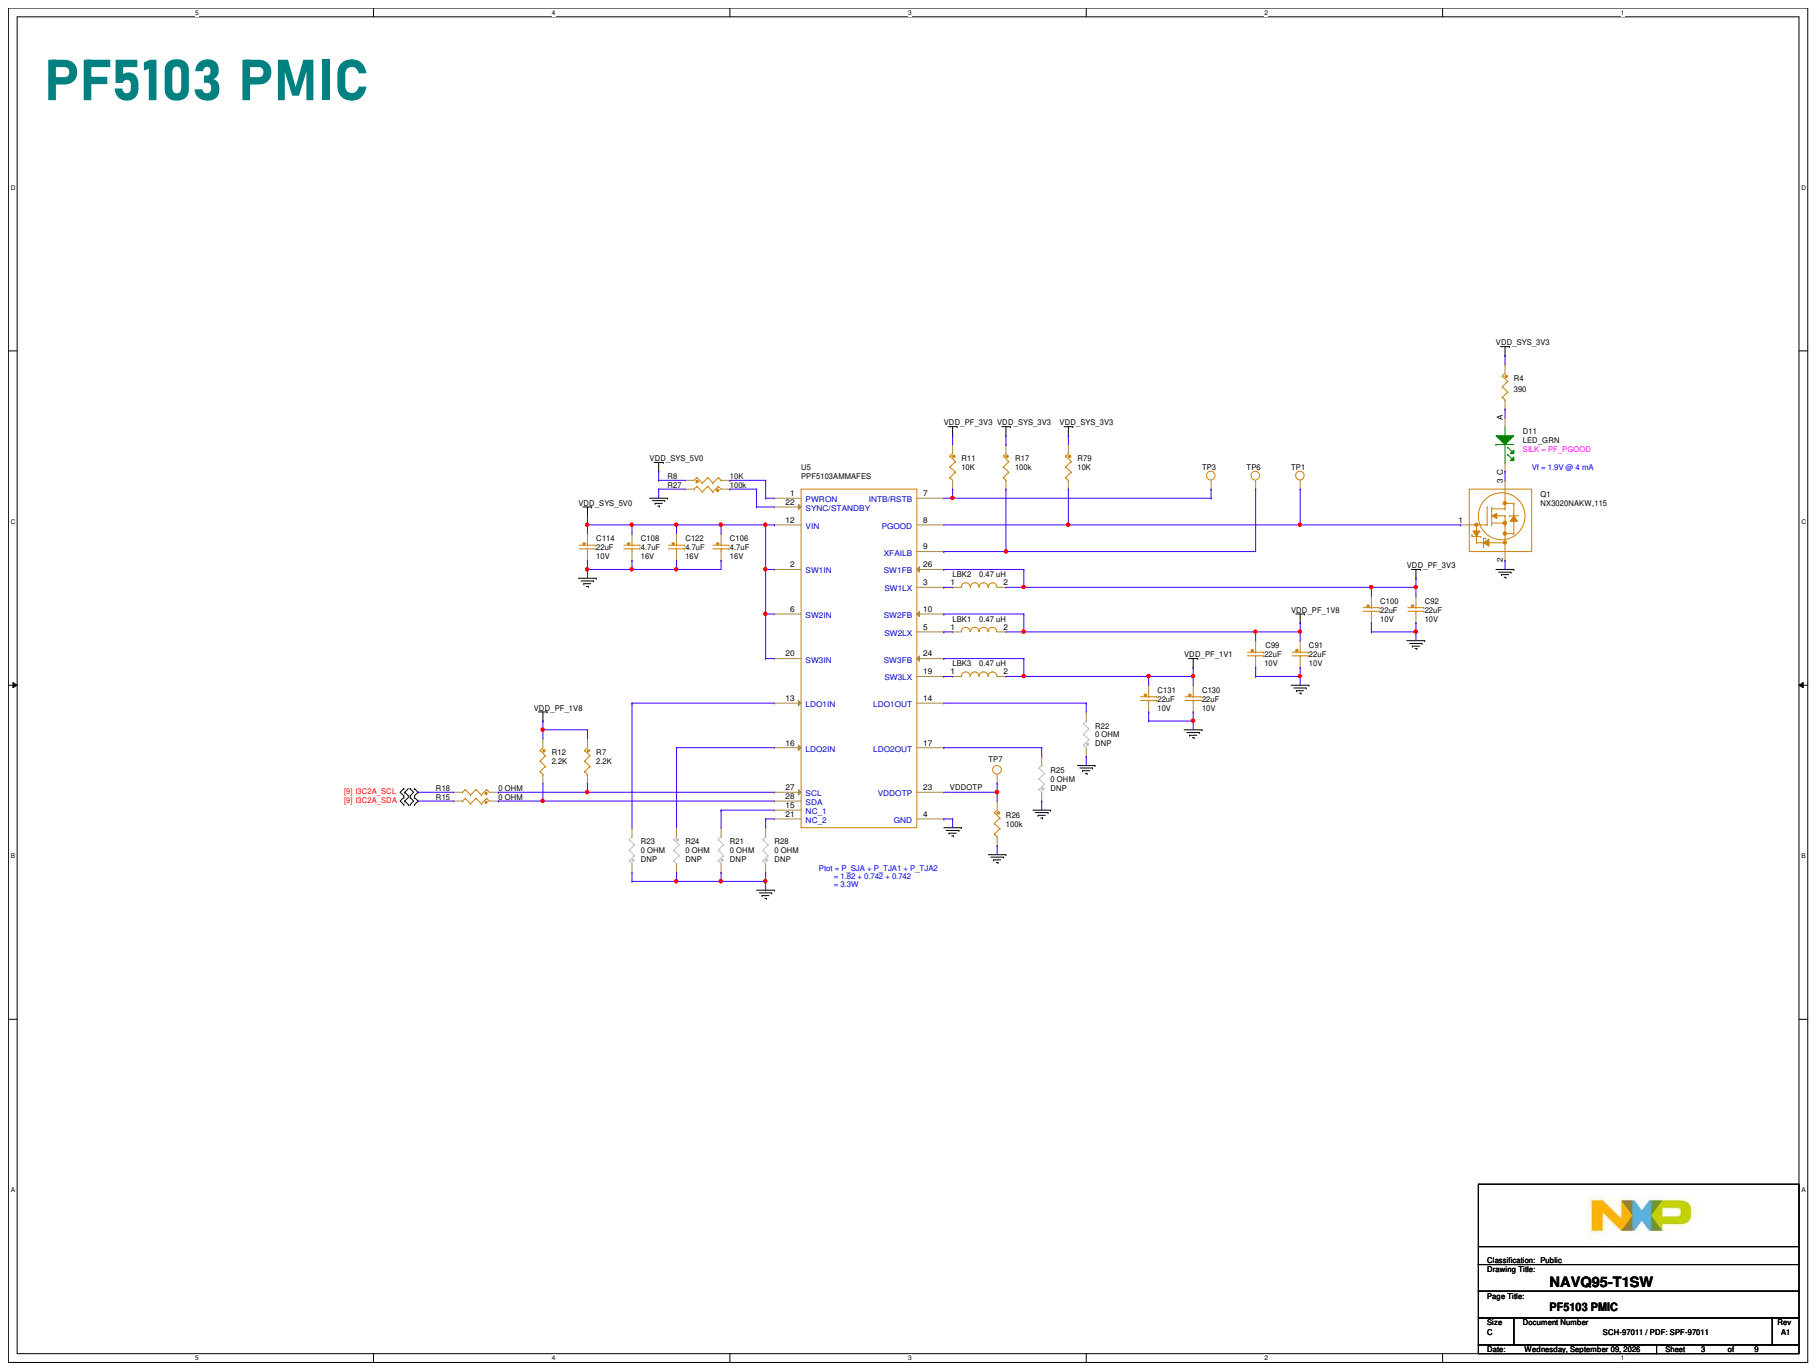
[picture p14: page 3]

# SJA1110 Power

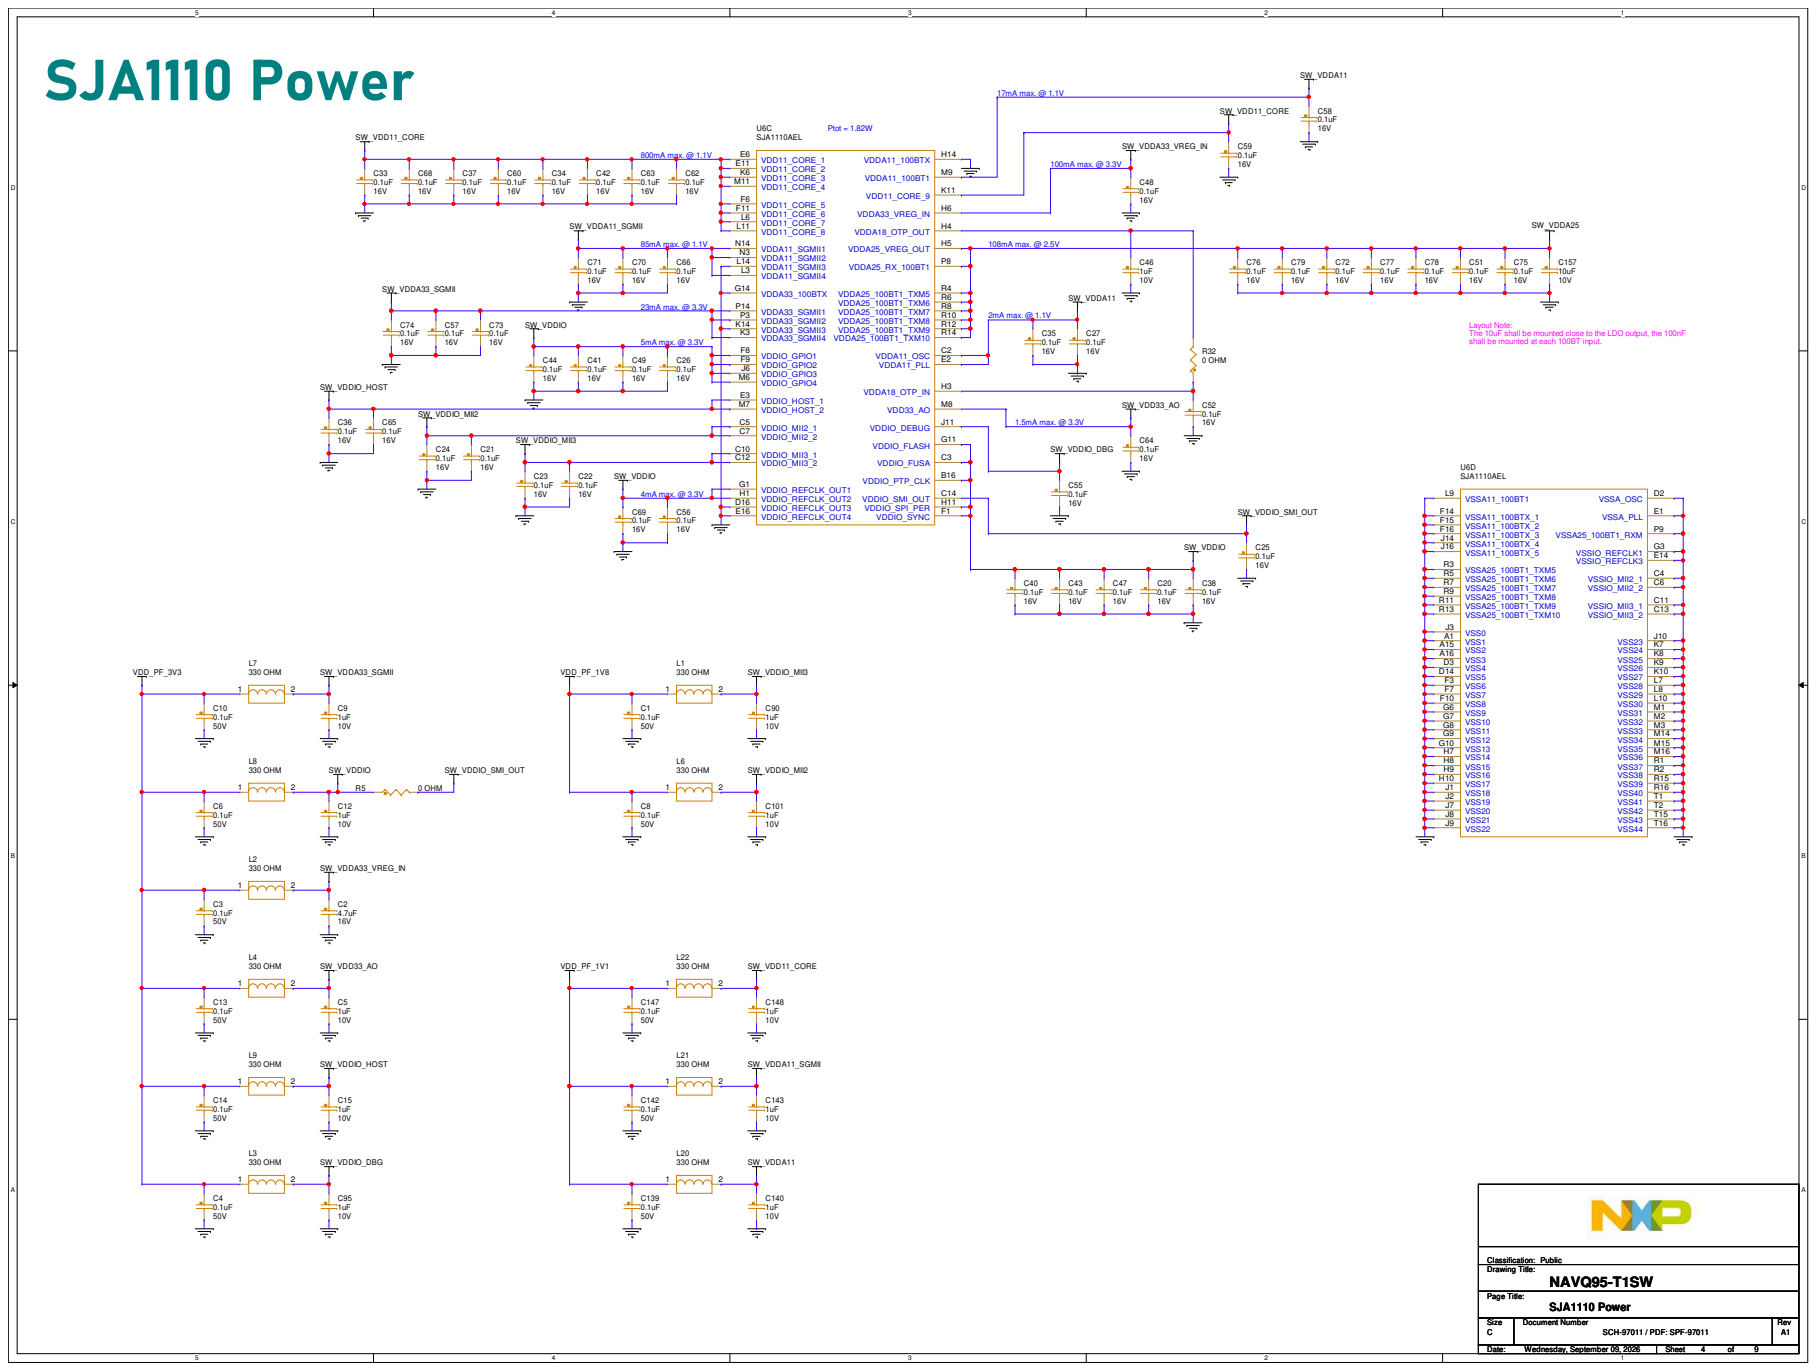
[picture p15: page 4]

Layout Note:
The 10uF shall be mounted close to the LDO output, the 100nF
shall be mounted at each 100BT input.

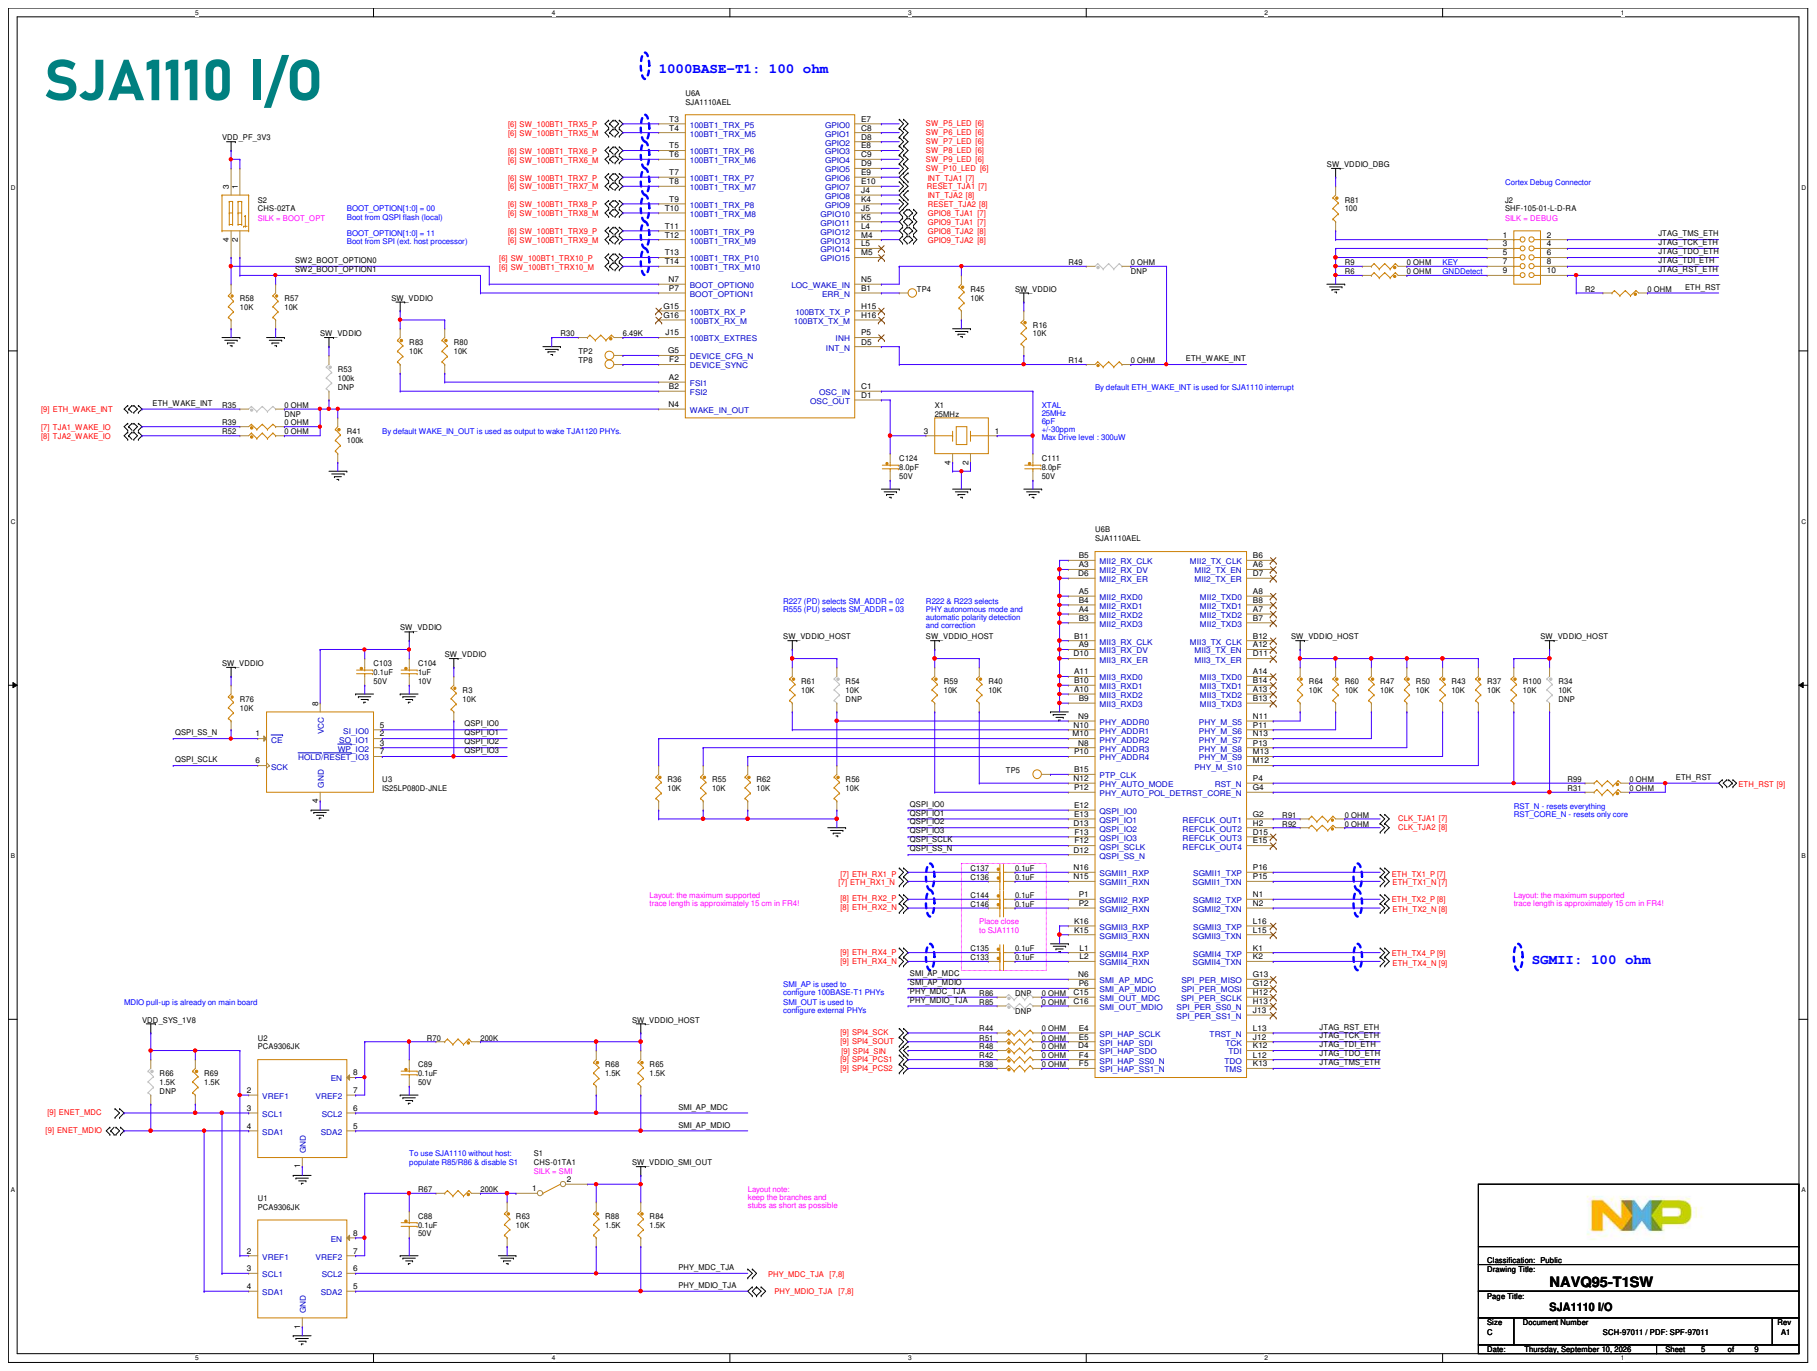
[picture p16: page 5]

BOOT_OPTION[1:0] = 00
Boot from QSPI flash (local)

BOOT_OPTION[1:0] = 11
Boot from SPI (ext. host processor)

By default ETH_WAKE_INT is used for SJA1110 interrupt

By default WAKE_IN_OUT is used as output to wake TJA1120 PHYs.

R222 & R223 selects
PHY autonomous mode and
automatic polarity detection
and correction

Layout: the maximum supported
trace length is approximately 15 cm in FR4!

MDIO pull-up is already on main board

To use SJA1110 without host:
populate R85/R86 & disable S1

Layout note:
keep the branches and
stubs as short as possible

# SJA1110 100BASE-T1 PHYs

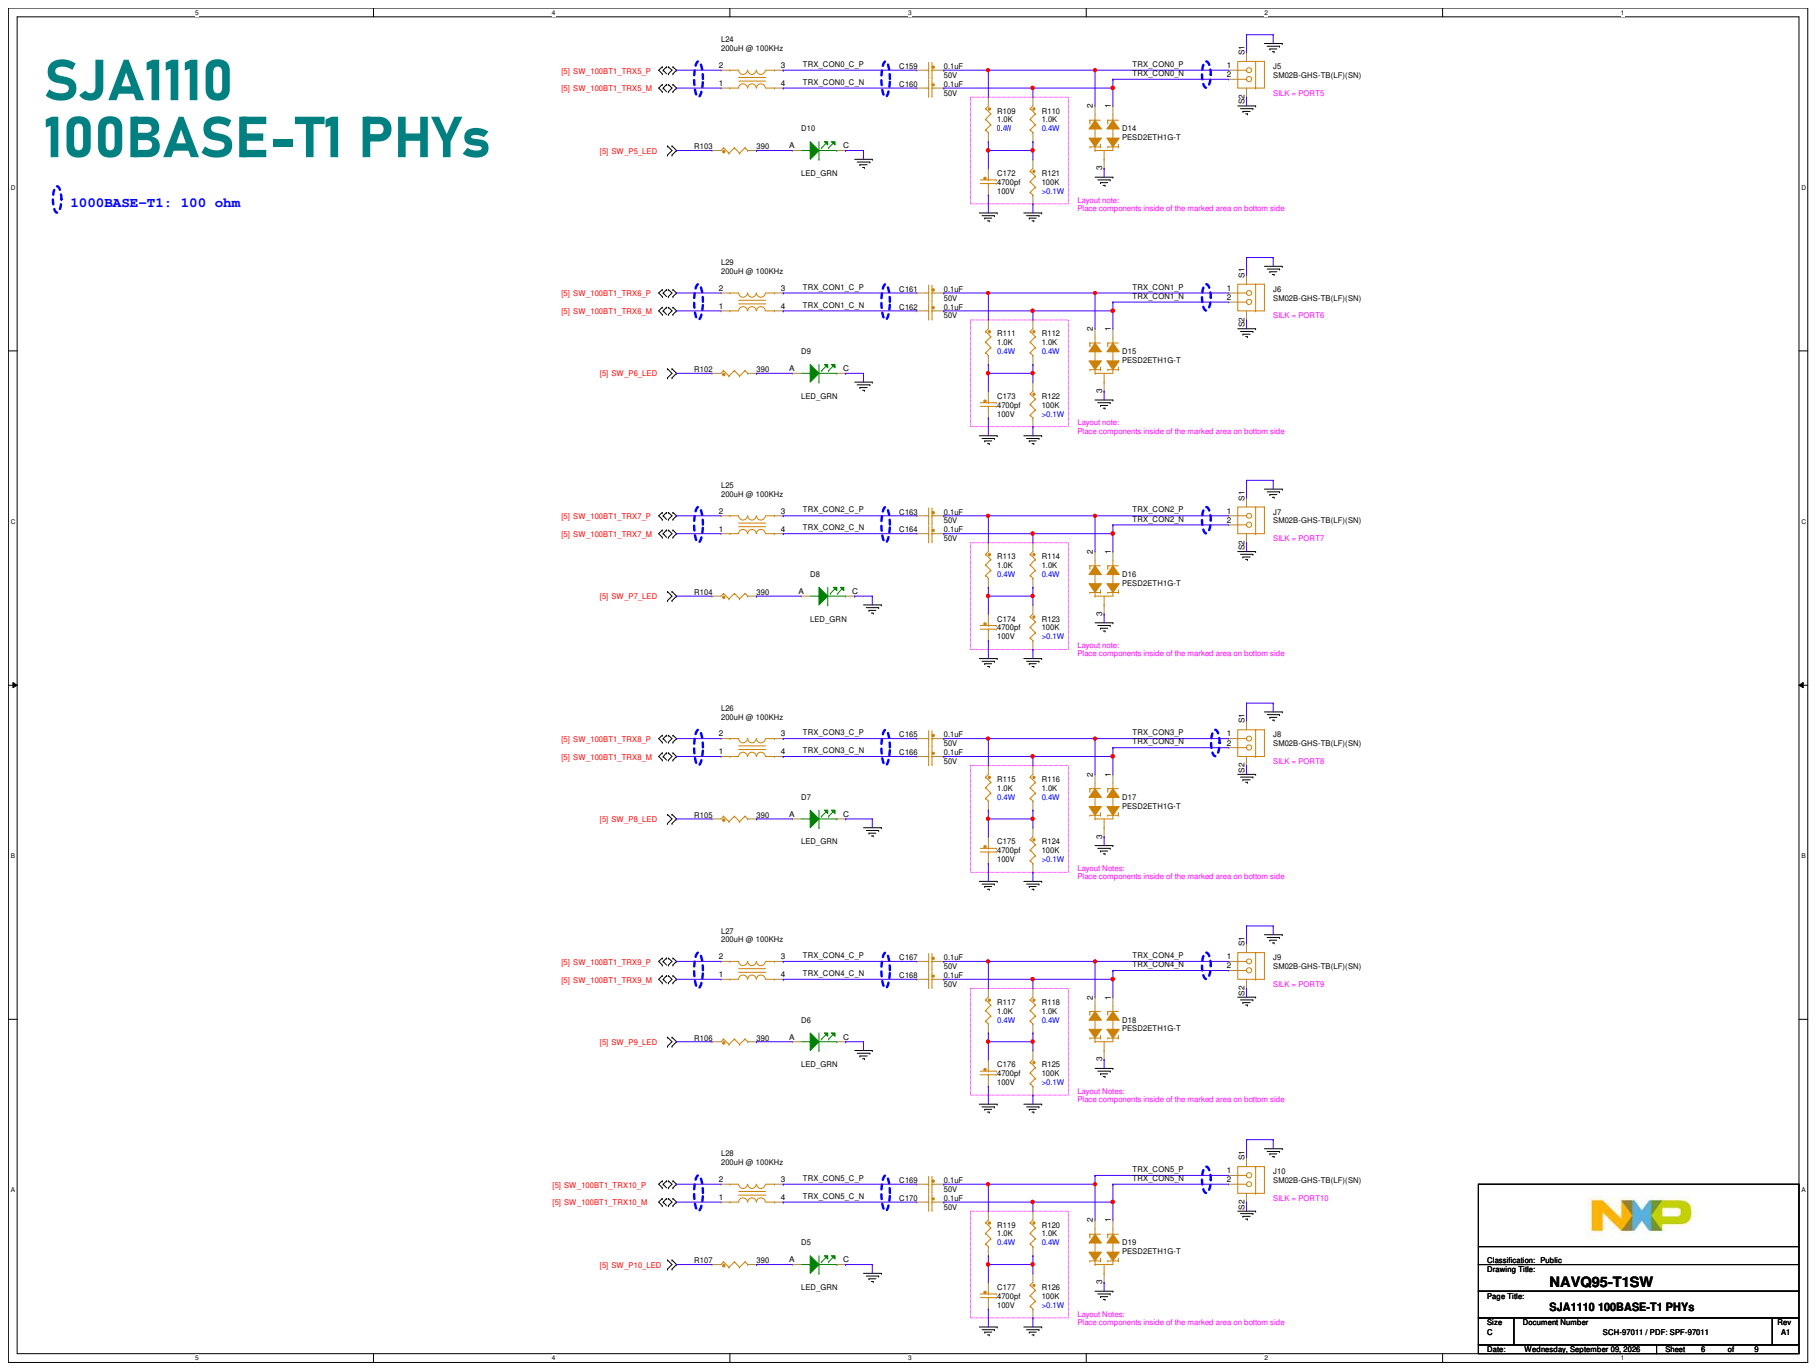
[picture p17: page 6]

SM02B-GHS-TB(LF)(SN)

Layout note:
Place components inside of the marked area on bottom side

Layout Notes:
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

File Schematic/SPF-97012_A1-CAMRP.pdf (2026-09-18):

5

4

3

2

1

D | D
C | C
B | B
A | A
2026-05-29 | Initial schematic developmentX1

# NAVQ95-CAMRP

# 1. Interrupted lines coded with the same letter or

letter combinations are electrically connected.

_P and _N denote a differential signal.

# NOTES:

# 7. All schematic annotations will be in this color

# 6. All SILK display properties will be in this color

# 4. Special signal usage:

2. Device type number is for reference only. The number varies with the manufacturer.

_B denotes an active-low signal.

# 3. Greyed out components indicate

Do Not Populate (DNP) during assembly.

# 5. Interpret diagram in accordance with American National Standards Institute specifications, current

revision, with the exception of logic block symbology.

Rev. | DescriptionDate

# Revision History

By

A | 2026-06-05 | JvE (CTO SI) | Schematic is released

# Table of Contents

# 01 Cover 02 Tables 03 CSI to RPi 22-Pin

# Marketing PN

# X-NAVQ95-CAMRP

# X-NAVQ95-CAMRP

# Part of MR-NAVQ95-KIT (97275 rev. A)

# JvE (CTO SI)

NAVQ95-CAMRP | A1 | 2026-09-09 | JvE (CTO SI) | Schematic is released to production

Drawing Title:

Size | Document Number | Rev
Date: | Sheet | of

Page Title:

Designer:

Drawn by:

Approved:

## System Innovation

High Tech Campus 60
5656 AG Eindhoven, The Netherlands This document contains information proprietary to NXP and shall not be used for engineering design, procurement or manufacture in whole or in part without the express written permission of NXP Semiconductors.
© | Classification:NXP SEMICONDUCTORS
SCH-97012 / PDF: SPF-97012 | A1

# NAVQ95-CAMRP

C

Wednesday, September 09, 2026

## Cover

Jari van Ewijk

Costin Onofrei

Jari van Ewijk

1 | 3

Public
Drawing Title:
Size | Document Number | Rev
Date: | Sheet | of

Page Title:

Designer:

Drawn by:

Approved:

## System Innovation

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

# NAVQ95-CAMRP

C

Wednesday, September 09, 2026

## Cover

Jari van Ewijk

Costin Onofrei

Jari van Ewijk

1 | 3

Public
Drawing Title:
Size | Document Number | Rev
Date: | Sheet | of

Page Title:

Designer:

Drawn by:

Approved:

## System Innovation

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

# NAVQ95-CAMRP

C

Wednesday, September 09, 2026

## Cover

Jari van Ewijk

Costin Onofrei

Jari van Ewijk

1 | 3

Public

# DNP Components

REF DES | ASSY_OPT | PAGE NAME

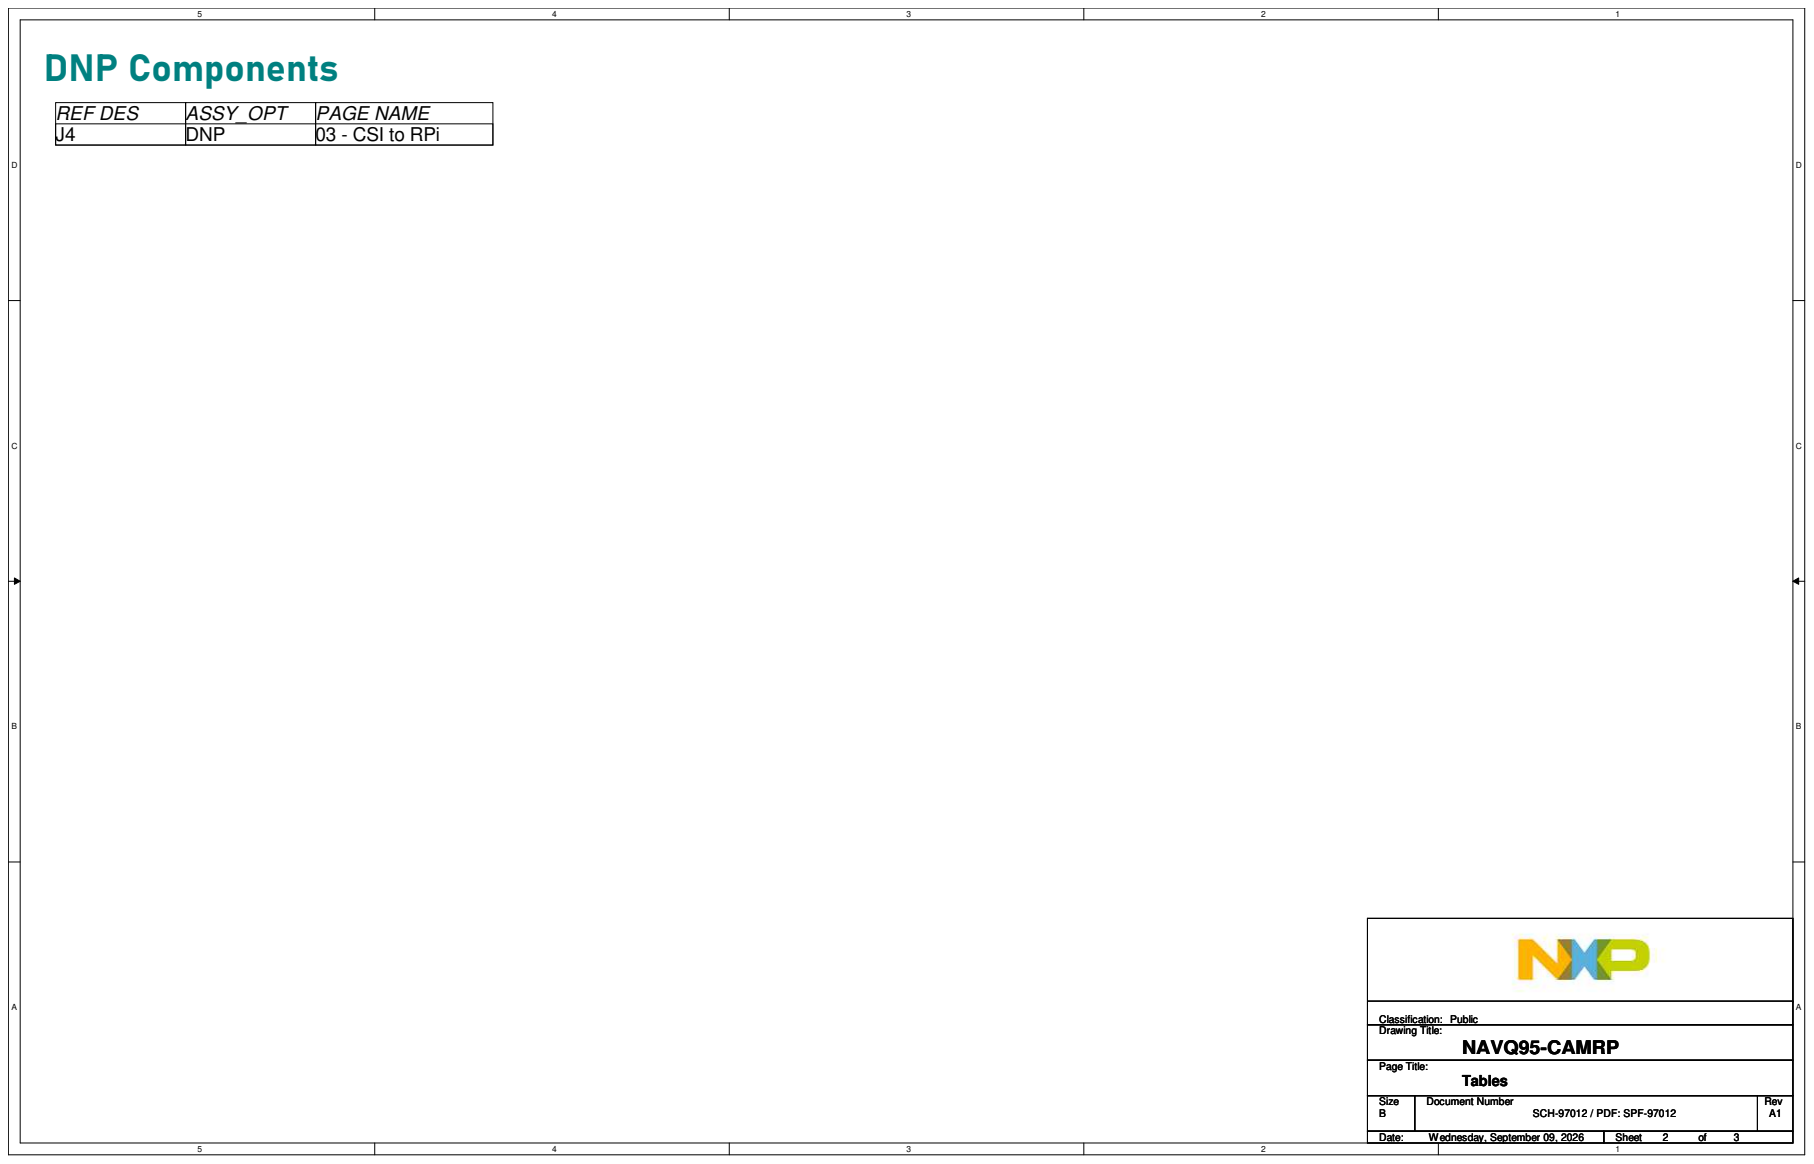
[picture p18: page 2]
DNP; 03 - CSI to RPi; Drawing Title:; Size; Document Number; Rev; Date:; Sheet; Page Title:; Classification:; SCH-97012 / PDF: SPF-97012; NAVQ95-CAMRP; Wednesday, September 09, 2026; Tables; Public

# CSI to RPi 22-Pin

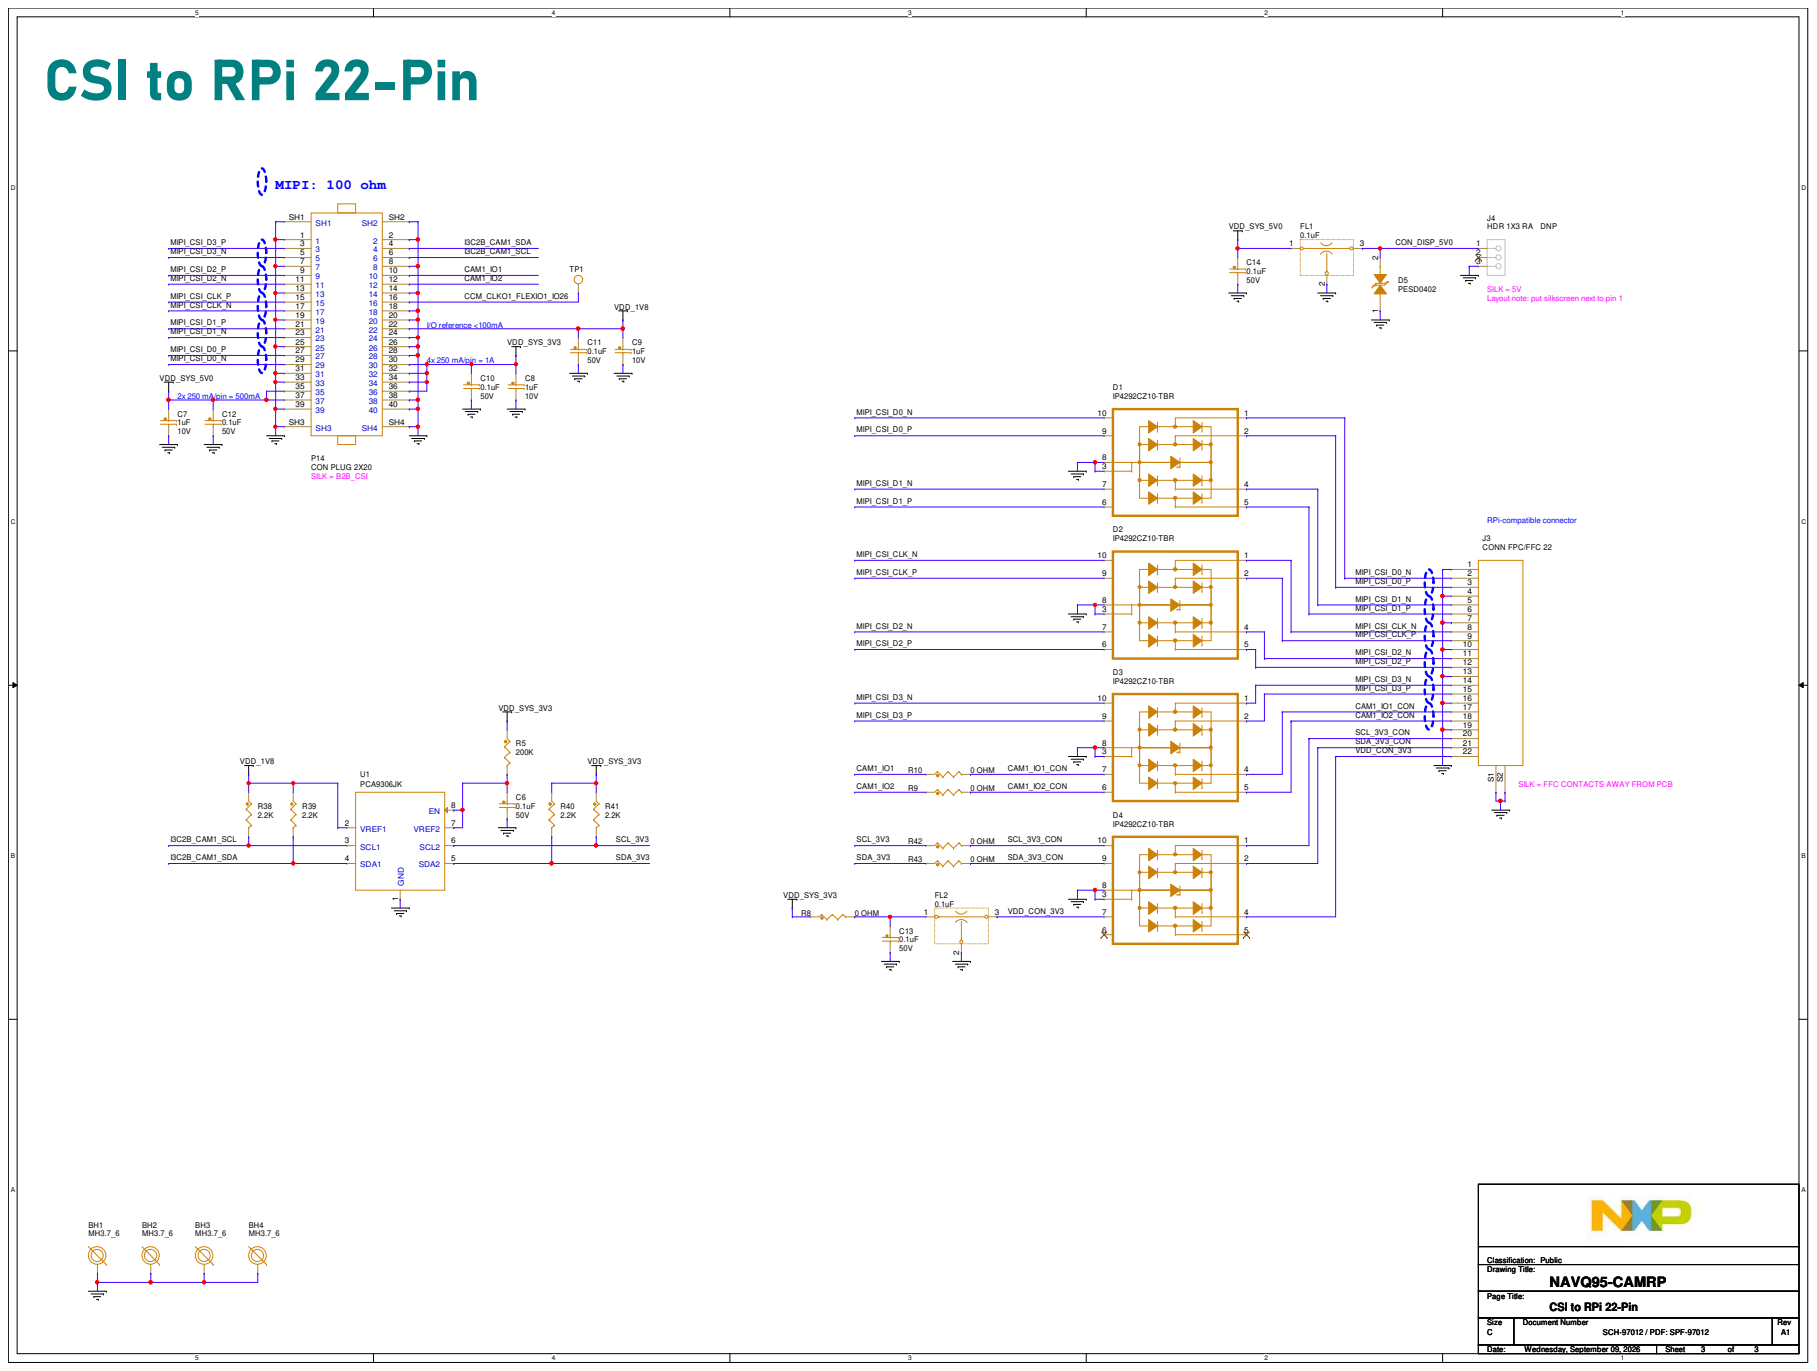
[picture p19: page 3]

SILK = 5V
Layout note: put silkscreen next to pin 1

SILK = FFC CONTACTS AWAY FROM PCB

CSI to RPi 22-Pin

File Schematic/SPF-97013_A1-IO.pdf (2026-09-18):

5

4

3

2

1

D | D
C | C
B | B
A | A

ByRev.

# Revision History

| Date | | Description
X1 | 2026-05-29 | JvE (CTO SI) | Initial schematic development

# NAVQ95-IO

# 1. Interrupted lines coded with the same letter or

letter combinations are electrically connected.

_P and _N denote a differential signal.

# NOTES:

# 7. All schematic annotations will be in this color

# 6. All SILK display properties will be in this color

# 4. Special signal usage:

2. Device type number is for reference only. The number varies with the manufacturer.

_B denotes an active-low signal.

# 3. Greyed out components indicate

Do Not Populate (DNP) during assembly.

# 5. Interpret diagram in accordance with American National Standards Institute specifications, current

revision, with the exception of logic block symbology.

# Table of Contents

# 01 Cover 02 Tables 03 B2B Interface 04 I/O EXP & CAN TRX 05 Sensors & Connectors 06 Audio 07 Console

# Part of MR-NAVQ95-KIT (97275 rev. A)

# Marketing PN

A | JvE (CTO SI)2026-06-17 | Schematic is released

# X-NAVQ95-IO

# X-NAVQ95-IO

NAVQ95-IO | A1 | 2026-10-09 | JvE (CTO SI) | Schematic is released to production

Drawing Title:

Size | Document Number | Rev
Date: | Sheet | of

Page Title:

Designer:

Drawn by:

Approved:

## System Innovation

High Tech Campus 60
5656 AG Eindhoven, The Netherlands This document contains information proprietary to NXP and shall not be used for engineering design, procurement or manufacture in whole or in part without the express written permission of NXP Semiconductors.
© | Classification:NXP SEMICONDUCTORS
SCH-97013 / PDF: SPF-97013 | A1

# NAVQ95-IO

C

Wednesday, September 16, 2026

## Cover

Jari van Ewijk

Costin Onofrei

Jari van Ewijk

1 | 7

Public
Drawing Title:
Size | Document Number | Rev
Date: | Sheet | of

Page Title:

Designer:

Drawn by:

Approved:

## System Innovation

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

# NAVQ95-IO

C

Wednesday, September 16, 2026

## Cover

Jari van Ewijk

Costin Onofrei

Jari van Ewijk

1 | 7

Public
Drawing Title:
Size | Document Number | Rev
Date: | Sheet | of

Page Title:

Designer:

Drawn by:

Approved:

## System Innovation

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

# NAVQ95-IO

C

Wednesday, September 16, 2026

## Cover

Jari van Ewijk

Costin Onofrei

Jari van Ewijk

1 | 7

Public

# Switch Default Positions

# DNP Components

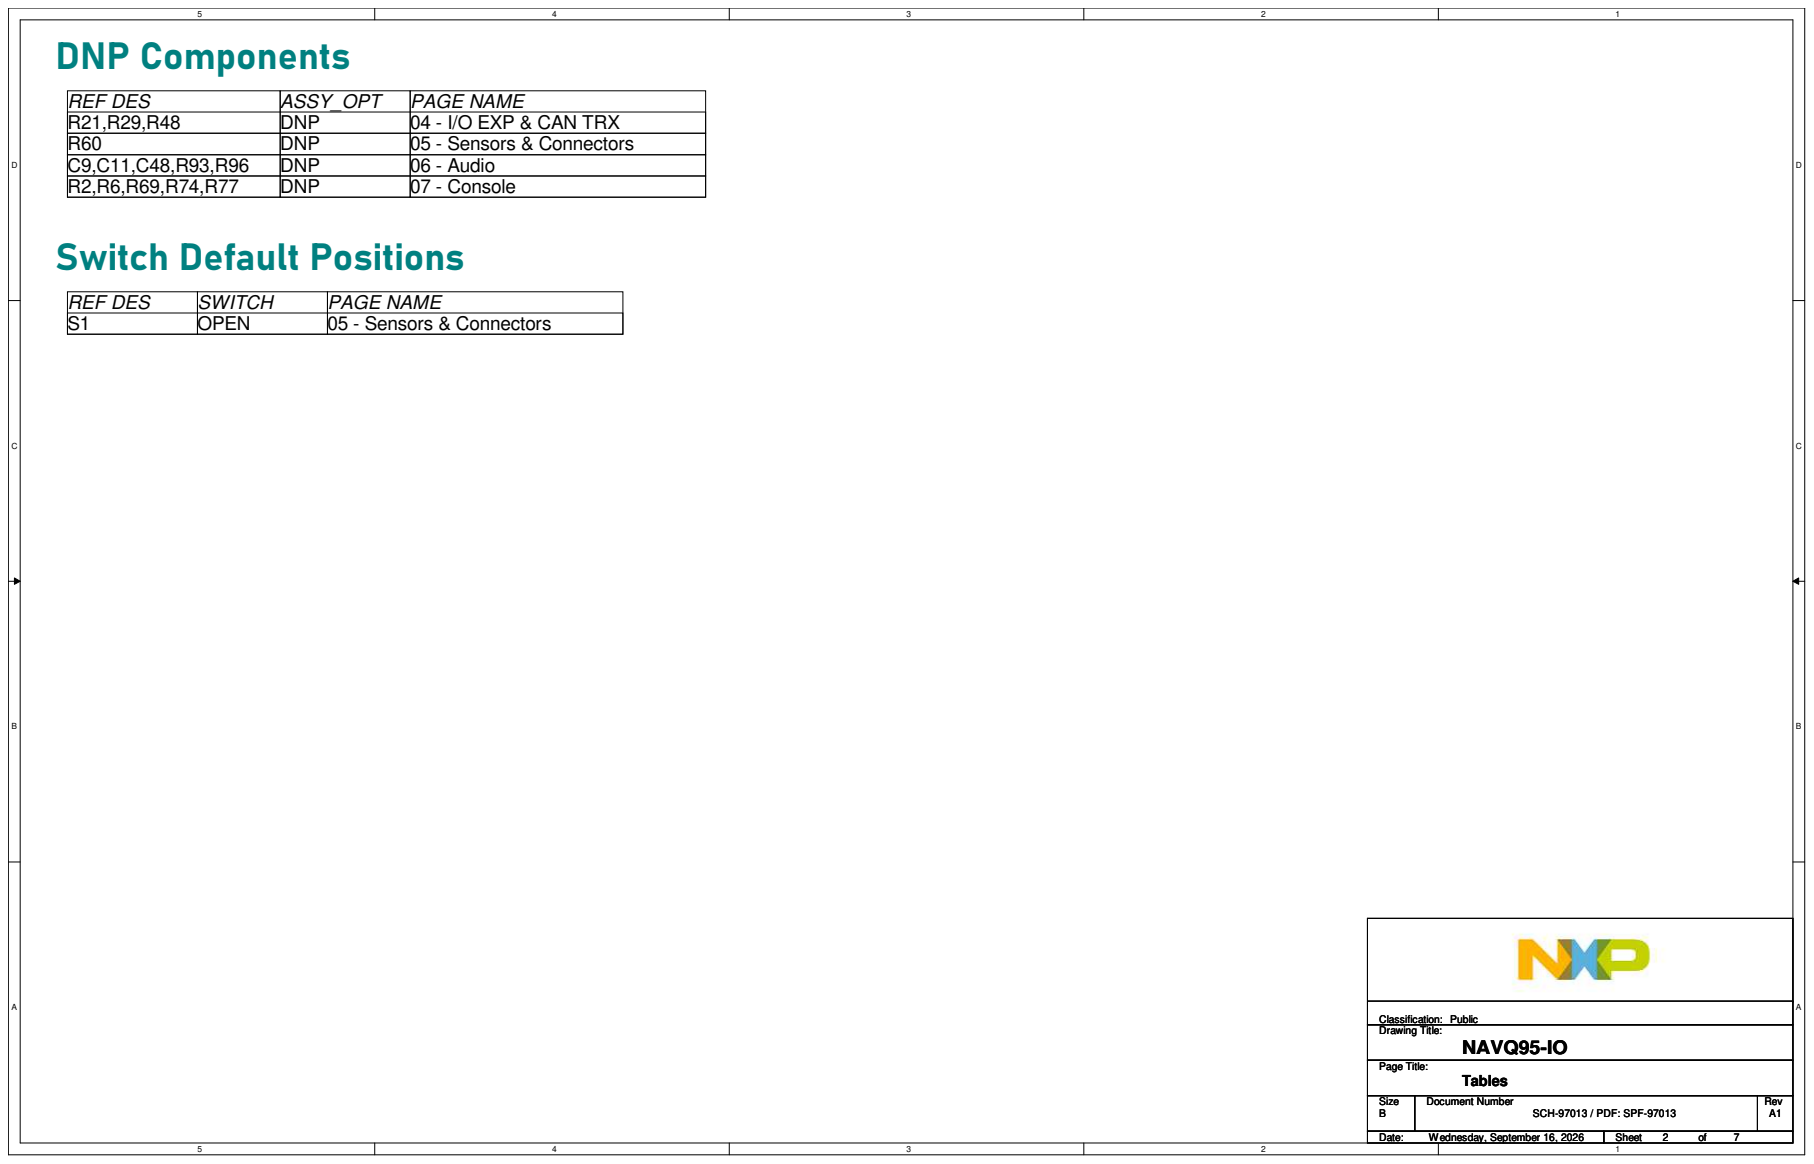
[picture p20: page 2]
REF DES; ASSY_OPT; PAGE NAME; DNP; 04 - I/O EXP & CAN TRX; 05 - Sensors & Connectors; 06 - Audio; 07 - Console; SWITCH; OPEN; Drawing Title:; Size; Document Number; Rev; Date:; Sheet; Page Title:; Classification:; SCH-97013 / PDF: SPF-97013; NAVQ95-IO; Wednesday, September 16, 2026; Tables; Public

# B2B Interface

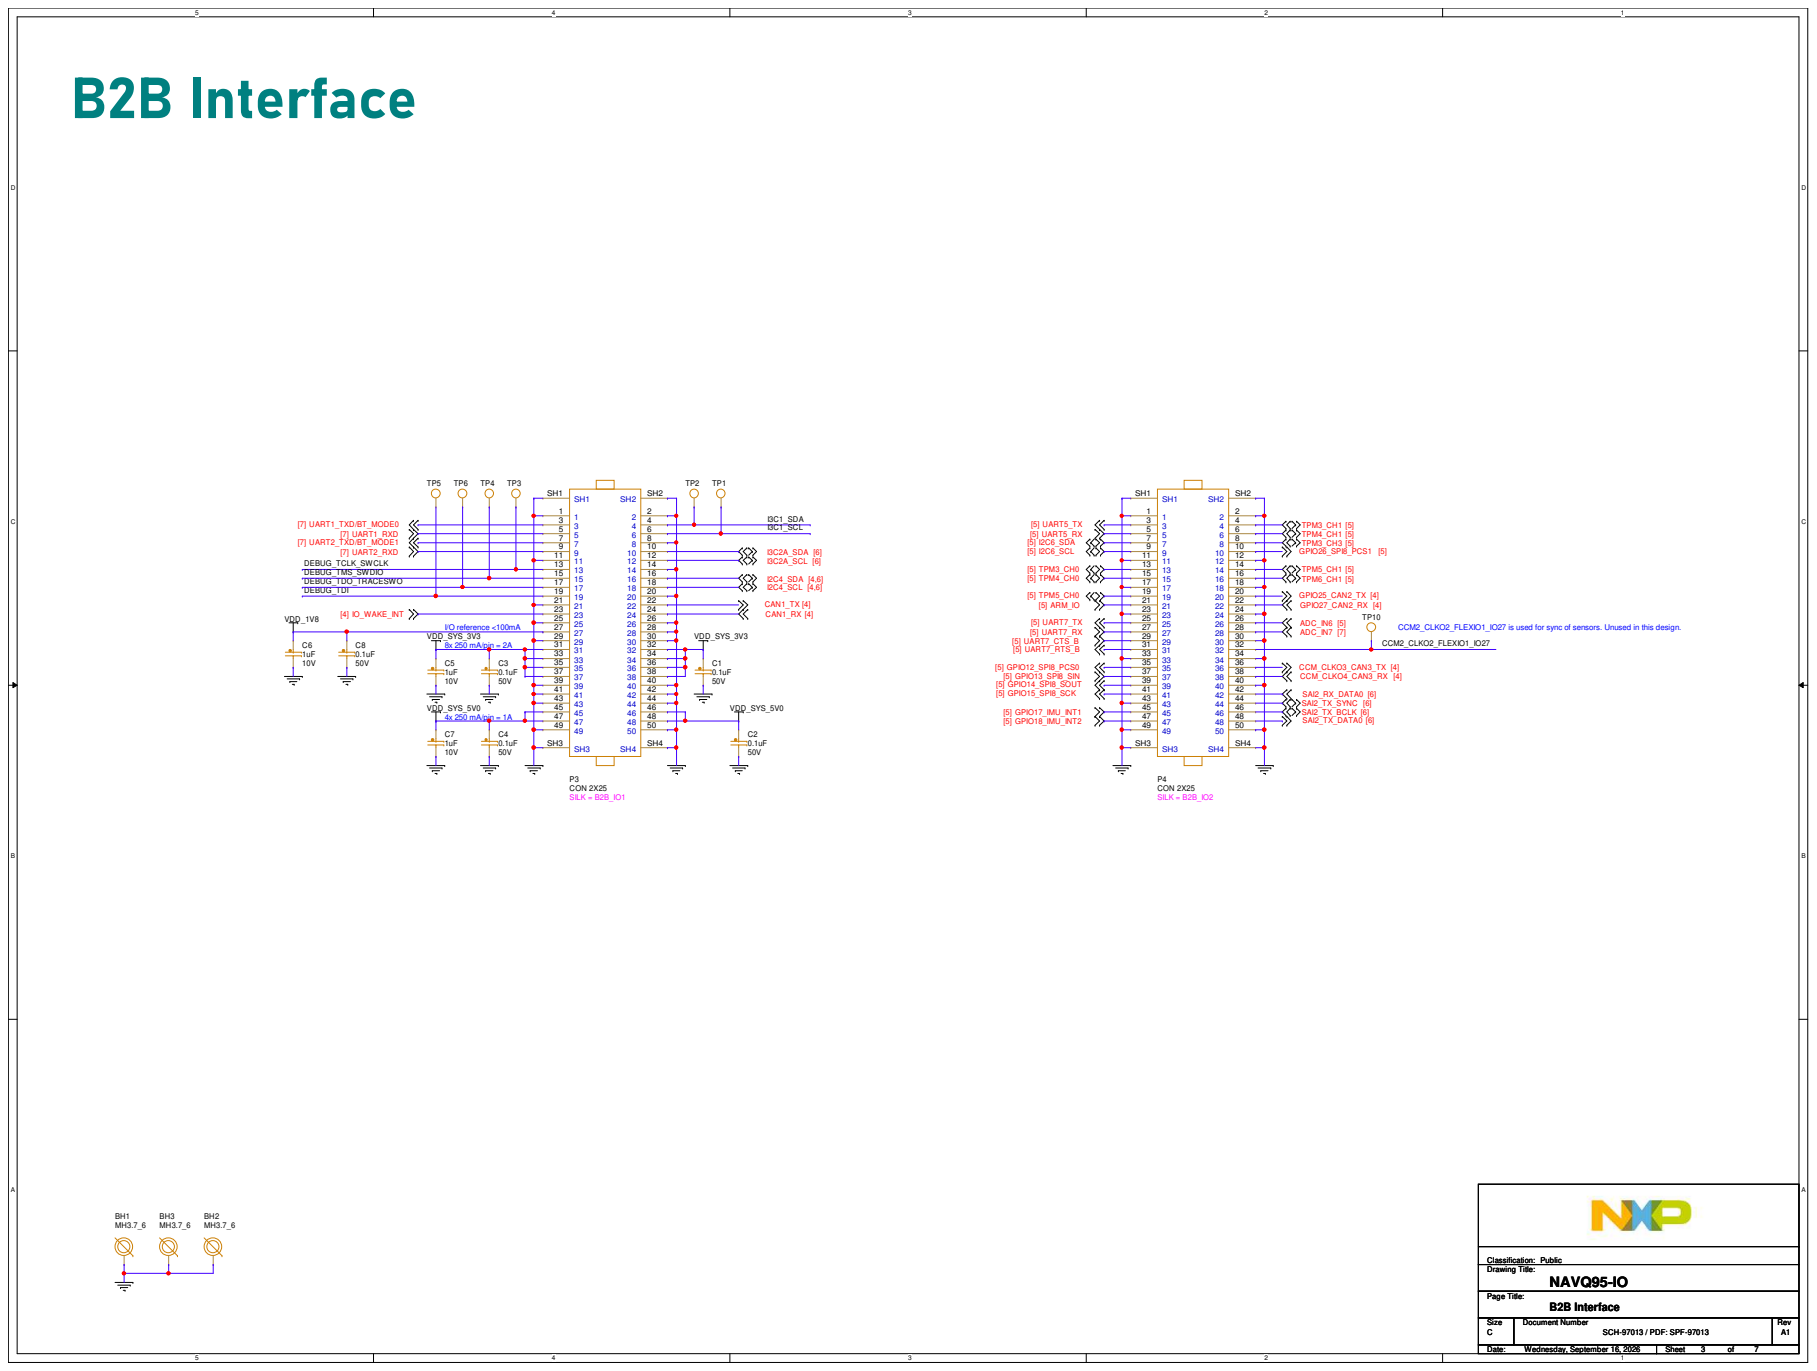
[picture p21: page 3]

# I/O EXP & CAN TRX

# I/O Expander

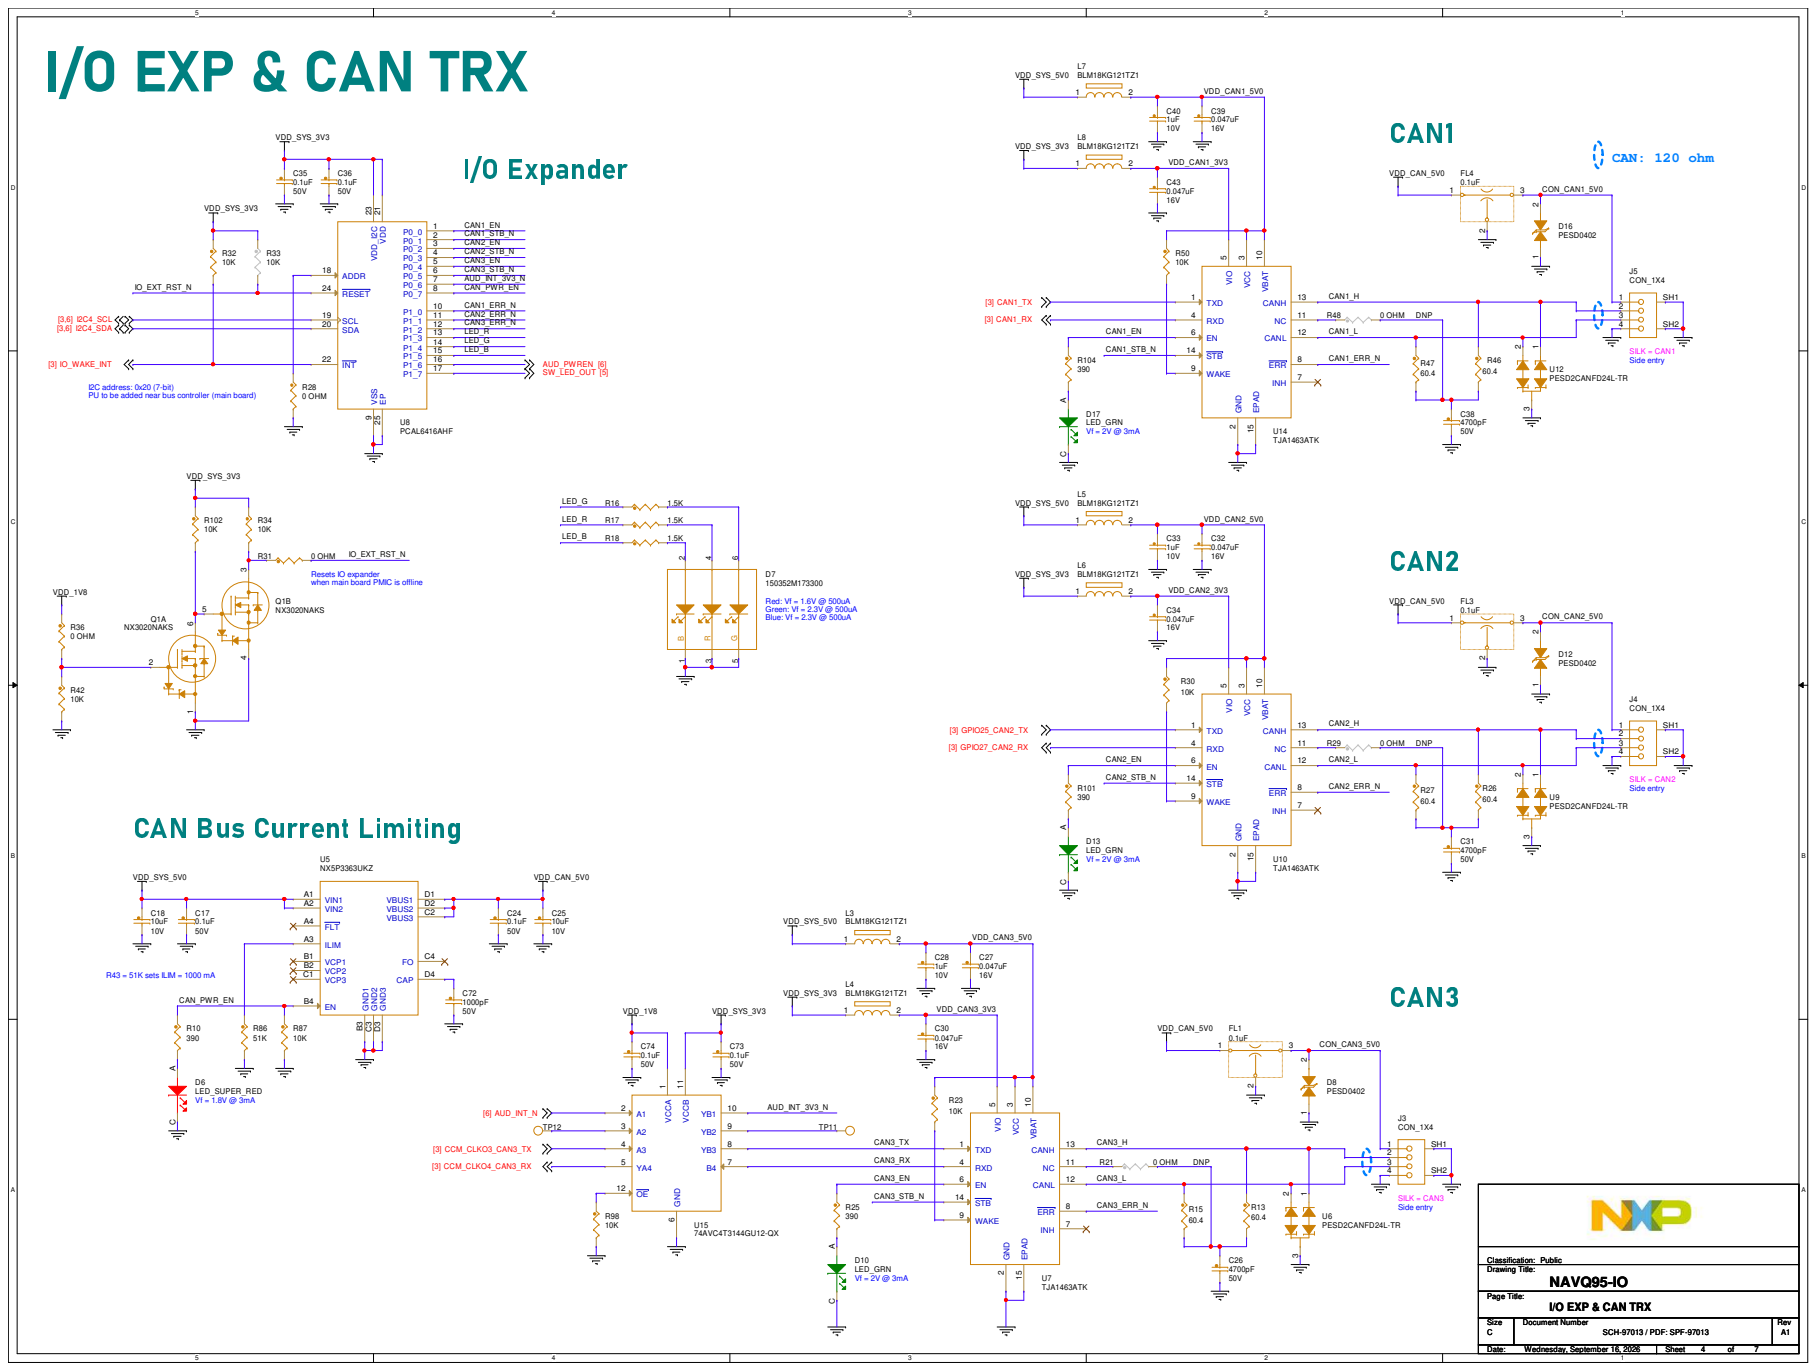
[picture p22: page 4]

I2C address: 0x20 (7-bit)
PU to be added near bus controller (main board)

Resets IO expander
when main board PMIC is offline

CAN Bus Current Limiting

# Sensors & Connectors

# IMU

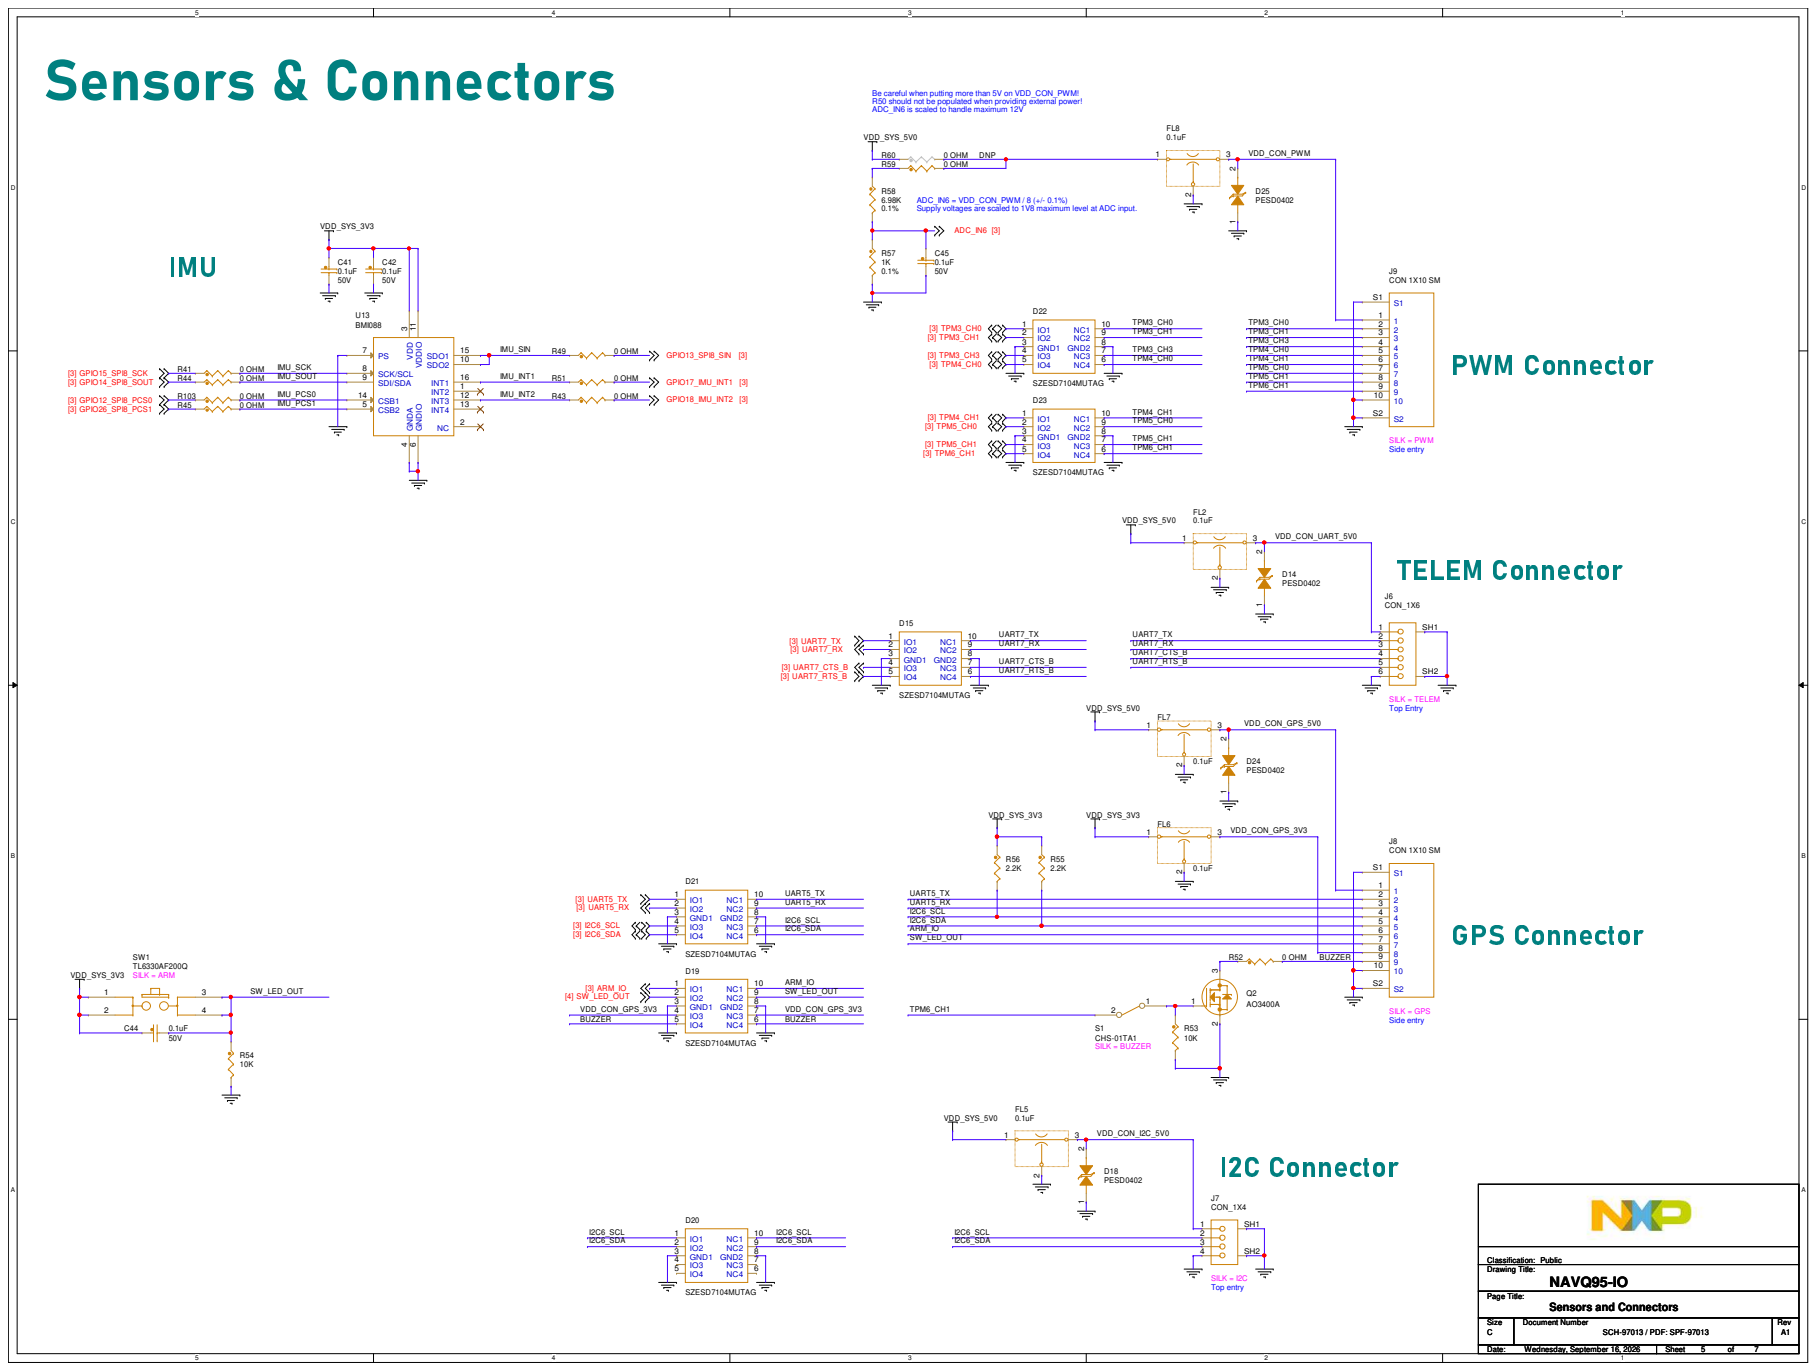
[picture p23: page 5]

Be careful when putting more than 5V on VDD_CON_PWM!
R50 should not be populated when providing external power!
ADC_IN6 is scaled to handle maximum 12V

ADC_IN6 = VDD_CON_PWM / 8 (+/- 0.1%)
Supply voltages are scaled to 1V8 maximum level at ADC input.

# Audio

# Audio Codec

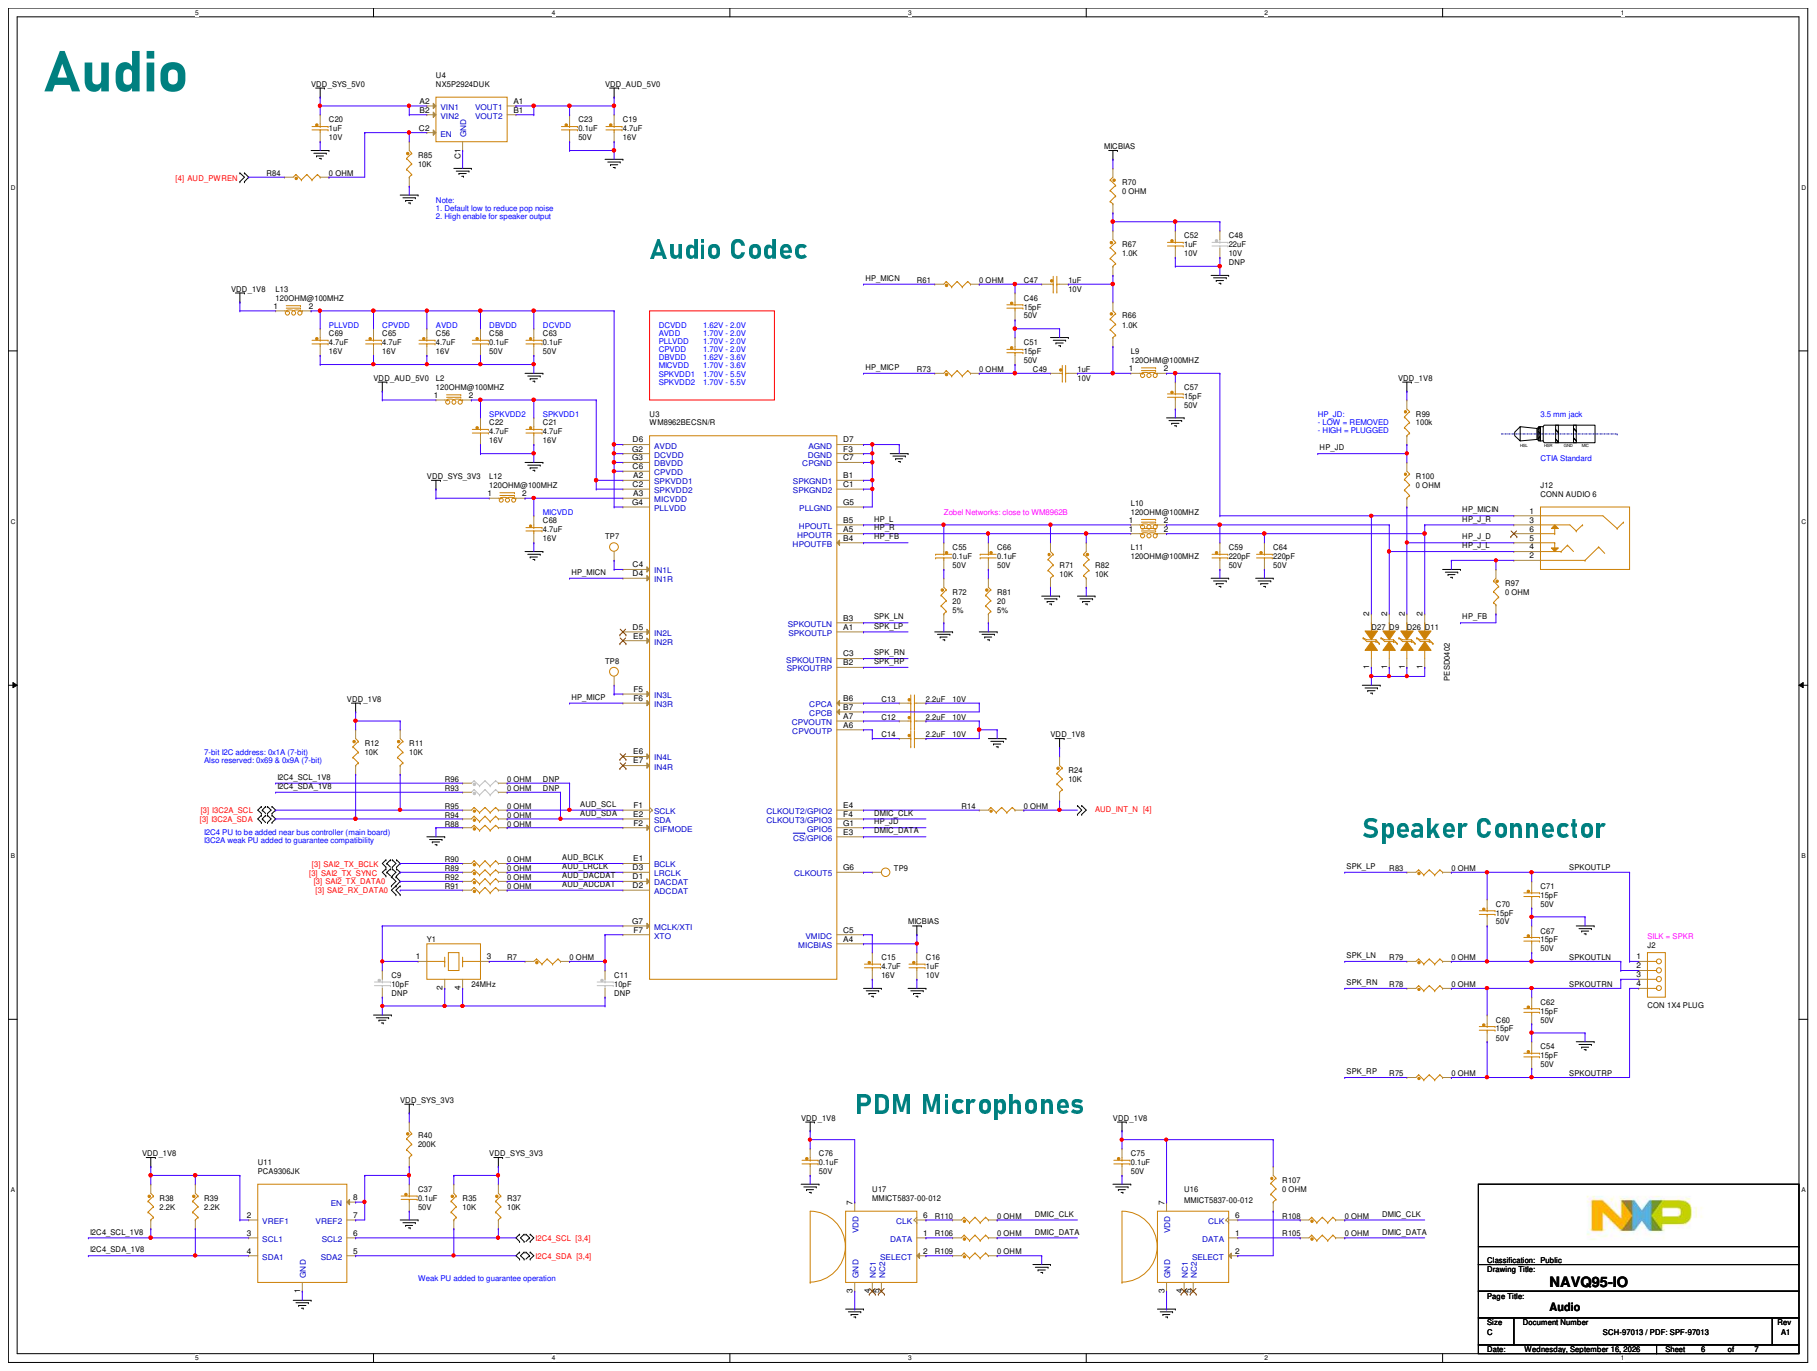
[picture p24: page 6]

Note:
1. Default low to reduce pop noise
2. High enable for speaker output

Zobel Networks: close to WM8962B

I3C2A_SCL[3]
I3C2A_SDA[3]
I2C4 PU to be added near bus controller (main board)
I3C2A weak PU added to guarantee compatibility

Weak PU added to guarantee operation

# Console


Remove R117 and populate R118+R119
to use VDD_SYS_3V3 to supply U24, instead of VBUS

ADC_IN7 = VDD_USB_3V3 / 2 (+/- 0.1%)
Supply voltages are scaled to 1V8 maximum level at ADC input.

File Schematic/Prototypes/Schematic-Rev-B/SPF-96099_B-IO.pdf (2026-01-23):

5

4

3

2

1

D | D
C | C
B | B
A | A

# 1. Interrupted lines coded with the same letter or

letter combinations are electrically connected.

25-09-11 | Initial schematic development and format changes.20

# X-MR-NAVQ95E-IO

# 5. Interpret diagram in accordance with American National Standards Institute specifications, current

revision, with the exception of logic block symbology.

By

_B denotes an active-low signal.

Rev.

# 4. Special signal usage:

_P and _N denote a differential signal.

# 7. All schematic annotations will be in this color

# Revision History

# YT (CTO SI)X0-X9

# Date

# 3. Greyed out components indicate

Do Not Populate (DNP) during assembly.

# Description

2. Device type number is for reference only. The number varies with the manufacturer.

# NOTES:

# 6. All SILK display properties will be in this color

A | 2025-09-26 | YT (CTO SI) | Schematic is released.
BX1-BX5 | 2026-01-13 | JvE (CTO SI) | Schematic revision, see last page for changelog

# Table of Contents

# 01 Cover 02 Tables 03 B2B Interface 04 I/O EXP & CAN TRX 05 Sensors & Connectors 06 Audio 07 Console 08 Changelog

2026-01-19 | JvE (CTO SI) | Schematic is releasedB

Drawing Title:

Size | Document Number | Rev
Date: | Sheet | of

Page Title:

Designer:

Drawn by:

Approved:

## System Innovation

High Tech Campus 60
5656 AG Eindhoven, The Netherlands This document contains information proprietary to NXP and shall not be used for engineering design, procurement or manufacture in whole or in part without the express written permission of NXP Semiconductors.
© | Classification:NXP SEMICONDUCTORS
SCH-96099 PDF: SPF-96099 | B

# X-MR-NAVQ95E-IO

C

Monday, January 19, 2026

## Cover

Jari van Ewijk

Youri Tils

Jari van Ewijk

1 | 8

Company Internal
Drawing Title:
Size | Document Number | Rev
Date: | Sheet | of

Page Title:

Designer:

Drawn by:

Approved:

## System Innovation

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

# X-MR-NAVQ95E-IO

C

Monday, January 19, 2026

## Cover

Jari van Ewijk

Youri Tils

Jari van Ewijk

1 | 8

Company Internal
Drawing Title:
Size | Document Number | Rev
Date: | Sheet | of

Page Title:

Designer:

Drawn by:

Approved:

## System Innovation

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

# X-MR-NAVQ95E-IO

C

Monday, January 19, 2026

## Cover

Jari van Ewijk

Youri Tils

Jari van Ewijk

1 | 8

Company Internal

# DNP Table

# Switch Table

REF DES; DNP DNP DNP; DNP; ASSY_OPT; 05 - Sensors & Connectors; REF DES OPENS1; PAGE NAMESWITCH; Drawing Title:; Size; Document Number; Rev; Date:; Sheet; Page Title:; Classification:; SCH-96099 PDF: SPF-96099; X-MR-NAVQ95E-IO; Tuesday, January 20, 2026; Tables; Company Internal

PAGE NAME
04 - I/O EXP & CAN TRX
05 - Sensors & Connectors
06 - Audio
07 - Console

# B2B Interface


CCM2_CLKO2_FLEXIO1_IO27 is used for sync of sensors. Unused in this design.
CCM_CLKO2_FLEXIO1_IO27

# I/O EXP & CAN TRX

# I/O Expander


I2C address: 0x20 (7-bit)
PU to be added near bus controller (main board)

Resets IO expander
when main board PMIC is offline

CAN Bus Current Limiting

# Sensors & Connectors

# IMU


Be careful when putting more than 5V on VDD_CON_PWM!
R50 should not be populated when providing external power!
ADC_IN6 is scaled to handle maximum 12V

ADC_IN6 = VDD_CON_PWM / 8 (+/- 0.1%)
Supply voltages are scaled to 1V8 maximum level at ADC input.

# Audio

# Audio Codec


Note:
1. Default low to reduce pop noise
2. High enable for speaker output

Zobel Networks: close to WM8962B

I3C2A_SCL[3]
I3C2A_SDA[3]
I2C4 PU to be added near bus controller (main board)
I3C2A weak PU added to guarantee compatibility
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

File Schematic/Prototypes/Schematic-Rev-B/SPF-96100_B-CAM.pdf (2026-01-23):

5

4

3

2

1

D | D
C | C
B | B
A | A

# Revision History

# 4. Special signal usage:

By

2025-09-12

# 1. Interrupted lines coded with the same letter or

letter combinations are electrically connected.

# NOTES:

# 3. Greyed out components indicate

Do Not Populate (DNP) during assembly.

# YT (CTO SI)

_P and _N denote a differential signal.

_B denotes an active-low signal.

# X-MR-NAVQ95E-CAM

# 6. All SILK display properties will be in this color

# Description

X0-X6

# 7. All schematic annotations will be in this color

Rev.

# 5. Interpret diagram in accordance with American National Standards Institute specifications, current

revision, with the exception of logic block symbology.

# Initial schematic development and format changes

2. Device type number is for reference only. The number varies with the manufacturer.

# Date

# Table of Contents

# P01 Cover P02 Notes

P03 CSI to RPi | 2025-09-25 | YT (CTO SI)A | Schematic is released

# ChangelogP04

2026-01-15 | Schematic is releasedYT (CTO SI)B
BX1-4 | YT (CTO SI)2025-12-19 | Schematic revision

Drawing Title:

Size | Document Number | Rev
Date: | Sheet | of

Page Title:

Designer:

Drawn by:

Approved:

## System Innovation

High Tech Campus 60
5656 AG Eindhoven, The Netherlands This document contains information proprietary to NXP and shall not be used for engineering design, procurement or manufacture in whole or in part without the express written permission of NXP Semiconductors.
© | Classification:NXP SEMICONDUCTORS
SCH-96100 PDF: SPF-96100 | B

# X-MR-NAVQ95E-CAM

C

Thursday, January 15, 2026

## Cover

Youri Tils

Jari van Ewijk

Youri Tils

1 | 4

Company Internal/Proprietary Drawing Title:

Size | Document Number | Rev
Date: | Sheet | of

Page Title:

Designer:

Drawn by:

Approved:

## System Innovation

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

# X-MR-NAVQ95E-CAM

C

Thursday, January 15, 2026

## Cover

Youri Tils

Jari van Ewijk

Youri Tils

1 | 4

Company Internal/Proprietary Drawing Title:

Size | Document Number | Rev
Date: | Sheet | of

Page Title:

Designer:

Drawn by:

Approved:

## System Innovation

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

# X-MR-NAVQ95E-CAM

C

Thursday, January 15, 2026

## Cover

Youri Tils

Jari van Ewijk

Youri Tils

1 | 4

Company Internal/Proprietary

REF DES | ASSY_OPT | PAGE NAME
J4 | DNP | P03-CSI_to_RPi

DNP Table; Drawing Title:; Size; Document Number; Rev; Date:; Sheet; Page Title:; Classification:; SCH-96100 PDF: SPF-96100; X-MR-NAVQ95E-CAM; Thursday, January 15, 2026; Notes; Company Internal

## Layout note: put 5V silkscreen next to pin 1


MIPI differential impedance: 100 Ohm

CONN FPC/FFC 22
SILK = FFC CONTACTS AWAY FROM PCB

Rev.

# Initial schematic development and format changes

Changelog; Description; Date; YT (CTO SI); Fixed B2B pinout. Fixed wiring to I2C level shifter. Added filter caps at B2B voltages.; Added silkscreen to CSI connector.; Drawing Title:; Size; Document Number; Rev; Date:; Sheet; Page Title:; Classification:; SCH-96100 PDF: SPF-96100; X-MR-NAVQ95E-CAM; Thursday, January 15, 2026; Company Internal

Changed 2.21k resistors to 2.2k2025-09-16

YT (CTO SI)

Added 1x3 pin header for 5V display power.
Added TVS protection at 5V dipslay connector.
Added 0R resistors in series with I2C.
Added test points to unused B2B pins.
Removed 10uF at 3V3 CSI connector and added
feedthrough cap. Moved 0R in series with 3V3 to
CSI connector to before the 100nF cap.

Updated silkscreen at 5V connector.

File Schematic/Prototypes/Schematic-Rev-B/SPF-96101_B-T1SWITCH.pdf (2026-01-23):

5

4

3

2

1

D | D
C | C
B | B
A | A

# Table of Contents

# P01 Cover P02 Notes P03 ETH_POWER_PF5103 P04 ETH_SJA1110_SUPPLY P05 ETH_SJA1110_DATA P06 ETH_100BASET1_MDIs P07 ETH_TJA1120_1 P08 ETH_TJA1120_2 P09 ETH_B2B

By

# YT (CTO SI) Schematic is released Description

2025-09-29A

# Rev. Date

# Revision History

2. Device type number is for reference only. The number varies with the manufacturer.

# 5. Interpret diagram in accordance with American National Standards Institute specifications, current

revision, with the exception of logic block symbology.

# NOTES:

# 4. Special signal usage:

# 3. Greyed out components indicate

Do Not Populate (DNP) during assembly.

_P and _N denote a differential signal.

# 6. All SILK display properties will be in this color

_B denotes an active-low signal.

# 1. Interrupted lines coded with the same letter or

letter combinations are electrically connected.

# 7. All schematic annotations will be in this color

# X-MR-NAVQ95E-T1S

X0-X9 | 2025-09-11 | YT (CTO SI) | Initial schematic development and format changes

# ChangelogP10

Schematic revisionBX1-2 | 2025-09-29 | YT (CTO SI)
YT (CTO SI) | Schematic is releasedB | 2026-01-15

Drawing Title:

Size | Document Number | Rev
Date: | Sheet | of

Page Title:

Designer:

Drawn by:

Approved:

## System Innovation

High Tech Campus 60
5656 AG Eindhoven, The Netherlands This document contains information proprietary to NXP and shall not be used for engineering design, procurement or manufacture in whole or in part without the express written permission of NXP Semiconductors.
© | Classification:NXP SEMICONDUCTORS
SCH-96101 PDF: SPF-96101 | B

# X-MR-NAVQ95E-T1S

C

Friday, January 16, 2026

## Cover

Youri Tils

Jari van Ewijk

Youri Tils

1 | 10

Company Internal/Proprietary Drawing Title:

Size | Document Number | Rev
Date: | Sheet | of

Page Title:

Designer:

Drawn by:

Approved:

## System Innovation

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

# X-MR-NAVQ95E-T1S

C

Friday, January 16, 2026

## Cover

Youri Tils

Jari van Ewijk

Youri Tils

1 | 10

Company Internal/Proprietary Drawing Title:

Size | Document Number | Rev
Date: | Sheet | of

Page Title:

Designer:

Drawn by:

Approved:

## System Innovation

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

# X-MR-NAVQ95E-T1S

C

Friday, January 16, 2026
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

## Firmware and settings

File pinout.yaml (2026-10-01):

# Pinout data for the MR-NAVQ95 hardware reference. The cards, photos and tables are generated from this file.

meta:
  title: MR-NAVQ95 hardware reference
  short_title: MR-NAVQ95
  soc: i.MX95
  main_schematic:
    file: SPF-97010_A1-MAIN.pdf
    rev: A1
    url: https://github.com/NXP-Robotics/MR-NAVQ95/blob/main/Schematic/SPF-97010_A1-MAIN.pdf
  io_schematic:
    file: SPF-97013_A1-IO.pdf
    rev: A1
    url: https://github.com/NXP-Robotics/MR-NAVQ95/blob/main/Schematic/SPF-97013_A1-IO.pdf

categories:
  vin:   {label: "VIN 9-52 V",      fill: "#8b1a1a", dark: "#f85149"}
  5v:    {label: "5 V",             fill: "#d1242f", dark: "#ff7b72"}
  3v3:   {label: "3.3 V",           fill: "#bc4c00", dark: "#f0883e"}
  gnd:   {label: "GND",             fill: "#1f2328", dark: "#6e7681"}
  uart:  {label: "UART",            fill: "#0969da", dark: "#58a6ff"}
  i2c:   {label: "I2C",             fill: "#8250df", dark: "#bc8cff"}
  spi:   {label: "SPI",             fill: "#1a7f37", dark: "#3fb950"}
  pwm:   {label: "PWM / timer",     fill: "#9a6700", dark: "#d29922"}
  can:   {label: "CAN FD",          fill: "#0a7c86", dark: "#39c5cf"}
  usb:   {label: "USB",             fill: "#a40e6b", dark: "#f778ba"}
  eth:   {label: "Ethernet",        fill: "#116329", dark: "#56d364"}
  pcie:  {label: "PCIe / M.2",      fill: "#3b3b8f", dark: "#a5b4fc"}
  debug: {label: "SWD / JTAG",      fill: "#57606a", dark: "#8b949e"}
  boot:  {label: "Boot mode",       fill: "#bf3989", dark: "#f778ba"}
  gpio:  {label: "GPIO / misc",     fill: "#6e7781", dark: "#8b949e"}
  adc:   {label: "Analog",          fill: "#bf3989", dark: "#ff9bce"}
  audio: {label: "Audio",           fill: "#7d4e00", dark: "#e3b341"}
  mipi:  {label: "MIPI CSI",        fill: "#4d2d91", dark: "#a78bfa"}
  nc:    {label: "NC / key",        fill: "#eaeef2", dark: "#30363d", text: "#57606a"}
boards:
  main: {name: "Main board (NAVQ95-MAIN)", short: Main, tag: "main board"}
  io:   {name: "IO expansion board (NAVQ95-IO)", short: IO, tag: "IO board"}
  cam:  {name: "Camera expansion board (NAVQ95-CAMRP), one per CSI port", short: CAM, tag: "CAM board"}
  t1s:  {name: "T1 Ethernet switch board (NAVQ95-T1SW)", short: T1S, tag: "T1 switch board", others_title: "T1S ports and headers"}

overviews:
  top:
    photo: NAVQ95_TOP.JPG
    crop: [0.14, 0.03, 0.83, 0.97]      # board outline within the photo (fractions of the full photo)
    max_px: 1100
    alt: "MR-NAVQ95 top view with connector callouts"
    callouts:
      - {conn: main/J9,  x: 0.188, y: 0.140, side: left}
      - {conn: main/J8,  x: 0.210, y: 0.505, side: left}
      - {conn: io/J7,   x: 0.265, y: 0.665, side: left}
      - {conn: io/J6,   x: 0.344, y: 0.665, side: left}
      - {conn: io/SW1,   x: 0.268, y: 0.747, side: left}
      - {conn: io/J9,   x: 0.170, y: 0.765, side: left}
      - {conn: io/S1,  x: 0.254, y: 0.803, side: left}
      - {conn: io/J8,   x: 0.258, y: 0.922, side: left}
      - {conn: io/J5,    x: 0.355, y: 0.922, side: bottom}
      - {conn: io/J4,    x: 0.428, y: 0.922, side: bottom}
      - {conn: io/J3,    x: 0.501, y: 0.922, side: bottom}
      - {conn: io/J1,   x: 0.580, y: 0.917, side: right}
      - {conn: main/SW3, x: 0.672, y: 0.070, side: top}
      - {conn: main/SW1, x: 0.706, y: 0.068, side: top}
      - {conn: main/J1,  x: 0.748, y: 0.822, side: right}
      - {conn: io/J2,   x: 0.615, y: 0.617, side: right}
      - {conn: main/J2,  x: 0.705, y: 0.897, side: right}
      - {conn: main/J13, hidden: "bottom view"}
      - {conn: main/J12, hidden: "bottom view"}
      - {conn: main/J16, hidden: "bottom and front view"}
      - {conn: main/J7,  hidden: "front view"}
      - {conn: main/J6,  hidden: "front view"}
      - {conn: main/J11, hidden: "not visible in the photos"}
      - {conn: main/SW2, hidden: "top side, under the M.2 Key M module"}
  side:
    photo: NAVQ95_SIDE3.JPG
    crop: [0.0, 0.24, 1.0, 0.74]        # front edge: IO board connectors plus the main board's bottom-edge parts
    max_px: 1200
    alt: "MR-NAVQ95 front view: IO board connectors, debug header, microSD and audio jack"
    callouts:
      - {conn: main/J9,  x: 0.064, y: 0.323, side: left}
      - {conn: main/J8,  x: 0.164, y: 0.380, side: left}
      - {conn: io/J9,   x: 0.189, y: 0.493, side: left}
      - {conn: io/J7,   x: 0.279, y: 0.432, side: top}
      - {conn: io/J6,   x: 0.364, y: 0.418, side: top}
      - {conn: io/J2,   x: 0.632, y: 0.337, side: top}
      - {conn: io/J8,   x: 0.343, y: 0.541, side: bottom}
      - {conn: io/J5,    x: 0.457, y: 0.517, side: bottom}
      - {conn: io/J4,    x: 0.543, y: 0.498, side: bottom}
      - {conn: io/J3,    x: 0.629, y: 0.479, side: bottom}
      - {conn: main/J7,  x: 0.336, y: 0.626, side: bottom}
      - {conn: main/J6,  x: 0.471, y: 0.617, side: bottom}
      - {conn: io/J12,   x: 0.589, y: 0.560, side: bottom}
      - {conn: main/J5,  x: 0.607, y: 0.597, side: bottom}
      - {conn: main/J16, x: 0.686, y: 0.626, side: bottom}
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

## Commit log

2025-11-21 Added board design files
    Added design export for:
    1. NavQ95 mainboard V2 (aka Rev B)
    2. NavQ95 IO expansion board
    3. NavQ95 Camera expansion board
    4. NavQ95 T1 switch expansion board
    5. NavQ95 T1 phy expansion board
    [BOM-95869_A.xlsx, BOM-96098_A.xlsx, BOM-96099_A.xlsx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]
2026-01-23 Added schematic deisgn file for 3 changed expansion boards: IO, T1 Switch and Camera.
    [BOM-95869_A.xlsx, BOM-96098_A.xlsx, BOM-96099_A.xlsx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]
2026-01-23 Removed Rev A design files from previous location
    [BOM-95869_A.xlsx, BOM-96098_A.xlsx, BOM-96099_A.xlsx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]
2026-09-18 Update NavQ95 schematics and design files for Rev. A1 (production version)
    [BOM-95869_A.xlsx, BOM-96098_A.xlsx, BOM-96099_A.xlsx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]
2026-10-01 Add connector references
2026-10-20 Update README.md
    Show NavQ95 as a supported board from NXP instead of proof of concept
2026-10-26 Update board photos, tidy overview callouts, fix connector data
    Replace the top and front photos with new production-board shots
    (NAVQ95_TOP.JPG cropped to the board at 3864 px wide to match
    NAVQ95_SIDE2.JPG). Re-place the overview callouts on the new photos and
    spread them over all four sides so no lines cross; SW2 BTMODE is now
    visible in the top view.
    Connector data checked against the Rev. A1 schematics: IO J2 SPKR pins 1
    and 2 are Left + / Left -, main J9 PWR_IN pin 2 is VSS_BAT, notes use the
    A1 designators, T1 switch connectors get schematic page numbers.
    Regenerated cards, README blocks and both PDFs with the current template.
